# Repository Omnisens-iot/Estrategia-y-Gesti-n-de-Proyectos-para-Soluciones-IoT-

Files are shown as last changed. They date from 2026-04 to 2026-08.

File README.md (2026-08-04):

(https://postimg.cc/2VrdBDD4)

## Omnisens-Industrial Suite ##

OmniSens es un sistema orientado al monitoreo y control ambiental en entornos industriales. Utiliza sensores para medir variables críticas como temperatura, humedad, presión y luminosidad, y transmite estos datos mediante tecnología LoRa hacia un servidor en la nube, permitiendo monitoreo y gestión en tiempo real.

corte_modelo

🧑‍💻 Integrantes

| Nombre | GitHub |
|---|---|
| Fernando Gimenez Coria | [@FerCbr](https://github.com/FerCbr) |
| Paola Pantoja | [@PaolaaPantoja](https://github.com/PaolaaPantoja) |
| Diego Ares | [@diegote7](https://github.com/diegote7) |
| Macarena Aylèn Carballo | [@MacarenaAC](https://github.com/MacarenaAC) |
| Raul Jara | [@r-j28](https://github.com/r-j28) |
---
## Descripción General

El objetivo principal de OmniSens es implementar un sistema integral capaz de mantener condiciones óptimas de ambiente, garantizando la seguridad y calidad del aire. Para ello, el sistema incluye una serie de **controladores edge** que reciben los datos de los sensores y accionan dispositivos como extractores de aire, luces, alarmas sonoras y balizas luminosas.  
Las acciones de los controladores edge buscan regular parámetros ambientales: por ejemplo, ajustar la velocidad de extractores/ventiladores, la intensidad de luces, o activar alarmas cuando los valores de gases o variables ambientales sobrepasen los límites establecidos.

Los controladores edge se comunican mediante un enlace LoRa hacia otro controlador encargado de funcionar como **nodo concentrador**, formando una red de tipo estrella.  
Este **nodo concentrador** envia a su vez todos datos recolectados a un **broker MQTT** remoto para su posterior analisis y almacenamiento. Esta arquitectura otorga la posibilidad de implementar analisis de datos a nivel de edge, permitiendo reaccionar a variables criticas con baja latencia, sin dejar de lado el procesamiento en la nube, que se encarga de almacenar todos los sucesos y tambien enviar ordenes a los controladores Edge.   

Toda la información recolectada se analiza en un servidor remoto y es almacenada en una base de datos configurada para este fin, luego se procede a mostrar la informacion en un dashboard. Este diseño permite visualizar la informacion procesada a vez que puese enviar ordenes automaticas o comandos indicados por el usuario.

## Objetivo del Proyecto

Desarrollar un sistema capaz de:
- Monitorear variables ambientales (temperatura, humedad, presión, luminosidad, gases) en tiempo real.
- Controlar dispositivos para mantener condiciones ambientales dentro de los parámetros de seguridad y calidad.
- Automatizar acciones correctivas (ventilación, iluminación, alarmas) ante condiciones anómalas.
- Registrar, almacenar y visualizar los datos históricos y en tiempo real para facilitar la toma de decisiones.

---

## Arquitectura del Sistema  

(https://postimg.cc/HVhyV9CV)

El sistema está compuesto por:
- **Sensores ambientales**: Medición de variables críticas.  
- **Actuadores**: Dispositivos tales como Extractores/ventiladores, relay o contactores para comando on/off, balizas y alarmas sonoras
- **Microcontroladores Edge con LoRa**: Son los encargados de tomar la informacion de los sensores y procesar variables criticas que requieran baja latencia, ademas envian la informacion adquirida por enlace LoRa hacia el concentrador.
- **Concentrador Lora**: Controlador encargado de recibir los datos provenientes de los controladores Edge. Recibe la información y la envia por MQTT al **broker remoto**, ademas se encarga de ditribuir los comandos provenientes del servidor remoto hacia los **Controladores Edge** para accionar los actuadores.  
- **Servidor remoto**: Este servidor cumple las funciones de plataforma en la nube, cuenta con varios contenedores docker conectados en una red virtual. La lista de contenedores es la siguiente:  
    - **Broker MQTT**: recepcion de los datos provenientes del Edge y envio de comandos hacia los controladores edge  
    - **API**: Recibe los datos del broker MQTT y los procesa para autenticar y autorizar a los dispositivos y usuarios.  
    - **Node-red**: recibe los datos de la API y los procesa para analizar y tomar decisiones. Ademas, envía las reacciones a los actuadores a través de MQTT y almacena los datos y resultados de analisis en una base de datos.  
    - **Base de datos**: Aqui se almacena la informacion de los sensores, asi como los analisis realizados por Node-RED para su posterior visualizacion.  
    - **Grafana**: Grafana se utiliza para crear el dashboard encargado de mostrar los datos historicos y en tiempo real del sistema.
- **Interfaz web o dashboard**: Monitoreo y control centralizado.  

### Flujo de Datos

1. Los sensores captan variables ambientales.
2. Los datos viajan por LoRa a un microcontrolador concentrador, que se encarga a la vez de enviarlos por MQTT a un servidor remoto
3. El servidor analiza y devuelve ordenes para que los **Controladores Edge** accionen los actuadores.
4. El servidor almacena y muestra los datos en tiempo real, permitiendo monitoreo remoto y acciones automáticas.

---

(https://postimg.cc/BXPMk51p)

## Omnisens ##

## 🧭 1. Introducción y Problemática
**OmniSens** es un sistema de monitoreo y control ambiental industrial desarrollado por estudiantes del módulo **Estrategia y Gestión de Proyectos para Soluciones IoT**  del ISPC. Este proyecto integra tecnologías de hardware, software y comunicaciones para adquirir, almacenar, visualizar y actuar sobre datos ambientales críticos en tiempo real.

En entornos industriales, controlar variables como la **temperatura**, **humedad**, **presión atmosférica** y **luminosidad** es fundamental para garantizar la seguridad operativa, la eficiencia energética y el cumplimiento de normativas. Sin embargo, muchas industrias carecen de sistemas inteligentes que permitan:

- 📉 Monitoreo en tiempo real de las condiciones ambientales.
- ⚠️ Detección temprana de riesgos operativos.
- 📄 Registro y trazabilidad de datos históricos.
- 📊 Análisis automatizado y toma de decisiones basada en datos.
- 🚫 Evitar decisiones basadas en intuición o registros incompletos.

Ante este contexto, OmniSens surge como una solución tecnológica que permite:

Capturar datos desde sensores distribuidos mediante nodos IoT (ESP32).
Transmitir los datos a través de redes como LoRa y WiFi usando protocolos como MQTT.
Almacenarlos de forma estructurada en una base de datos relacional.
Visualizarlos y analizarlos en dashboards en tiempo real mediante herramientas como Grafana y NodeRed
Generar alertas automáticas y activar actuadores ante condiciones críticas.
El proyecto busca resolver necesidades concretas del sector industrial, promoviendo el desarrollo de competencias profesionales como la integración de sistemas embebidos, la conectividad IoT, la gestión de datos y la visualización inteligente.

Ante este contexto, **OmniSens** surge como una solución tecnológica que permite:

- Capturar datos desde sensores distribuidos mediante nodos IoT (ESP32).
- Transmitir los datos a través de redes como **LoRa** y **WiFi** usando protocolos como **MQTT**.
- Almacenarlos de forma estructurada en una base de datos relacional.
- Visualizarlos y analizarlos en dashboards en tiempo real mediante herramientas como **Grafana** y **NodeRed**
- Generar alertas automáticas y activar actuadores ante condiciones críticas.

El proyecto busca resolver necesidades concretas del sector industrial, promoviendo el desarrollo de competencias profesionales como la integración de sistemas embebidos, la conectividad IoT, la gestión de datos y la visualización inteligente.

> "OmniSens nace para transformar datos ambientales en decisiones inteligentes, aportando valor real a la industria a través de la tecnología."

## 🧱 2. Diseño de Arquitectura IoT
El sistema OmniSens está basado en una arquitectura IoT distribuida y escalable, compuesta por sensores físicos, nodos de adquisición (ESP32), un gateway central, servicios backend y plataformas de visualización. Su diseño busca asegurar confiabilidad, modularidad y bajo consumo energético.

### 🔧 Componentes principales de la arquitectura:

- **Sensores ambientales**: capturan variables como temperatura, humedad, presión y luminosidad.
- **Microcontroladores ESP32**: actúan como nodos sensores, adquiriendo y transmitiendo los datos.
- **Red de comunicación**: se utilizan tecnologías inalámbricas como **LoRa** (para distancias largas y bajo consumo) y **WiFi** (para conectividad local con el servidor).
- **Broker MQTT**: intermedia la comunicación entre nodos y backend.
- **Servidor Backend**: recibe, valida y almacena los datos en una base relacional (MySQL/MariaDB).
- **Base de datos**: registra las mediciones por timestamp, dispositivo y variable.
- **Dashboard de visualización**: mediante **Grafana** o/y **Node-Red**, permite observar en tiempo real el estado ambiental.

---
(https://postimg.cc/4HcrV1St)

### 🧩 Diagrama lógico de la arquitectura:

plaintext
[Sensores] 
    -> 
[ESP32 (Nodo Sensor)] 
    -> LoRa / WiFi 
[Gateway MQTT / Servidor] 
    -> 
[Base de Datos MySQL] 
    -> 
[Dashboard (Grafana / Power BI)]

---
## 🔧 3. Adquisición de Datos (ESP32 + Sensores)

La etapa de adquisición de datos en el sistema OmniSens se basa en la utilización de microcontroladores **ESP32**, que permiten la conexión directa con sensores ambientales y la recolección de datos físicos en tiempo real.

### 🔍 Variables monitoreadas:
- 🌡️ **Temperatura**
- 💧 **Humedad relativa**
- 🌀 **Presión atmosférica**
- 💡 **Luminosidad**
- 🕯️ **Concentracion de gases/ calidad de aire**

### 🛠️ Componentes utilizados:
- **Sensores digitales y analógicos**:
  - AHT25 → temperatura y humedad
  - BMP280 → presión y temperatura
  - LDR → luminosidad
  - MQ135 → Calidad de aire
    
- **Microcontrolador**:
  - ESP32 (con conectividad WiFi y/o LoRa)

### ⚙️ Flujo de funcionamiento:
1. Los sensores capturan datos del entorno físico.
2. El ESP32 lee las señales de los sensores a través de sus entradas GPIO.
3. El firmware del ESP32 convierte los datos a formato digital y los estructura en mensajes JSON.
4. Los datos se transmiten vía WiFi o LoRa hacia el backend o gateway.

### 🧪 Validación y pruebas realizadas:
- Lectura y calibración de cada sensor.
- Verificación del formato y frecuencia de los datos.
- Simulación de condiciones ambientales para validar variabilidad.
- Comprobación del consumo energético por nodo.

### 📌 Ventajas de usar ESP32:
- Bajo consumo energético.
- Capacidad de procesamiento local.
- Conectividad múltiple: WiFi, Bluetooth, LoRa (mediante módulos).
- Compatibilidad con entornos industriales y educativos.

> Esta etapa permite digitalizar el entorno físico y convertir condiciones ambientales en datos útiles, siendo el punto de partida del sistema de monitoreo y control de OmniSens.

---

## 📡 4. Comunicación Inalámbrica
La transmisión de datos en OmniSens se realiza mediante redes inalámbricas optimizadas para entornos industriales. Se utilizan dos tecnologías principales: **LoRa** y **WiFi**, complementadas por el protocolo **MQTT** para la mensajería entre dispositivos y el servidor.

### 🛰️ Tecnologías de comunicación utilizadas:

- **LoRa (Long Range)**:
  - Permite comunicación de largo alcance con bajo consumo energético.
  - Ideal para entornos con múltiples nodos distribuidos o con baja infraestructura de red.
  - Se utiliza principalmente entre nodos sensores y el nodo receptor (gateway).

- **WiFi**:
  - Usado en el nodo central para conectarse a internet y enviar los datos al backend.
  - Permite alta velocidad de transmisión y bajo retardo.

- **MQTT (Message Queuing Telemetry Transport)**:
  - Protocolo ligero ideal para IoT.
  - Permite que los dispositivos **publiquen** datos en un “topic” y que el servidor **se suscriba** para recibirlos.
  - Asegura eficiencia en redes de bajo ancho de banda y con múltiples dispositivos.

### 🔄 Flujo de comunicación:

[ESP32 Nodo Sensor]
  -> LoRa
[ESP32 Nodo Receptor / Gateway]
  -> MQTT sobre WiFi
[Broker MQTT]
  ->
[Servidor Backend]

---

## 🖥️ 5. Backend y Base de Datos
El backend del sistema OmniSens cumple un rol central en la recepción, validación, almacenamiento y organización de los datos ambientales enviados por los nodos sensores.

🔙 Funciones principales del backend:
Recibir datos desde los nodos mediante MQTT.
Validar formato, integridad y valores de los datos.
Registrar eventos o comandos generados por el sistema.
Almacenar toda la información en una base de datos relacional.
Exponer APIs para futuras integraciones con dashboards u otros servicios.
🗄️ Modelo de Base de Datos Relacional
Se diseñó una base de datos optimizada para registrar información ambiental por dispositivo y variable. Las tablas principales son:

| Tabla | Propósito |
|---|---|
| `devices` | Registra cada ESP32 con su ID, tipo y ubicación. |
| `sensor_data` | Almacena las mediciones de variables con timestamp. |
| `commands_log` | Guarda las acciones o respuestas generadas por el sistema (automatizaciones). |
| `alerts` *(opcional)* | Registra alertas generadas por condiciones críticas. |

#### 🔗 Relaciones entre tablas:
- `devices.device_id` → se relaciona con `sensor_data.device_id` y `commands_log.device_id`
- `sensor_data.id` → puede relacionarse con `alerts.sensor_data_id`

📈 Ventajas del diseño:
Escalable a nuevos sensores y tipos de variables.
Compatible con visualizadores como Grafana y Node-Red.
Preparado para trazabilidad, alertas y análisis histórico.
Este backend permite que los datos ambientales capturados por los sensores se conviertan en información estructurada, confiable y accesible para su posterior visualización y análisis.

📊 6. Visualización Web / Dashboard
La visualización de datos es el paso final del sistema OmniSens, donde la información almacenada en la base de datos es transformada en gráficos, paneles e indicadores comprensibles para facilitar la toma de decisiones.

📊 Integración con Node-RED y Grafana
Node-RED
Permite crear flujos lógicos para procesar, transformar y reenviar datos provenientes de sensores conectados vía MQTT.

🔧 Funcionalidades implementadas

* Recepción de datos desde ESP32 por MQTT.
* Filtrado y reenvío de datos a MariaDB.
* Reglas de control automático
* Flujo: MQTT → procesamiento → UI → actuador.
* Ruta: `/nodered_plata/ui/`: [Dashboard UI](http://telecomunicaciones.ddns.net:8080/nodered_plata/ui/#!/0)
* Incluye botones para control manual, recepción de datos, lógica de automatización.

### Grafana
* Plataforma de visualización en tiempo real, conectada directamente a la base de datos MariaDB.
* Dashboards visuales conectados a base de datos.
* Panel con temperatura, gas, humedad y estado de actuadores.
* Ruta directa:
  [Dashboard público](http://telecomunicaciones.ddns.net:8080/grafana/public-dashboards/edbcf99f6c3e44a68703f5246ecef087)

---

### 🧭 Objetivos de la visualización:
Representar variables ambientales críticas de forma clara y dinámica.
Permitir monitoreo en tiempo real de sensores distribuidos.
Detectar tendencias, anomalías o condiciones fuera de rango.
Mejorar el mantenimiento, la eficiencia energética y la seguridad operativa.
Facilitar el análisis por parte de diferentes perfiles de usuarios (técnicos, operativos, directivos).

### 🧱 Estructura del panel:
El dashboard se organiza en múltiples secciones:

1. **Vista general de variables**:
   - Temperatura, humedad, presión y luminosidad por dispositivo.
   - Estado actual, valores máximos y mínimos recientes.
2. **Medicion por eventos de valores en crudo**:
3. **Conteo de cantidad de dispositivos**:
4. **Históricos y tendencias**:
5. **Estado de sensores y actuadores**:
6. **Promedios** 
7. **Actividad de los reles**
8. **Identificador de dispositivos**

> La visualización convierte datos técnicos en información útil y clara, permitiendo interpretar el comportamiento ambiental y tomar decisiones informadas en entornos industriales.

---

## 🤖 7. Automatización y Control (Actuadores)
Además de monitorear el ambiente, el sistema OmniSens es capaz de actuar automáticamente ante condiciones críticas, gracias a la integración de actuadores controlados desde el backend o en forma autónoma por los nodos.

### ⚙️ Objetivos del control automatizado:
- Generar respuestas inmediatas ante variables fuera de rango.
- Activar dispositivos que mejoren las condiciones ambientales.
- Reducir la necesidad de intervención humana.
- Aumentar la seguridad y eficiencia operativa.

### 🔌 Tipos de actuadores posibles:

- 🌀 Ventiladores / extractores de aire.
- 💡 Luces de advertencia o balizas.
- 🔔 Alarmas sonoras.
- 💧 Válvulas o bombas de agua.
- 🌡️ Aire acondicionado o calefactores.

### 🔁 Lógica de automatización:

El sistema puede actuar de dos formas:

#### 1. **Automatización local en ESP32** (Opcional. no se implemento): 
- El ESP32 analiza el dato leído y, si supera un umbral, activa directamente el actuador conectado.
- Ejemplo: si `temperatura > 30°C`, activar ventilador.

#### 2. **Automatización centralizada desde el backend**:
- El servidor recibe los datos y decide activar o no un actuador según reglas definidas.
- Se envía un comando vía MQTT al nodo actuador correspondiente.

### 🗂️ Registro de acciones:

- Cada acción ejecutada se guarda en la tabla `commands_log`, con información como:
  - `device_id`
  - `command` (ej. "ON", "OFF")
  - `timestamp`
  - `status`

### 🧪 Validación y pruebas:

- Ensayos de latencia entre detección y acción.
- Pruebas con sensores simulados y actuadores reales.
- Comprobación de fallos: qué ocurre si el actuador no responde.

> La automatización convierte al sistema en una herramienta activa, no solo de monitoreo, sino también de respuesta inteligente ante condiciones que afectan el ambiente de trabajo.

---
## 📅 8. Cronograma y Proceso de Desarrollo

El desarrollo del proyecto OmniSens se organizó en etapas, siguiendo una planificación basada en objetivos específicos y acciones técnicas. Esto permitió avanzar de forma progresiva, validando cada componente del sistema antes de integrarlo.

### 📌 Organización por semanas

| Etapa | Objetivo principal | Acciones realizadas |
|---|---|---|
| **Etapa 1** | Diseñar la arquitectura | - Análisis de necesidades del sistema<br>- Selección de topología IoT<br>- Definición de roles: sensores, nodos, gateway, servidor<br>- Primeros diagramas de arquitectura |
| **Etapa  2** | Adquisición de datos | - Conexión de sensores al ESP32<br>- Programación de firmware básico<br>- Pruebas de lectura y calibración<br>- Validación de datos físicos |
| **Etapa  3** | Comunicación inalámbrica | - Configuración de red LoRa y WiFi<br>- Implementación de MQTT/<br>- Pruebas de transmisión nodo → servidor<br>- Ajustes de cobertura y latencia |
| **Etapa  4** | Backend y base de datos | - Diseño de la base de datos relacional<br>- Creación de APIs de recepción<br>- Almacenamiento de datos desde nodos<br>- Gestión de errores y alertas |
| **Etapa  5** | Visualización y pruebas finales | - Diseño del dashboard (Grafana / Node-Red)<br>- Conexión al backend y base de datos<br>- Visualización de datos en tiempo real<br>- Revisión, ajustes y documentación final |

### 🛠️ Metodología aplicada:

- Trabajo colaborativo entre 9 integrantes, con roles distribuidos.
- Validación continua en cada etapa (sensado, transmisión, backend, visualización).
- Uso de control de versiones (GitHub) para gestionar avances y código.
- Documentación técnica elaborada de forma simultánea al desarrollo.

### 📈 Resultados destacados:

- Se logró un sistema funcional y escalable.
- Todas las etapas del ciclo de vida de los datos fueron cubiertas: captura, transmisión, almacenamiento, análisis y visualización.
- Se presentaron avances periódicos en cada instancia del módulo FullStack IoT.

> El trabajo organizado y en equipo fue clave para alcanzar un producto sólido, demostrando competencias técnicas y metodológicas aplicadas al desarrollo de sistemas IoT reales.

---
## 💰 9. Modelo de Negocio

OmniSens adopta un modelo híbrido:

- Suscripción mensual (SaaS)
- Servicios de análisis para empresas
- Plataforma para integración con terceros

Segmentos:
- Residencial
- Corporativo (B2B)
- Gobierno / Smart Cities

---

## 🔐 Seguridad

Se implementan medidas de seguridad en múltiples niveles:

- Protección de credenciales
- Cifrado en comunicaciones (TLS/SSL)
- Autenticación en API
- Validación de datos
- Análisis de vulnerabilidades

---

## ⚠️ Gestión de Riesgos

Se identifican riesgos técnicos, operativos y de seguridad con estrategias de mitigación.

---

## 🚀 Estado del Proyecto

Actualmente en desarrollo bajo metodología ágil con backlog estructurado y tareas en ejecución.

---
## ✅ 10. Conclusión, Aplicaciones y Cierre

OmniSens es el resultado de un trabajo colaborativo y multidisciplinario que integra tecnologías de IoT, comunicaciones, desarrollo de software y análisis de datos para resolver una problemática concreta del ámbito industrial: la necesidad de monitorear y controlar variables ambientales de forma precisa y en tiempo real, optimizando el sistema, brindando soluciones reales ejecutando acciones o actividades   lo mas desatendidas y seguras posibles. 

### 🎯 Logros alcanzados:

- Desarrollo de un sistema completo y funcional.
- Integración de sensores físicos y nodos ESP32 con conectividad LoRa/WiFi.
- Implementación de un backend capaz de recibir, validar y almacenar datos.
- Construcción de dashboards interactivos para visualización en tiempo real.
- Automatización de respuestas ante condiciones críticas.
- Trabajo en equipo con documentación técnica, planificación y uso de herramientas profesionales.

### 🏭 Posibles aplicaciones reales:

- **Industria manufacturera**: monitoreo ambiental en líneas de producción.
- **Centros educativos o de investigación**: como plataforma de aprendizaje IoT.
- **Agricultura inteligente**: control ambiental en invernaderos o hidroponía.
- **Municipios**: estaciones ambientales urbanas para políticas públicas.
- **Cooperativas o pymes**: bajo costo, alta utilidad para la toma de decisiones.

### 🌱 Impacto del proyecto:

- Promueve la **conciencia ambiental industrial**.
- Desarrolla habilidades reales del perfil técnico FullStack IoT.
- Facilita la **transferencia tecnológica** a contextos locales.
- Aporta una solución escalable, replicable y con impacto social.

### 🧠 Reflexión final:

> “OmniSens no solo mide condiciones ambientales. Permite que la industria tome decisiones más inteligentes, eficientes y sostenibles. Nos permitió aplicar conocimientos concretos de arquitectura IoT, plataformas web, sistemas de control y gestión de datos, demostrando cómo la tecnología puede mejorar entornos reales.”

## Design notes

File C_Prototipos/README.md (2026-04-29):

(https://postimg.cc/BXPMk51p)

## OmniSens IoT – Sistema Orientado al Monitoreo y Control Ambiental en Entornos Industriales ##

**OmniSens** es un sistema orientado al monitoreo y control ambiental en entornos industriales. Utiliza sensores para medir variables críticas como temperatura, humedad, presión y luminosidad, y transmite estos datos mediante tecnología **LoRa** hacia un servidor en la nube, permitiendo monitoreo y gestión en tiempo real.

---

## 🧑‍💻 Integrantes

| Nombre | GitHub |
|---|---|
| Fernando Gimenez Coria | [@FerCbr](https://github.com/FerCbr) |
| Paola Pantoja | [@PaolaaPantoja](https://github.com/PaolaaPantoja) |
| Diego Ares | [@diegote7](https://github.com/diegote7) |
| Macarena Aylèn Carballo | [@MacarenaAC](https://github.com/MacarenaAC) |
| Raul Jara | [@r-j28](https://github.com/r-j28) |
---

## 👨‍🏫 Profesores

| Nombre | GitHub |
|---|---|
| Mario Gonzalez | [@mariogonzalezispc](https://github.com/mariogonzalezispc) |
| Ana Farias | |
| Dante Violi | |
| Alejandro DI Marco | |

## Descripción General

El objetivo principal de OmniSens es implementar un sistema integral capaz de mantener condiciones óptimas de ambiente, garantizando la seguridad y calidad del aire. Para ello, el sistema incluye una serie de **controladores edge** que reciben los datos de los sensores y accionan dispositivos como extractores de aire, luces, alarmas sonoras y balizas luminosas.  
Las acciones de los controladores edge buscan regular parámetros ambientales: por ejemplo, ajustar la velocidad de extractores/ventiladores, la intensidad de luces, o activar alarmas cuando los valores de gases o variables ambientales sobrepasen los límites establecidos.

Los controladores edge se comunican mediante un enlace LoRa hacia otro controlador encargado de funcionar como **nodo concentrador**, formando una red de tipo estrella.  
Este **nodo concentrador** envia a su vez todos datos recolectados a un **broker MQTT** remoto para su posterior analisis y almacenamiento. Esta arquitectura otorga la posibilidad de implementar analisis de datos a nivel de edge, permitiendo reaccionar a variables criticas con baja latencia, sin dejar de lado el procesamiento en la nube, que se encarga de almacenar todos los sucesos y tambien enviar ordenes a los controladores Edge.   

Toda la información recolectada se analiza en un servidor remoto y es almacenada en una base de datos configurada para este fin, luego se procede a mostrar la informacion en un dashboard. Este diseño permite visualizar la informacion procesada a su vez que puede enviar ordenes automaticas o comandos indicados por el usuario.

El proyecto busca aprovechar prototipos y desarrollos previos, adaptando y escalando el enfoque hacia la gestión ambiental industrial. Además, se promueve el trabajo colaborativo y la comunicación de avances con los profesores para su evaluación.

---
## 🧭 1. Introducción y Problemática

**OmniSens** es un sistema de monitoreo y control ambiental industrial desarrollado por estudiantes del módulo **Programador FullStack IoT** del ISPC. Este proyecto integra tecnologías de hardware, software y comunicaciones para adquirir, almacenar, visualizar y actuar sobre datos ambientales críticos en tiempo real.

En entornos industriales, controlar variables como la **temperatura**, **humedad**, **presión atmosférica** y **luminosidad** es fundamental para garantizar la seguridad operativa, la eficiencia energética y el cumplimiento de normativas. Sin embargo, muchas industrias carecen de sistemas inteligentes que permitan:

- 📉 Monitoreo en tiempo real de las condiciones ambientales.
- ⚠️ Detección temprana de riesgos operativos.
- 📄 Registro y trazabilidad de datos históricos.
- 📊 Análisis automatizado y toma de decisiones basada en datos.
- 🚫 Evitar decisiones basadas en intuición o registros incompletos.

Ante este contexto, **OmniSens** surge como una solución tecnológica que permite:

- Capturar datos desde sensores distribuidos mediante nodos IoT (ESP32).
- Transmitir los datos a través de redes como **LoRa** y **WiFi** usando protocolos como **MQTT**.
- Almacenarlos de forma estructurada en una base de datos relacional.
- Visualizarlos y analizarlos en dashboards en tiempo real mediante herramientas como **Grafana** y **NodeRed**
- Generar alertas automáticas y activar actuadores ante condiciones críticas.

El proyecto busca resolver necesidades concretas del sector industrial, promoviendo el desarrollo de competencias profesionales como la integración de sistemas embebidos, la conectividad IoT, la gestión de datos y la visualización inteligente.

> "OmniSens nace para transformar datos ambientales en decisiones inteligentes, aportando valor real a la industria a través de la tecnología."

---
## 🧱 2. Diseño de Arquitectura IoT

El sistema OmniSens está basado en una arquitectura IoT distribuida y escalable, compuesta por sensores físicos, nodos de adquisición (ESP32), un gateway central, servicios backend y plataformas de visualización. Su diseño busca asegurar confiabilidad, modularidad y bajo consumo energético.

### 🔧 Componentes principales de la arquitectura:

- **Sensores ambientales**: capturan variables como temperatura, humedad, presión y luminosidad.
- **Microcontroladores ESP32**: actúan como nodos sensores, adquiriendo y transmitiendo los datos.
- **Red de comunicación**: se utilizan tecnologías inalámbricas como **LoRa** (para distancias largas y bajo consumo) y **WiFi** (para conectividad local con el servidor).
- **Broker MQTT**: intermedia la comunicación entre nodos y backend.
- **Servidor Backend**: recibe, valida y almacena los datos en una base relacional (MySQL/MariaDB).
- **Base de datos**: registra las mediciones por timestamp, dispositivo y variable.
- **Dashboard de visualización**: mediante **Grafana** o/y **Node-Red**, permite observar en tiempo real el estado ambiental.

---
### 🧩 Diagrama lógico de la arquitectura:

plaintext
[Sensores] 
    ↓ 
[ESP32 (Nodo Sensor)] 
    ↓ LoRa / WiFi 
[Gateway MQTT / Servidor] 
    ↓ 
[Base de Datos MySQL] 
    ↓ 
[Dashboard (Grafana / Power BI)]

---
## 🔧 3. Adquisición de Datos (ESP32 + Sensores)

La etapa de adquisición de datos en el sistema OmniSens se basa en la utilización de microcontroladores **ESP32**, que permiten la conexión directa con sensores ambientales y la recolección de datos físicos en tiempo real.

### 🔍 Variables monitoreadas:
- 🌡️ **Temperatura**
- 💧 **Humedad relativa**
- 🌀 **Presión atmosférica**
- 💡 **Luminosidad**

### 🛠️ Componentes utilizados:
- **Sensores digitales y analógicos**:
  - DHT11 → temperatura y humedad
  - BMP280 → presión
  - BH1750 → luminosidad
- **Microcontrolador**:
  - ESP32 (con conectividad WiFi y/o LoRa)

### ⚙️ Flujo de funcionamiento:
1. Los sensores capturan datos del entorno físico.
2. El ESP32 lee las señales de los sensores a través de sus entradas GPIO.
3. El firmware del ESP32 convierte los datos a formato digital y los estructura en mensajes JSON.
4. Los datos se transmiten vía WiFi o LoRa hacia el backend o gateway.

### 🧪 Validación y pruebas realizadas:
- Lectura y calibración de cada sensor.
- Verificación del formato y frecuencia de los datos.
- Simulación de condiciones ambientales para validar variabilidad.
- Comprobación del consumo energético por nodo.

### 📌 Ventajas de usar ESP32:
- Bajo consumo energético.
- Capacidad de procesamiento local.
- Conectividad múltiple: WiFi, Bluetooth, LoRa (mediante módulos).
- Compatibilidad con entornos industriales y educativos.

> Esta etapa permite digitalizar el entorno físico y convertir condiciones ambientales en datos útiles, siendo el punto de partida del sistema de monitoreo y control de OmniSens.

---
## 📡 4. Comunicación Inalámbrica

La transmisión de datos en OmniSens se realiza mediante redes inalámbricas optimizadas para entornos industriales. Se utilizan dos tecnologías principales: **LoRa** y **WiFi**, complementadas por el protocolo **MQTT** para la mensajería entre dispositivos y el servidor.

### 🛰️ Tecnologías de comunicación utilizadas:

- **LoRa (Long Range)**:
  - Permite comunicación de largo alcance con bajo consumo energético.
  - Ideal para entornos con múltiples nodos distribuidos o con baja infraestructura de red.
  - Se utiliza principalmente entre nodos sensores y el nodo receptor (gateway).

- **WiFi**:
  - Usado en el nodo central para conectarse a internet y enviar los datos al backend.
  - Permite alta velocidad de transmisión y bajo retardo.

- **MQTT (Message Queuing Telemetry Transport)**:
  - Protocolo ligero ideal para IoT.
  - Permite que los dispositivos **publiquen** datos en un “topic” y que el servidor **se suscriba** para recibirlos.
  - Asegura eficiencia en redes de bajo ancho de banda y con múltiples dispositivos.

### 🔄 Flujo de comunicación:

plaintext
[ESP32 Nodo Sensor]
  ↓ LoRa
[ESP32 Nodo Receptor / Gateway]
  ↓ MQTT sobre WiFi
[Broker MQTT]
  ↓
[Servidor Backend]

---
## 🖥️ 5. Backend y Base de Datos

El backend del sistema OmniSens cumple un rol central en la recepción, validación, almacenamiento y organización de los datos ambientales enviados por los nodos sensores.

### 🔙 Funciones principales del backend:

- Recibir datos desde los nodos mediante HTTP o MQTT.
- Validar formato, integridad y valores de los datos.
- Registrar eventos o comandos generados por el sistema.
- Almacenar toda la información en una base de datos relacional.
- Exponer APIs para futuras integraciones con dashboards u otros servicios.

### 🧩 Arquitectura del backend:

- **Lenguaje/entorno**: Node.js
- **Servidor web/API**: Express
- **Base de datos**: MariaDB / MySQL
- **Gestión de datos**: Sequelize u ORM nativo
- **Contenedores**: Docker (opcional, según implementación)

### 🗄️ Modelo de Base de Datos Relacional

Se diseñó una base de datos optimizada para registrar información ambiental por dispositivo y variable. Las tablas principales son:

| Tabla | Propósito |
|---|---|
| `devices` | Registra cada ESP32 con su ID, tipo y ubicación. |
| `sensor_data` | Almacena las mediciones de variables con timestamp. |
| `commands_log` | Guarda las acciones o respuestas generadas por el sistema (automatizaciones). |
| `alerts` *(opcional)* | Registra alertas generadas por condiciones críticas. |

#### 🔗 Relaciones entre tablas:
- `devices.device_id` → se relaciona con `sensor_data.device_id` y `commands_log.device_id`
- `sensor_data.id` → puede relacionarse con `alerts.sensor_data_id`

### 🧪 Validaciones implementadas:

- Comprobación de rangos válidos (ej.: temperatura entre -40 °C y 85 °C).
- Eliminación de registros duplicados.
- Control de campos nulos o mal formateados.
- Registro de errores y eventos especiales.

### 📈 Ventajas del diseño:

- Escalable a nuevos sensores y tipos de variables.
- Compatible con visualizadores como Grafana y Power BI.
- Preparado para trazabilidad, alertas y análisis histórico.

> Este backend permite que los datos ambientales capturados por los sensores se conviertan en información estructurada, confiable y accesible para su posterior visualización y análisis.

---
## 📊 6. Visualización Web / Dashboard

La visualización de datos es el paso final del sistema OmniSens, donde la información almacenada en la base de datos es transformada en gráficos, paneles e indicadores comprensibles para facilitar la toma de decisiones.

## 📊 Integración con Node-RED y Grafana

### Node-RED

* Flujo: MQTT → procesamiento → UI → actuador.
* Ruta: `/nodered_plata/ui/`: [Dashboard UI](http://telecomunicaciones.ddns.net:8080/nodered_plata/ui/#!/0)
* Incluye botones para control manual, recepción de datos, lógica de automatización.

### Grafana

* Plataforma de visualización en tiempo real, conectada directamente a la base de datos MySQL.
* Dashboards visuales conectados a base de datos.
* Panel con temperatura, gas, humedad y estado de actuadores.
* Ruta directa:
  [Dashboard público](http://telecomunicaciones.ddns.net:8080/grafana/public-dashboards/edbcf99f6c3e44a68703f5246ecef087)

---

### 🧭 Objetivos de la visualización:

- Representar variables ambientales críticas de forma clara y dinámica.
- Permitir monitoreo en tiempo real de sensores distribuidos.
- Detectar tendencias, anomalías o condiciones fuera de rango.
- Mejorar el mantenimiento, la eficiencia energética y la seguridad operativa.
- Facilitar el análisis por parte de diferentes perfiles de usuarios (técnicos, operativos, directivos).

### 🧱 Estructura del panel:

El dashboard se organiza en múltiples secciones:

1. **Vista general de variables**:
   - Temperatura, humedad, presión y luminosidad por dispositivo.
   - Estado actual, valores máximos y mínimos recientes.

2. **Panel comparativo por sectores o nodos**:
   - Comparación de valores entre ubicaciones o dispositivos.

3. **Alertas y condiciones críticas**:
   - Visualización de alertas activas por umbrales excedidos.

4. **Históricos y tendencias**:
   - Gráficos de evolución temporal de cada variable.
   - Filtros por fecha, nodo o variable.

5. **Indicadores clave (KPIs)**:
   - Promedios, máximos/mínimos diarios.
   - Cantidad de alertas, condiciones óptimas mantenidas, etc.

### 🔗 Conexión de datos:

- **Grafana**: se conecta directamente a la base MySQL mediante consultas SQL configuradas por variable y tabla.
- **Power BI**: importa los datos desde MySQL o desde archivos exportados, permitiendo modelado, limpieza y relaciones personalizadas.

> La visualización convierte datos técnicos en información útil y clara, permitiendo interpretar el comportamiento ambiental y tomar decisiones informadas en entornos industriales.

---
## 🤖 7. Automatización y Control (Actuadores)

Además de monitorear el ambiente, el sistema OmniSens es capaz de **actuar automáticamente** ante condiciones críticas, gracias a la integración de actuadores controlados desde el backend o en forma autónoma por los nodos.

### ⚙️ Objetivos del control automatizado:

- Generar respuestas inmediatas ante variables fuera de rango.
- Activar dispositivos que mejoren las condiciones ambientales.
- Reducir la necesidad de intervención humana.
- Aumentar la seguridad y eficiencia operativa.

### 🔌 Tipos de actuadores posibles:

- 🌀 Ventiladores / extractores de aire.
- 💡 Luces de advertencia o balizas.
- 🔔 Alarmas sonoras.
- 💧 Válvulas o bombas de agua.
- 🌡️ Aire acondicionado o calefactores.

### 🔁 Lógica de automatización:

El sistema puede actuar de dos formas:

#### 1. **Automatización local en ESP32**:
- El ESP32 analiza el dato leído y, si supera un umbral, activa directamente el actuador conectado.
- Ejemplo: si `temperatura > 30°C`, activar ventilador.

#### 2. **Automatización centralizada desde el backend**:
- El servidor recibe los datos y decide activar o no un actuador según reglas definidas.
- Se envía un comando vía MQTT/HTTP al nodo actuador correspondiente.

### 🗂️ Registro de acciones:

- Cada acción ejecutada se guarda en la tabla `commands_log`, con información como:
  - `device_id`
  - `command` (ej. "ON", "OFF")
  - `timestamp`
  - `status`

### 🧪 Validación y pruebas:

- Ensayos de latencia entre detección y acción.
- Pruebas con sensores simulados y actuadores reales.
- Comprobación de fallos: qué ocurre si el actuador no responde.

### 🔒 Seguridad:

- Se pueden establecer reglas para evitar activaciones innecesarias.
- Control de prioridad y bloqueo si hay condiciones simultáneas.

> La automatización convierte al sistema en una herramienta activa, no solo de monitoreo, sino también de respuesta inteligente ante condiciones que afectan el ambiente de trabajo.

---
## 📅 8. Cronograma y Proceso de Desarrollo

El desarrollo del proyecto OmniSens se organizó en etapas semanales, siguiendo una planificación basada en objetivos específicos y acciones técnicas. Esto permitió avanzar de forma progresiva, validando cada componente del sistema antes de integrarlo.

### 📌 Organización por semanas

| Semana | Objetivo principal | Acciones realizadas |
|---|---|---|
| **Semana 1** | Diseñar la arquitectura | - Análisis de necesidades del sistema<br>- Selección de topología IoT<br>- Definición de roles: sensores, nodos, gateway, servidor<br>- Primeros diagramas de arquitectura |
| **Semana 2** | Adquisición de datos | - Conexión de sensores al ESP32<br>- Programación de firmware básico<br>- Pruebas de lectura y calibración<br>- Validación de datos físicos |
| **Semana 3** | Comunicación inalámbrica | - Configuración de red LoRa y WiFi<br>- Implementación de MQTT/HTTP<br>- Pruebas de transmisión nodo → servidor<br>- Ajustes de cobertura y latencia |
| **Semana 4** | Backend y base de datos | - Diseño de la base de datos relacional<br>- Creación de APIs de recepción<br>- Almacenamiento de datos desde nodos<br>- Gestión de errores y alertas |
| **Semana 5** | Visualización y pruebas finales | - Diseño del dashboard (Grafana / Power BI)<br>- Conexión al backend y base de datos<br>- Visualización de datos en tiempo real<br>- Revisión, ajustes y documentación final |

### 🛠️ Metodología aplicada:

- Trabajo colaborativo entre 9 integrantes, con roles distribuidos.
- Validación continua en cada etapa (sensado, transmisión, backend, visualización).
- Uso de control de versiones (GitHub) para gestionar avances y código.
- Documentación técnica elaborada de forma simultánea al desarrollo.

### 📈 Resultados destacados:

- Se logró un sistema funcional y escalable.
- Todas las etapas del ciclo de vida de los datos fueron cubiertas: captura, transmisión, almacenamiento, análisis y visualización.
- Se presentaron avances periódicos en cada instancia del módulo FullStack IoT.

> El trabajo organizado y en equipo fue clave para alcanzar un producto sólido, demostrando competencias técnicas y metodológicas aplicadas al desarrollo de sistemas IoT reales.

---
## ✅ 9. Conclusión, Aplicaciones y Cierre

OmniSens es el resultado de un trabajo colaborativo y multidisciplinario que integra tecnologías de IoT, comunicaciones, desarrollo de software y análisis de datos para resolver una problemática concreta del ámbito industrial: la necesidad de monitorear y controlar variables ambientales de forma precisa y en tiempo real.

### 🎯 Logros alcanzados:

- Desarrollo de un sistema completo y funcional.
- Integración de sensores físicos y nodos ESP32 con conectividad LoRa/WiFi.
- Implementación de un backend capaz de recibir, validar y almacenar datos.
- Construcción de dashboards interactivos para visualización en tiempo real.
- Automatización de respuestas ante condiciones críticas.
- Trabajo en equipo con documentación técnica, planificación y uso de herramientas profesionales.

### 🏭 Posibles aplicaciones reales:

- **Industria manufacturera**: monitoreo ambiental en líneas de producción.
- **Centros educativos o de investigación**: como plataforma de aprendizaje IoT.
- **Agricultura inteligente**: control ambiental en invernaderos o hidroponía.
- **Municipios**: estaciones ambientales urbanas para políticas públicas.
- **Cooperativas o pymes**: bajo costo, alta utilidad para la toma de decisiones.

### 🌱 Impacto del proyecto:

- Promueve la **conciencia ambiental industrial**.
- Desarrolla habilidades reales del perfil técnico FullStack IoT.
- Facilita la **transferencia tecnológica** a contextos locales.
- Aporta una solución escalable, replicable y con impacto social.

### 🧠 Reflexión final:

> “OmniSens no solo mide condiciones ambientales. Permite que la industria tome decisiones más inteligentes, eficientes y sostenibles. Nos permitió aplicar conocimientos concretos de arquitectura IoT, plataformas web, sistemas de control y gestión de datos, demostrando cómo la tecnología puede mejorar entornos reales.”

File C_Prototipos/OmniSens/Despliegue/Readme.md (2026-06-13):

# 🚀 Guía de Despliegue Paso a Paso (Nube Híbrida) - OmniSens

Esta guía describe el procedimiento detallado para transferir los archivos de orquestación desde tu computadora local hacia la **Raspberry Pi (Nodo de Control)** y posteriormente ejecutar el despliegue automatizado en la **Netbook Atom (Servidor Local)** y en la **instancia EC2 de AWS (Servidor en la Nube)**.

---

## 🗺️ Arquitectura de Despliegue Híbrido

```mermaid
graph TD
    PC[PC de Desarrollo (Local)] -->|1. Transferir Archivos (SCP)| RPi[Raspberry Pi (Nodo de Control con Ansible)]
    RPi -->|2. Despliegue local (SSH)| Netbook[Netbook Atom (Servidor Local - Red Interna)]
    RPi -->|3. Despliegue nube (SSH + PEM)| AWS[AWS EC2 (Servidor de Producción en Nube)]
```

---

## 📋 Requisitos Previos

Antes de comenzar, asegúrate de contar con:
1. La clave privada `.pem` de AWS en tu Raspberry Pi (o lista en tu PC para transferirla).
2. Los accesos SSH habilitados tanto en la Netbook Atom como en la instancia EC2.
3. Ansible instalado en la Raspberry Pi.

---

## 🛠️ Paso a Paso del Despliegue

### Paso 1: Copiar los Archivos de Despliegue a la Raspberry Pi
Debido a que estás trabajando en tu PC local, debes transferir la carpeta de despliegue (`Despliegue/`) y la carpeta de configuraciones de Nginx (`configuraciones/`) a la Raspberry Pi.

Abre una terminal (PowerShell o Git Bash) en tu PC local en la raíz del proyecto `OmniSens/` y ejecuta el comando `scp`:

```bash
# Copia ambas carpetas al home del usuario 'pi' en la Raspberry Pi
# (Reemplaza <IP_RASPBERRY> con la dirección IP real de tu Raspberry Pi)
scp -r Despliegue/ configuraciones/ pi@<IP_RASPBERRY>:/home/pi/omnisens_deploy/
```

> [!TIP]
> Si tu clave `.pem` de AWS está en la PC local, aprovecha para enviarla también a la Raspberry Pi:
> `scp ruta/de/tu/clave.pem pi@<IP_RASPBERRY>:/home/pi/.ssh/omnisens-aws.pem`

---

### Paso 2: Conectarse y Configurar la Raspberry Pi
Conéctate por SSH a la Raspberry Pi:
```bash
ssh pi@<IP_RASPBERRY>
cd /home/pi/omnisens_deploy/Despliegue/
```

Si aún no tienes la clave `.pem` en la ubicación correcta o con los permisos adecuados en la Pi, ejecuta:
```bash
# Mover la llave y ajustar permisos para que SSH la acepte
chmod 400 /home/pi/.ssh/omnisens-aws.pem
```

---

### Paso 3: Configurar el Inventario (`inventory.ini`)
Abre el archivo de inventario en la Raspberry Pi para editarlo (por ejemplo, con `nano inventory.ini`) y completa las direcciones IP reales:

```ini
[nodos_atom]
# Servidor local
netbook_local ansible_host=<IP_NETBOOK_LOCAL> ansible_user=fernandogc

[nodos_aws]
# Servidor en la nube
aws_ec2 ansible_host=<IP_PUBLICA_AWS> ansible_user=ubuntu ansible_ssh_private_key_file=/home/pi/.ssh/omnisens-aws.pem
```

> [!NOTE]
> Si la instancia de AWS corre **Amazon Linux 2 / RHEL** en lugar de **Ubuntu**, debes cambiar `ansible_user=ubuntu` por `ansible_user=ec2-user`.

---

### Paso 4: Validar Conectividad desde Ansible
Antes de desplegar, verifica que la Raspberry Pi pueda comunicarse mediante Ansible con ambos servidores:

```bash
# Realiza un ping de Ansible a todos los nodos del inventario
ansible -i inventory.ini all -m ping
```
*Si todo está bien, deberías ver una respuesta en color verde (`SUCCESS`) para ambos nodos.*

---

### Paso 5: Ejecutar el Playbook de Despliegue
Ejecuta el despliegue automático. Este comando aprovisionará la instancia de AWS (instalando Docker, Compose y Git) y luego compilará/levantará el stack en ambos entornos:

```bash
ansible-playbook -i inventory.ini deploy_aqi.yml
```

---

## 🔍 Paso 6: Verificación de los Microservicios

### En el Entorno Local (Netbook Atom)
1. Conéctate a la netbook y verifica que los contenedores estén corriendo:
   ```bash
   docker ps
   ```
2. Asegúrate de que la red externa `omni_agro_omnisens_net` esté activa y contenga los contenedores:
   ```bash
   docker network inspect omni_agro_omnisens_net
   ```
3. El frontend de la netbook no expone puertos externos al host, por lo que el tráfico web debe ingresar a través de tu Nginx Maestro en el puerto `80/443` utilizando la plantilla `configuraciones/aqi.conf.j2`.

### En el Entorno de AWS
1. Conéctate a la instancia de AWS y confirma los contenedores:
   ```bash
   docker ps
   ```
   *Deberías ver los puertos expuestos (ej. `0.0.0.0:80->80/tcp` para el frontend y los puertos de EMQX).*
2. Abre tu navegador y accede al Dashboard ingresando la IP pública de AWS:
   `http://<IP_PUBLICA_AWS>`
3. Verifica el acceso al panel de administración de EMQX:
   `http://<IP_PUBLICA_AWS>:18083` (Usuario por defecto: `admin` / Clave: `public`).

---
> [!IMPORTANT]
> **Seguridad en AWS:** Asegúrate de abrir los puertos de entrada (`80`, `1883`, `8883` y `18083` para administración) en el **Security Group (Grupo de Seguridad)** asociado a tu instancia EC2 en la consola de AWS para permitir las conexiones externas.

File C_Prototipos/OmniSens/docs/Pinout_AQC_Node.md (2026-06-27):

# Documentación de Hardware: Asignación de Pines (Pinout)
**Dispositivo:** Nodo OmniSens AQC (Air Quality & Control)
**Microcontrolador:** ESP32 (WROOM-32)

Este documento detalla la asignación de puertos GPIO (General Purpose Input/Output) configurada en el firmware base (`main.cpp`) para conectar todos los sensores y actuadores físicos del Nodo AQC.

---

## 1. Bus I2C (Sensores Digitales)
El bus I2C está configurado en los pines estándar del ESP32. Todos los siguientes sensores deben conectarse en paralelo a estos dos pines, utilizando la alimentación correspondiente (generalmente 3.3V).

| Función | ESP32 GPIO | Sensores Conectados en el Bus |
| :--- | :---: | :--- |
| **SDA (Data)** | **GPIO 21** | AHT25, BMP280, BH1750 |
| **SCL (Clock)**| **GPIO 22** | AHT25, BMP280, BH1750 |

---

## 2. Entradas Analógicas (Sensores ADC)
Los siguientes sensores analógicos deben conectarse a los pines ADC (Conversor Analógico a Digital) del ESP32. Todos los pines seleccionados (`34`, `35`, `36`, `39`) son seguros para lectura analógica y no interfieren con el arranque del módulo (WiFi/Boot).

| Sensor / Función | ESP32 GPIO | Etiqueta en Placa | Notas |
| :--- | :---: | :---: | :--- |
| **LDR** (Fotorresistencia) | **GPIO 36** | `VP` / `SENSOR_VP` | **Topología recomendada para 0dB (0 a 1V):** `3.3V` -> **Resistencia 22kΩ** -> `[Nodo GPIO 36]` -> **LDR en paralelo con Resistencia 10kΩ** -> `GND`. Esto asegura que el pin jamás supere 1.03V en oscuridad total y baje a ~0V en luz plena. |
| **MQ-135** (Calidad de Aire) | **GPIO 39** | `VN` / `SENSOR_VN` | **Conexión Directa con Protección:** Dado que el módulo tiene un RL de 1kΩ, su salida (AOUT) será de milivoltios. **NO usar divisor resistivo**. Conectar `AOUT` -> **Resistencia 10kΩ en serie** -> `GPIO 39`. (La resistencia de 10kΩ protege al ESP32 por si el sensor falla y saca 5V). |
| **Sharp PM10** (AOUT) | **GPIO 34** | `34` | Salida del sensor óptico. Divisor resistivo recomendado: **33kΩ + 5.6kΩ** (aprox. 39kΩ) y 10kΩ GND. |
| **Monitor de Batería** | **GPIO 35** | `35` | Divisor para 4.2V a <1V (0dB). Resistencias usadas: **22kΩ + 5.6kΩ** (aprox. 27kΩ) hacia BAT, 10kΩ GND. |

---

## 3. Salidas Digitales / Actuadores
Estos pines están configurados como salidas para controlar hardware de potencia (mediante relés o transistores).

| Componente | ESP32 GPIO | Etiqueta | Función |
| :--- | :---: | :---: | :--- |
| **Relé 1** | **GPIO 33** | `33` | Control digital (ON/OFF) de potencia. |
| **Relé 2** | **GPIO 25** | `25` | Control digital (ON/OFF) de potencia. |
| **Salida PWM** | **GPIO 32** | `32` | Control de velocidad variable (ej. Actuador externo, dimer). Controlable desde la plataforma. |
| **Sharp PM10** (ILED) | **GPIO 4** | `4` | Salida digital para pulsar el LED infrarrojo del sensor de polvo. |
| **Sharp PM10** (Ventilador) | **GPIO 27** | `27` | Salida PWM dedicada para el forzador de aire del tubo del sensor. Se activa automáticamente antes de cada lectura. |

---

## 4. Pines de Sistema (Integrados)
Pines reservados para la interacción básica con la placa física y la red.

| Función | ESP32 GPIO | Notas |
| :--- | :---: | :--- |
| **Botón BOOT** | **GPIO 0** | Integrado en la placa. Mantener presionado por >3 seg. para lanzar el Portal Cautivo WiFi. |
| **LED de Estado** | **GPIO 2** | Integrado en la placa. Usado para indicar conexión (Parpadeo) y modo de red. |

---

## 5. Expansión Futura (Comunicaciones LoRa)
De cara a futuras ampliaciones del hardware para implementar conectividad **LoRa/LoRaWAN**, la asignación de pines actual deja libres los puertos estándar necesarios. Se recomienda dejar previstos ambos puertos (SPI y UART) en el diseño final del PCB para permitir flexibilidad en la elección del módulo:

### Opción A: Módulo Transceptor Directo (SPI)
Módulos tipo **SX1276 / SX1278 / RFM95**. Requieren que el ESP32 controle directamente el radiofrecuencia y la modulación. Son más económicos pero requieren mayor procesamiento de firmware (librerías LoRa).
* **Pines Reservados (VSPI estándar):**
  * `GPIO 5` -> CS (Chip Select)
  * `GPIO 18` -> SCK (Clock)
  * `GPIO 19` -> MISO
  * `GPIO 23` -> MOSI
  * `GPIO 15` u otro libre -> DIO0 (Interrupción) / RST

### Opción B: Módulo Inteligente (Serial UART)
Módulos tipo **Ebyte E32 / Reyax RYLR998**. Poseen su propio microcontrolador interno que maneja la radiofrecuencia. Se comunican enviando y recibiendo comandos o datos por puerto serial. Es la **opción recomendada** para una integración más rápida y estable, ya que quita carga de procesamiento al ESP32.
* **Pines Reservados (UART2):**
  * `GPIO 16` -> RX2 (Recibe del TX del LoRa)
  * `GPIO 17` -> TX2 (Transmite al RX del LoRa)
  * Opcionalmente `GPIO 13` y `GPIO 14` para control de modos (M0/M1 o AUX en módulos Ebyte).

---

### Notas de Ensamblaje Industrial:
1. **Niveles Lógicos:** Los pines GPIO del ESP32 operan estrictamente a **3.3V**. Cualquier señal superior (como los 5V de la alimentación lógica del MQ135 o del sensor Sharp PM10) dañará el pin. Si un sensor opera en 5V y devuelve 5V en su salida de datos, debes colocar un conversor de nivel lógico o un divisor resistivo.
2. **Corriente:** Un pin GPIO del ESP32 puede entregar un máximo de 40mA (aunque se recomiendan 20mA). Nunca conectes los relés o motores directamente a los pines. Usa módulos de relés optoacoplados o transistores (MOSFET/BJT).
3. **Pines Analógicos:** Los pines 34, 35, 36 y 39 son *solo de entrada* y carecen de resistencias pull-up/pull-down internas. Asegúrate de diseñar el circuito externo (PCB) adecuadamente.

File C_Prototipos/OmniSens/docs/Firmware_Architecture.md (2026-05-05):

# Arquitectura del Firmware OmniSens (Hito 3)

Este documento detalla la estructura, flujo y componentes principales del firmware C++ (PlatformIO) ejecutado en los dispositivos Edge (ESP32) de la plataforma OmniSens.

## 1. Topología del Proyecto y Modularidad

El firmware ha sido diseñado bajo los principios de *Separation of Concerns* (Separación de Responsabilidades) y encapsulamiento OOP. En lugar de tener un archivo `main.cpp` monolítico e ilegible, la lógica está granularizada en la carpeta `lib/`:

*   **`SensorData`**: Gestiona la ingesta de los sensores físicos (MQ135, BMP280, AHT25, LDR). Su principal responsabilidad es construir el payload JSON (`populateJson`) utilizando un bloque de memoria estática (`StaticJsonDocument`) para evitar la fragmentación del Heap.
*   **`NetworkManager`**: Capsula de comunicación aislada. Resuelve el *Zero-Touch Provisioning* MQTT, escaneo WiFi asíncrono, actualizaciones remotas OTA y el procesamiento de comandos Cloud-to-Edge mediante *Callbacks*.
*   **`LedIndicator`**: Interfaz visual de usuario (Hardware UI). Administra el estado visual de la placa sin usar un solo bloqueo (`delay()`). Todo es operado con `millis()`.
*   **`SystemLogger`**: Sistema de bitácora dinámico. Permite suprimir la salida serial a demanda (vía MQTT) para ahorrar ciclos de CPU y limpiar el monitor serial en unidades de producción.

## 2. Flujo Multihilo (FreeRTOS)

El hardware ESP32 posee dos núcleos físicos. En lugar de usar `Ticker` (que ejecuta código en ISR de alta prioridad, arriesgando pánicos del kernel si se invocan métodos de red), aprovechamos la RTOS nativa:

### `TaskSensors` (Fijada al Core 1)
1.  Es la tarea pasiva del sistema. Despierta cada 5 segundos.
2.  Alimenta al Task Watchdog Timer (`esp_task_wdt_reset()`).
3.  Solicita un semáforo (`xSemaphoreTake(sensorMutex)`).
4.  Realiza la lectura I2C/Analógica de los sensores y sobrescribe el búfer JSON.
5.  Libera el semáforo y vuelve a dormir.

### `TaskNetwork` (Fijada al Core 0)
1.  Es la tarea activa y de red. Se ejecuta continuamente con micropausas (`vTaskDelay(50)`).
2.  Alimenta al Watchdog.
3.  Verifica el pin GPIO 0 para gatillar el **Portal Cautivo** a demanda.
4.  Mantiene vivo el cliente WiFi y MQTT.
5.  Si detecta información nueva generada por `TaskSensors` (y la red está conectada), pide el semáforo, publica el JSON al broker y libera el semáforo.

## 3. Seguridad y Aprovisionamiento (Zero-Touch)

Para mitigar riesgos de robo de código o extracción de binarios, **las contraseñas MQTT no se compilan en el firmware**.
El flujo inicial es el siguiente:
1.  El ESP32 arranca. El `NetworkManager` no encuentra un token criptográfico (`hmac_token`) en su partición NVS.
2.  Se conecta al broker utilizando **su propia dirección MAC** como credencial de usuario.
3.  El servidor (EMQX ACL) lo encierra en un *Sandbox*, donde lo único que tiene permitido es publicar en `aqi/provisioning/request`.
4.  El backend procesa la solicitud, calcula un hash **HMAC-SHA256** único para esa placa basándose en una llave simétrica secreta, y se lo responde en `aqi/provisioning/response/<MAC>`.
5.  El ESP32 lo recibe, lo guarda de forma persistente en NVS y se reinicia.
6.  En su próximo inicio, utiliza su MAC y el hash recibido, lo que le abre la puerta al tópico de telemetría final (`aqi/telemetry/<MAC>/data`).

## 4. Control Cloud-to-Edge (Actuadores y Config)

La placa es bi-direccional. Soporta la recepción de comandos remotos a través del broker:
*   **`aqi/commands/<MAC>/actuators`**: Al recibir un JSON (ej. `{"r1": 1, "r2": 0, "pwm": 128}`), `NetworkManager` dispara un puntero a función (*Callback*) en `main.cpp` para conmutar los relés o la salida PWM, aislando completamente a la red del hardware subyacente.
*   **`aqi/commands/<MAC>/config`**: Recibe comandos administrativos (ej. `{"debug": false}` para silenciar el `SystemLogger`).
*   **`aqi/commands/<MAC>/ota`**: Al recibir una URL, invoca nativamente al cliente HTTP para descargar y grabar la nueva versión de firmware en la partición OTA.

## 5. Resiliencia (Task Watchdog Timer)
Ambas tareas FreeRTOS deben reportarse periódicamente (cada 15 segundos) al TWDT. Si un sensor bloquea el bus I2C o la red se congela impidiendo que la tarea complete su ciclo, el perro guardián resetea el microcontrolador de forma dura.

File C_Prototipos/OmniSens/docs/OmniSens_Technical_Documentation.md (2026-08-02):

# 📑 Compendio de Documentación Técnica: Plataforma OmniSens & Edge Nodes

## 1. 🌟 Introducción y Arquitectura General del Sistema

**OmniSens** es una plataforma de Monitoreo de Calidad del Aire y Eficiencia Ambiental IoT (Internet of Things) de grado industrial/comercial. El sistema integra captura de datos de alta frecuencia en el borde (*Edge Computing*), transporte seguro de telemetría a través de protocolos optimizados (*MQTTS/WSS*), almacenamiento temporal e hidrométrico hiper-escalable (*TimescaleDB/PostgreSQL*) y una consola cliente interactiva y progresiva (*Vue 3 PWA*).

```mermaid
flowchart TD
    subgraph EDGE["Nodos de Borde (ESP32)"]
        ESP32["ESP32 Edge Node"]
        SENS["Sensores: MQ135, DHT/BME, BH1750, LDR"]
        ACT["Actuadores: Relés, PWM"]
        ESP32 --> SENS
        ESP32 --> ACT
    end

    subgraph BROKER["Broker Mensajería (EMQX)"]
        EMQX["EMQX Broker"]
        TLS["Port 8883 (MQTTS - secp256r1)"]
        WSS["Port 8084 (WSS - Let's Encrypt)"]
        EMQX --- TLS
        EMQX --- WSS
    end

    subgraph BACKEND["Servidor Aplicación (Fastify Node.js)"]
        FAST["API Fastify"]
        MQTT_ENG["Motor MQTT Ingesta"]
        RULES_ENG["Engine Anti-Spam & Reglas"]
        CRON["Planificador Reportes Telegram (JSON)"]
        FAST --- MQTT_ENG
        FAST --- RULES_ENG
        FAST --- CRON
    end

    subgraph STORAGE["Base de Datos"]
        DB[(TimescaleDB / PostgreSQL)]
    end

    subgraph CLIENTS["Canales de Salida & Clientes"]
        FRONT["Frontend Vue 3 PWA (Nginx)"]
        TELEGRAM["Bot de Telegram (JSON / Markdown)"]
        PUSH["Web Push Service (FCM/VAPID)"]
    end

    EDGE -- "MQTTS / Telemetría JSON" --> TLS
    TLS --> EMQX
    EMQX -- "Ingesta MQTT" --> MQTT_ENG
    MQTT_ENG --> DB
    MQTT_ENG --> RULES_ENG
    RULES_ENG --> PUSH
    RULES_ENG --> TELEGRAM
    CRON --> TELEGRAM
    FRONT -- "REST API / WSS" --> FAST
    FAST --> DB
```

---

## 2. 🎛️ Nodos de Borde (Firmware ESP32 Edge)

El firmware de los nodos reside en `Dispositivos/controlador_edge_v01mqtt/Omnisens_AQC`. Está estructurado en código modular C++ sobre **PlatformIO**.

### 2.1. Arquitectura Modular del Firmware (`lib/`)
* **`NetworkManager`**: Gestiona la conectividad de red. Si no existe conexión Wi-Fi almacenada en NVS, inicia el **Portal Cautivo (WiFiManager)** para configuración en caliente.
* **`MQ135Sensor`**: Manejo del sensor de gases de aire (CO2, NH3, benceno, alcohol). Implementa curva de calibración dinámica con resistencia de carga $R_0$ calculada en zona muerta ADC.
* **`AHT25Sensor` / `BMP280Sensor`**: Captura de temperatura (°C), humedad relativa (%) y presión atmosférica (hPa).
* **`BH1750Sensor` / `LDRSensor`**: Medición de iluminancia (Lux) y porcentaje de luz ambiental.
* **`DustSensor`**: Sensor óptico de partículas en suspensión ($PM_{2.5}$ / $PM_{10}$).
* **`SalidasRele` & `SalidaPWM`**: Control local de actuadores (extractores, persianas, ventilación por PWM).
* **`RulesEngine`**: Ejecución de reglas en el borde. Permite activar relés sin depender de la nube en caso de pérdida de enlace.
* **`StatusLED`**: Control de señales luminosas RGB (Modo configuración, buscando Wi-Fi, conectado, error de lectura).

### 2.2. Aprovisionamiento Seguro por MQTT (HMAC-SHA256)
El nodo no requiere almacenar contraseñas estáticas de base de datos ni tokens fijos:
1. El nodo se conecta a `aqi/provisioning/request` enviando su dirección MAC física y `timestamp`.
2. El Backend calcula una clave HMAC-SHA256 combinando el `timestamp` con la clave secreta única (`hmac_secret`) guardada en base de datos.
3. El Backend responde en `aqi/provisioning/response/{MAC}` enviando credenciales temporales MQTT para autorizar la publicación en `aqi/telemetry/{device_id}/data`.

---

## 3. 🖥️ Backend de la Nube (Fastify & Node.js)

Ubicado en la carpeta `backend/`, el backend es una API REST y un servicio de ingesta distribuido escrito en **TypeScript**.

### 3.1. Componentes Clave del Backend
* **Fastify Web Framework**: API ultrarrápida con validaciones y middleware de autenticación **JWT** (`plugins/jwt.ts`).
* **Kysely Query Builder**: Acceso a base de datos de tipo seguro (`src/config/db.ts`) conectado a PostgreSQL/TimescaleDB.
* **Motor MQTT (`src/services/mqtt.ts`)**:
  * Escucha `aqi/telemetry/+/data` para guardar lecturas en la tabla hipertabla `air_quality_data`.
  * Escucha eventos `$SYS/brokers/+/clients/+/disconnected` para detectar desconexión de hardware e informar cambio a `offline`.
  * **Sistema Anti-Spam de Reglas (Delta & State Machine)**: Mantiene un mapa en memoria (`ruleStates`). Evita el envío repetitivo de alertas notificando **únicamente en cambios de estado** (Normal $\rightarrow$ Alarma $\rightarrow$ Normal) o si ocurre una variación $\ge 10\%$ respecto a la última alerta.
* **Servicio de Notificaciones Push (`src/services/webpush.ts`)**: Emisión de alertas en tiempo real a navegadores clientes compatibles utilizando llaves VAPID.
* **Servicio de Reportes de Salud por Telegram (`src/services/healthReport.ts`)**:
  * Ejecuta una tarea programada cada 1 hora.
  * Recopila el estado de batería, intensidad de señal Wi-Fi, valores de sensores y actuadores de todos los nodos activos.
  * Formatea la información en un objeto JSON limpio y la envía como bloque de código Markdown a Telegram.

---

## 4. 🗄️ Modelo de Datos (TimescaleDB / PostgreSQL)

Las tablas principales en `aqi_db` son:

1. **`devices`**:
   * `device_id` (PK), `mac_address`, `device_name`, `client_id`, `hmac_secret`, `status`, `last_connection`, `deleted_at`.
2. **`air_quality_data` (Hipertabla TimescaleDB por `time`)**:
   * `time` (TIMESTAMPTZ), `device_id`, `pm25`, `pm10`, `co2`, `temp`, `hum`, `pres`, `l`, `lux`, `battery`, `r1`, `r2`, `pwm`.
3. **`device_rules`**:
   * `rule_id`, `device_id`, `metric`, `condition` (`>`, `<`, `==`), `threshold`, `hysteresis`, `action`, `priority`.
4. **`push_subscriptions`**:
   * `id`, `client_id`, `endpoint`, `auth`, `p256dh`, `created_at`.
5. **`system_alerts_log`**:
   * `device_id`, `alert_type`, `last_sent_at`.

---

## 5. 🌐 Consola Web (Frontend Vue 3 PWA)

Ubicada en la carpeta `frontend/`, la consola web está construida con **Vue 3, TypeScript, Chart.js / Vue-ChartJS y TailwindCSS**.

### 5.1. Vistas Principales
* **`DashboardView.vue`**: Panel principal interactivo con métricas en tiempo real, widgets visuales de calidad de aire, temperatura, humedad y control directo de relés/actuadores.
* **`AnalyticsView.vue`**: Análisis histórico de tendencias con gráficos interactivos, filtrado por rangos de fechas y exportación a CSV/PDF.
* **`DeviceManagerView.vue`**: Alta, baja, edición de parámetros y monitoreo del estado en línea de los nodos de sensores.
* **`RulesEngineView.vue`**: Interfaz de configuración de reglas y alertas personalizadas para cada métrica ambiental.
* **`LoginView.vue` / `RegisterView.vue`**: Autenticación segura y gestión de sesiones mediante tokens JWT.

---

## 6. 🚀 Infraestructura & Despliegue en Producción (AWS EC2)

El despliegue está orquestado mediante **Docker Compose** en una instancia AWS EC2.

### 6.1. Optimización para Instancias Pequeñas (t2.micro)
Debido a las limitaciones de memoria RAM de `t2.micro` (1 GB RAM), el proceso de compilación de código TypeScript (`tsc` y `vite build`) se realiza **localmente en el entorno de desarrollo**, generando:
* `frontend/dist`: Sirviendo directamente mediante Nginx.
* `backend/dist.zip`: Empaquetado y transferido por SFTP al servidor, omitiendo el consumo de compilación en la nube.

### 6.2. Arquitectura Docker Compose
* **`aqi_postgres`**: Contenedor TimescaleDB PG15.
* **`aqi_emqx`**: Broker de mensajería MQTT con puertos seguros MQTTS (8883) y WSS (8084).
* **`aqi_backend`**: Servicio Node.js corriendo la versión pre-compilada del backend (`Dockerfile.prod`).
* **`aqi_frontend`**: Servidor Nginx que maneja certificados SSL (Let's Encrypt / HTTPS), sirve los archivos estáticos de la PWA y hace Proxy Reverso hacia la APIREST del backend.

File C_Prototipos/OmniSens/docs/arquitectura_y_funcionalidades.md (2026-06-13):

# 🏗️ Arquitectura y Funcionalidades de la Plataforma OmniSens

Este documento presenta una descripción detallada de la arquitectura de sistema, flujo de datos, modelo de persistencia y estructura funcional de **OmniSens**, una plataforma de Internet de las Cosas (IoT) de grado industrial diseñada para la monitorización ambiental, automatización inteligente y gestión remota de dispositivos en tiempo real.

---

## 1. Vista General del Sistema

OmniSens emplea una topología **Edge-to-Cloud** distribuida y contenedorizada. Los datos de telemetría fluyen desde los sensores físicos en campo hasta el panel de usuario mediante una red de comunicación asíncrona segura.

```mermaid
flowchart TD
    %% Definición de estilos para mejor visualización
    classDef edge fill:#e1f5fe,stroke:#01579b,stroke-width:2px;
    classDef comm fill:#fff3e0,stroke:#e65100,stroke-width:2px;
    classDef cloud fill:#e8f5e9,stroke:#1b5e20,stroke-width:2px;
    classDef user fill:#f3e5f5,stroke:#4a148c,stroke-width:2px;

    %% Nodos de Hardware (Edge)
    subgraph e44["Capa Edge"]
        ESP32["Node ESP32 / FreeRTOS"]
        Sensors["Sensores: AHT25, BMP280, MQ135, LDR, BH1750, Sharp Dust"]
        Actuators["Actuadores: Relés, Salida PWM"]
        
        Sensors -->|"I2C / Analógico"| ESP32
        Actuators <-->|"GPIO / PWM"| ESP32
    end

    %% Capa de Transporte (MQTT Broker)
    subgraph e45["Capa de Comunicaciones"]
        EMQX["Broker EMQX / MQTTS"]
    end

    %% Capa de Backend (Persistencia y Lógica)
    subgraph e46["Capa Core Cloud"]
        Fastify["Fastify API / Node.js & TypeScript"]
        Timescale[("TimescaleDB / PostgreSQL")]
    end

    %% Capa de Frontend (Interfaz de Usuario)
    subgraph e47["Capa de Usuario"]
        VueApp["Dashboard Vue 3 / Vite & Tailwind"]
    end

    %% Relaciones y flujo de datos
    ESP32 -->|"1. Publica Telemetría MQTTS"| EMQX
    EMQX -->|"2. Suscripción y Escucha"| Fastify
    Fastify -->|"3. Almacenamiento Hipertabla"| Timescale
    VueApp -->|"4. Consulta REST / JWT"| Fastify
    VueApp -->|"5. Comandos Actuadores REST"| Fastify
    Fastify -->|"6. Publica Comandos MQTT"| EMQX
    EMQX -->|"7. Suscripción Comandos MQTTS"| ESP32

    %% Aplicación de clases
    class ESP32,Sensors,Actuators edge;
    class EMQX comm;
    class Fastify,Timescale cloud;
    class VueApp user;
```

---

## 2. Capa Física y Firmware (Edge)

Los nodos de hardware están controlados por un microcontrolador **ESP32** ejecutando firmware desarrollado en **C++** sobre el framework **PlatformIO**.

### 2.1 Multitarea Resiliente (FreeRTOS)
El firmware distribuye las tareas críticas en los dos núcleos físicos del ESP32 para garantizar un funcionamiento libre de bloqueos (*zero-blocking*):
*   **Core 1 - `TaskSensors` (Lectura pasiva)**:
    *   Frecuencia de muestreo: Cada 5 segundos.
    *   Lee datos físicos a través del bus I2C (temperatura/humedad del AHT25, presión/temperatura del BMP280) y canales analógicos (calidad de aire del MQ135, luminosidad del LDR).
    *   Utiliza un semáforo (`sensorMutex`) y memoria estática (`StaticJsonDocument`) para actualizar de forma segura el búfer JSON de telemetría, evitando pánicos de fragmentación de memoria en el Heap.
    *   Reinicia el Watchdog de Tarea (`esp_task_wdt_reset()`).
*   **Core 0 - `TaskNetwork` (Comunicación activa)**:
    *   Mantiene la conexión WiFi y el cliente MQTT.
    *   Monitorea el pin GPIO 0 para arrancar el **Portal Cautivo de Aprovisionamiento** (`WiFiManager` asíncrono) si el usuario presiona el botón físico.
    *   Toma el semáforo `sensorMutex` para leer el búfer de datos e inserta la telemetría en el canal de red mediante publicaciones hacia el broker MQTT.
    *   Maneja de forma asíncrona la descarga de firmware para actualizaciones **OTA (Over-The-Air)**.

### 2.2 Aprovisionamiento Dinámico (Zero-Touch)
1.  **Arranque Inicial**: El dispositivo inicia; si no detecta una clave criptográfica almacenada en su memoria no volátil (NVS), se conecta al Broker EMQX utilizando su **dirección MAC** como credencial provisional.
2.  **Sandbox de Registro**: El broker limita el acceso del dispositivo sin provisionar al tópico de solicitud `aqi/provisioning/request`.
3.  **Generación de Token**: El backend recibe la petición, valida si la MAC está registrada en la base de datos de dispositivos autorizados y calcula un hash **HMAC-SHA256** único mediante una clave simétrica maestra.
4.  **Almacenamiento Persistente**: El hash se devuelve en el tópico de respuesta `aqi/provisioning/response/<MAC>`. El ESP32 lo recibe, lo graba en su partición NVS y se reinicia de manera automática.
5.  **Acceso Final**: En los arranques posteriores, el ESP32 se autentica con su dirección MAC y el token HMAC calculado, ganando acceso completo al tópico de telemetría `aqi/telemetry/<MAC>/data` y comandos `aqi/commands/<MAC>/*`.

---

## 3. Capa de Transporte (Broker MQTT)

El sistema utiliza **EMQX** como broker de mensajería de alto rendimiento. En entornos locales o de producción, corre aislado dentro de un contenedor Docker.

### Esquema de Tópicos
*   `aqi/provisioning/request`: Registro inicial de dispositivos mediante su dirección MAC.
*   `aqi/provisioning/response/<MAC>`: Retorno del token HMAC secreto al nodo específico.
*   `aqi/telemetry/<MAC>/data`: Publicación del payload JSON de mediciones en tiempo real.
*   `aqi/commands/<MAC>/actuators`: Recepción de comandos de activación física (ej. `{"r1": true, "r2": false, "pwm": 180}`).
*   `aqi/commands/<MAC>/config`: Ajustes administrativos del nodo (ej. activar/desactivar logs del puerto serie).
*   `aqi/commands/<MAC>/ota`: Envío de la URL de descarga para flasheo remoto.

---

## 4. Capa de Backend y Persistencia

El backend es una API REST construida sobre **Node.js, TypeScript y Fastify**, elegida por su bajísimo consumo de recursos y alta velocidad de procesamiento en entornos limitados (*Edge hosts*).

### 4.1 Base de Datos Multitenant y Series Temporales
La base de datos utiliza **PostgreSQL** con la extensión **TimescaleDB** para almacenar de manera eficiente las lecturas continuas.

*   **Aislamiento Multi-Tenant**: Los datos relacionales de clientes, usuarios y dispositivos están aislados por organización (`client_id`). Todas las operaciones del backend verifican esta relación basándose en el JWT.
*   **Hipertabla de Telemetría (`air_quality_data`)**: Almacena lecturas crudas. Está particionada de forma automática en trozos de 1 día para garantizar búsquedas veloces en RAM. Cuenta con una política de retención automática de **30 días** para evitar el sobrellenado de disco.
*   **Continuous Aggregates (`aqi_hourly_avg`)**: Vista materializada que calcula promedios horarios de forma síncrona en segundo plano. Sirve como fuente primaria de datos históricos a largo plazo para el frontend, reduciendo drásticamente las cargas de procesamiento sobre la base de datos y la CPU del servidor.

### 4.2 Seguridad y Control de Acceso (JWT)
El acceso a la API REST está protegido mediante JSON Web Tokens. Tras validar la autenticación de un usuario, el backend emite un token con los siguientes "claims":
*   `sub`: ID único del usuario.
*   `role`: Rol de privilegios (`admin`, `operator`, `viewer`).
*   `client_id`: Identificador de la organización arrendataria (Tenant).

El middleware de Fastify intercepta las peticiones en rutas protegidas, valida la firma criptográfica (HS256/RS256) del token y adjunta el `client_id` al contexto (`request.user.client_id`). Este identificador se inyecta obligatoriamente en todas las consultas a la base de datos relacional y las series de tiempo.

---

## 5. Capa de Frontend (Dashboard)

El Frontend está desarrollado con **Vue 3 (Composition API)**, estructurado con **TypeScript**, empaquetado con **Vite** y maquetado visualmente con **Tailwind CSS**. Adicionalmente, cuenta con el motor de gráficos de alto rendimiento **Apache ECharts** y el set de iconos interactivos **Lucide Vue Next**.

### 5.1 Estructura del Proyecto Frontend
La carpeta `/frontend` cuenta con la siguiente arquitectura modular:
*   `src/main.ts`: Punto de entrada de la aplicación Vue. Monta la aplicación e inicializa Pinia y Vue Router.
*   `src/App.vue`: Componente raíz que renderiza las vistas correspondientes dentro del layout activo.
*   `src/layouts/MainLayout.vue`: Marco de interfaz compartido que contiene el menú de navegación lateral, el estado de sesión del usuario y la cabecera principal.
*   `src/router/index.ts`: Configura las rutas protegidas (Dashboard, Analytics, Devices, Rules, Billing) y aplica un guardián de navegación (`beforeEach`) para redirigir a `/login` si no existe una sesión activa.
*   `src/stores/auth.ts`: Almacén de Pinia para gestionar el estado de sesión, almacenar el token JWT y guardarlo en el `localStorage` de manera persistente.
*   `src/services/api.ts`: Cliente HTTP centralizado con **Axios**. Configura un interceptor de petición que inyecta automáticamente el token JWT (`Authorization: Bearer <token>`) en las cabeceras HTTP, y un interceptor de respuesta que realiza la desconexión del usuario y redirección a `/login` en caso de recibir un error HTTP 401 (No autorizado).
*   `src/views/`: Contiene las vistas funcionales de la plataforma:
    *   `LoginView.vue`: Pantalla de inicio de sesión.
    *   `DashboardView.vue`: Cuadro de mando principal con widgets en tiempo real.
    *   `DeviceManagerView.vue`: Listado de dispositivos con interruptores y deslizadores manuales para actuadores.
    *   `AnalyticsView.vue`: Gráficos históricos de tendencias con filtrado por rango de tiempo.
    *   `RulesEngineView.vue`: Interfaz de programación visual para reglas de automa---

## 6. Estado de la Implementación del Frontend (Refactorización Completada)

La refactorización y conexión del frontend con la API multi-tenant y los flujos MQTT del hardware se completó satisfactoriamente. A continuación se resume la arquitectura final integrada:

```
┌────────────────────────────────────────────────────────────────────────────────────────┐
│                        ESTADO FINAL DE LAS VISTAS DEL FRONTEND                         │
├───────────────────────────────┬────────────────────────────────────────────────────────┤
│ Vista Frontend                │ Implementación y Conexión Real                         │
├───────────────────────────────┼────────────────────────────────────────────────────────┤
│ LoginView                     │ Consumo real de POST /login. Bypass opcional de des.   │
│ DashboardView                 │ Consumo de GET /telemetry/now/:id con filtrado.        │
│ DeviceManagerView             │ Listado de GET /devices y telemetría de batería (V).   │
│ AnalyticsView                 │ Integrado a ECharts con /history y aggregate por hora. │
│ RulesEngineView               │ Conexión a POST /devices/:id/config y localStorage.    │
└───────────────────────────────┴────────────────────────────────────────────────────────┘
```

### 6.1 Detalle de Implementación por Módulo

#### 1. Inicio de Sesión (`LoginView.vue`)
- **Conexión Real**: Llama al endpoint `POST /login` enviando las credenciales. Si el backend está inactivo en desarrollo local, cuenta con un bypass automático para permitir pruebas rápidas con las credenciales demo.
- **Acceso Dinámico**: Inyecta el token en el encabezado de autorización HTTP de Axios (`Authorization: Bearer <token>`).

#### 2. Tablero de Control (`DashboardView.vue`)
- **Lógica de Luz Redundante**: Detecta si están presentes uno, ambos o ningún sensor de luz. Si ambos están presentes, expone el sensor digital (BH1750) como prioritario y utiliza el analógico (LDR) de respaldo, activando una advertencia animada en pantalla en caso de desvíos graves de medición. Si un sensor está ausente (reporta `-1.0`), oculta dinámicamente sus métricas de diagnóstico.
- **Visualización Dinámica**: Oculta automáticamente los widgets de sensores ausentes (presión BMP280, polvo PM10, gases MQ135).
- **Comando de Actuadores**: Panel interactivo con selectores para Relé 1, Relé 2 y un control deslizante PWM para la velocidad del motor. Implementa un candado criptográfico-lógico de 3 segundos al enviar comandos para evitar carreras de datos con el loop de telemetría.

#### 3. Gestor de Dispositivos (`DeviceManagerView.vue`)
- **Diagnóstico de Batería**: Consulta dinámicamente la telemetría de cada nodo para mostrar el voltaje de batería medido por el divisor resistivo. Convierte la tensión a porcentaje usando el rango nominal 3.2V (0%) - 4.2V (100%) y cambia el icono de estado de la batería según la carga (verde para alto, amarillo para medio, rojo parpadeante para crítico).

#### 4. Analíticas Históricas (`AnalyticsView.vue`)
- **Graficación Real**: Mapea los promedios horarios de la agregación continua TimescaleDB (`aqi_hourly_avg`) para trazar tendencias históricas.
- **Filtrado Flexible**: El operador puede alternar entre nodos del inquilino, seleccionar la métrica específica a graficar (Temperatura, Humedad, Presión, CO2, PM10, Luz) y ajustar el marco temporal (24 horas, 7 días o 30 días).

#### 5. Reglas Edge (`RulesEngineView.vue`)
- **Control Distribuido**: Permite establecer disparadores para automatización local (ej. si CO2 > 1000 ppm, activar Relé 1; apagar cuando baje de 800 ppm).
- **Persistencia**: Guarda la configuración localmente en el `localStorage` del cliente y transmite el payload al canal de configuración de dispositivos (`POST /api/devices/:deviceId/config`) que se publica vía MQTT. El nodo Edge descarga la regla y opera de forma autónoma.

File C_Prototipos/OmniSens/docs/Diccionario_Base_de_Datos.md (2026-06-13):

# Diccionario y Arquitectura de la Base de Datos (OmniSens)

Este documento detalla la estructura y características "Enterprise" de la base de datos PostgreSQL + TimescaleDB del proyecto OmniSens, optimizada para arquitectura Multi-Tenant, alta concurrencia y bajo consumo de recursos (ideal para servidores Edge o de recursos limitados como un Intel Atom).

## 1. Características Principales

- **Motor:** PostgreSQL con extensión TimescaleDB.
- **Multi-Tenant:** Aislamiento de datos por cliente (Organización).
- **Soft Deletes:** Borrado lógico implementado en las tablas principales para mantener integridad histórica y permitir auditorías reales.
- **Series Temporales Optimizadas:** Uso de Hipertablas para la ingesta masiva rápida y particionamiento automático en RAM.
- **Data Lifecycle (Ciclo de Vida):** Políticas de retención automáticas para evitar que el almacenamiento crezca indefinidamente.
- **Continuous Aggregates:** Vistas materializadas que se actualizan solas en segundo plano para servir consultas de gráficos de manera instantánea, sin colapsar la CPU al momento de la consulta.

## 2. Esquema Relacional (Tablas)

### 2.1 Tabla: `clients`
Almacena la información de las organizaciones/clientes (los "inquilinos" de la plataforma).

| Columna | Tipo | Descripción |
| :--- | :--- | :--- |
| `client_id` | SERIAL (PK) | Identificador único del cliente. |
| `client_name` | VARCHAR(100) | Nombre comercial de la organización. |
| `business_tax_id` | VARCHAR(50) | CUIT/RUT o identificador fiscal (opcional). |
| `created_at` | TIMESTAMPTZ | Fecha de registro. |
| `updated_at` | TIMESTAMPTZ | Fecha de última modificación. |
| `deleted_at` | TIMESTAMPTZ | Fecha de borrado lógico (Soft Delete). |

### 2.2 Tabla: `users`
Almacena los usuarios que tendrán acceso al Dashboard, vinculados a un cliente.

| Columna | Tipo | Descripción |
| :--- | :--- | :--- |
| `user_id` | SERIAL (PK) | Identificador único del usuario. |
| `client_id` | INTEGER (FK) | Vinculación con la tabla `clients` (`ON DELETE CASCADE`). |
| `email` | VARCHAR(150) | Correo electrónico (único, usado para el login). |
| `password_hash` | TEXT | Contraseña encriptada (bcrypt/argon2). |
| `user_role` | VARCHAR(20) | Rol del usuario (`admin`, `operator`, `viewer`). |
| `full_name` | VARCHAR(100) | Nombre completo. |
| `created_at` | TIMESTAMPTZ | Fecha de creación del usuario. |
| `deleted_at` | TIMESTAMPTZ | Fecha de borrado lógico (Soft Delete). |

### 2.3 Tabla: `devices`
Inventario de nodos sensores Edge (ESP32), vinculados a clientes para el multi-tenancy y con soporte de autenticación dinámica.

| Columna | Tipo | Descripción |
| :--- | :--- | :--- |
| `device_id` | VARCHAR(50) (PK) | Identificador lógico/alfanumérico del dispositivo. |
| `client_id` | INTEGER (FK) | Vinculación con `clients` (`ON DELETE SET NULL`). |
| `mac_address` | MACADDR | Dirección física (única), usada para el aprovisionamiento. |
| `device_name` | VARCHAR(100) | Nombre descriptivo asignado por el usuario. |
| `hmac_secret` | VARCHAR(64) | Secreto único autogenerado para firmar conexiones MQTT. |
| `created_at` | TIMESTAMPTZ | Fecha en que se registró el dispositivo. |
| `last_connection`| TIMESTAMPTZ | Última vez que el dispositivo reportó telemetría o status. |
| `status` | VARCHAR(20) | Estado actual (`active`, `inactive`, `error`). |
| `deleted_at` | TIMESTAMPTZ | Fecha de borrado lógico (Soft Delete). |

### 2.4 Tabla: `air_quality_data` (Hipertabla TimescaleDB)
Almacena las mediciones crudas segundo a segundo (o minuto a minuto). Está convertida en Hipertabla particionada por intervalos de 1 día para optimizar la RAM en inserciones masivas.

| Columna | Tipo | Descripción |
| :--- | :--- | :--- |
| `time` | TIMESTAMPTZ | Marca de tiempo exacta de la medición. |
| `device_id` | VARCHAR(50) (FK) | ID del dispositivo que generó el dato. |
| `pm25` | FLOAT | Concentración de Material Particulado 2.5 (µg/m³). |
| `pm10` | FLOAT | Concentración de Material Particulado 10 (µg/m³). |
| `co2` | FLOAT | Concentración de Dióxido de Carbono (ppm). |
| `temp` | FLOAT | Temperatura ambiente (°C). |
| `hum` | FLOAT | Humedad relativa (%). |
| `pres` | FLOAT | Presión atmosférica (hPa). |
| `l` | INTEGER | Valor analógico del LDR (0 - 4095) como respaldo de luz. |
| `lux` | FLOAT | Intensidad lumínica en lux (BH1750) como sensor de luz primario. |
| `battery` | FLOAT | Tensión medida en la batería (V). Excluida de dashboards ambientales y mostrada en administrador. |
| `r1` | INTEGER | Estado del Relé 1 (Extractor) (0: OFF, 1: ON). |
| `r2` | INTEGER | Estado del Relé 2 (Calefactor) (0: OFF, 1: ON). |
| `pwm` | INTEGER | Velocidad controlada por PWM para el motor (0 - 255). |

> **Nota de Optimización (Data Lifecycle)**: Cuenta con una **Política de Retención** que elimina los datos de esta tabla automáticamente cuando superan los **30 días** de antigüedad, evitando que el disco se llene por el volumen masivo de datos crudos.

## 3. Vistas y Funciones Especiales

### 3.1 Vista: `vw_telemetry_by_client`
Vista convencional relacional que facilita al backend (Hito 2) consultar datos filtrando por cliente sin tener que escribir JOINs complejos en el código. Excluye automáticamente a los clientes o dispositivos que hayan sufrido un "Soft Delete" (gracias a la condición `deleted_at IS NULL`).

### 3.2 Vista Materializada: `aqi_hourly_avg` (Continuous Aggregate)
Calcula y almacena promedios horarios de la telemetría de forma silenciosa en segundo plano. Es la fuente de datos principal para las gráficas históricas del Frontend (Hito 4).
- **Intervalo de Cálculo**: Agrupa datos cada `1 hour`.
- **Actualización**: Automática a través de una política de TimescaleDB programada cada hora.
- **Ventaja de Rendimiento**: Consultar 1 año de datos a través de esta tabla devuelve un máximo de ~8,760 filas en lugar de los millones de filas crudas, resultando en respuestas de la API en pocos milisegundos.
- **Retención Histórica**: Los datos precalculados en esta vista **no se borran tras 30 días**, conformando el repositorio histórico a largo plazo del sistema.

### 3.3 Stored Procedure: `register_new_device()`
Función interna (PL/pgSQL) utilizada para el aprovisionamiento eficiente de dispositivos. Se encarga de verificar si la dirección MAC ya existe usando la cláusula `ON CONFLICT DO NOTHING`, retornando un booleano al backend para notificar el éxito o fracaso de la inserción, ahorrando consultas extra (`SELECT` antes del `INSERT`).

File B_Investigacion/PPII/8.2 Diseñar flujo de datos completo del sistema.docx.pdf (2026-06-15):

### 8.2 Diseñar flujo de datos completo del sistema

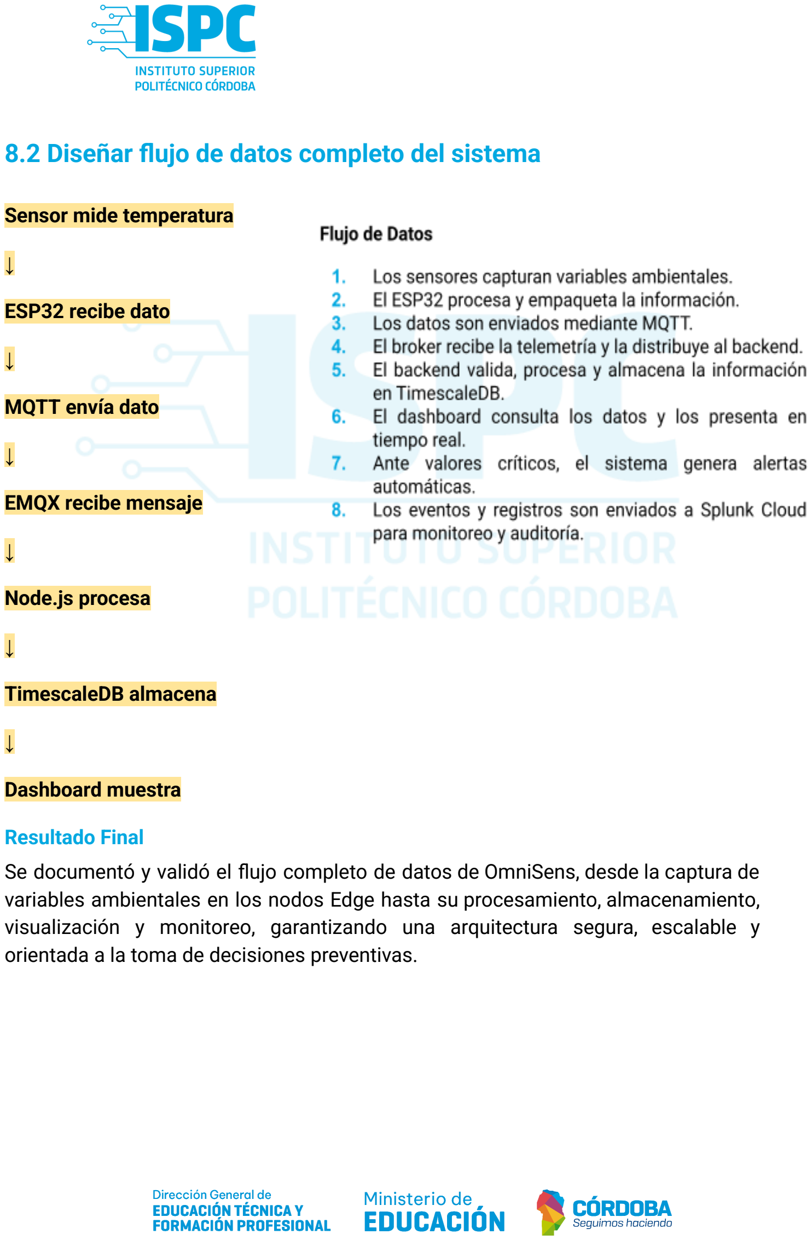
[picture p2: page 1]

Sensor mide temperatura

↓

ESP32 recibe dato

↓

MQTT envía dato

↓

EMQX recibe mensaje

↓

Node.js procesa

↓

TimescaleDB almacena

↓

Dashboard muestra

Resultado Final
Se documentó y validó el flujo completo de datos de OmniSens, desde la captura de variables ambientales en los nodos Edge hasta su procesamiento, almacenamiento, visualización y monitoreo, garantizando una arquitectura segura, escalable y orientada a la toma de decisiones preventivas.

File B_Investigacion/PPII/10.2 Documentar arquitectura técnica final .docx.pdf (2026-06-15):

### 10.2 Documentar arquitectura técnica final

## Documentación de la Arquitectura Técnica Final

Descripción General

OmniSens Industrial Suite implementa una arquitectura IoT multicapa diseñada para la adquisición, transmisión, procesamiento, almacenamiento y visualización de datos ambientales en entornos industriales. La solución integra nodos de monitoreo basados en ESP32, protocolos de comunicación seguros, infraestructura cloud y herramientas de observabilidad para garantizar escalabilidad, disponibilidad y seguridad operativa.

Arquitectura por Capas

1. Edge Layer (Capa de Adquisición).

Corresponde a los nodos IoT desplegados en campo.

Componentes:

- ESP32
- Sensor MQ135
- Sensor AHT25
- Sensor BMP280
- Sensor BH1750

Función: Capturar variables ambientales críticas como temperatura, humedad, presión atmosférica, calidad del aire y luminosidad.

2. Communication Layer (Capa de Comunicación).

Responsable de transportar la información desde los nodos hacia la infraestructura central.

Tecnologías:

- MQTT
- TLS
- HMAC-SHA256

Función: Garantizar una transmisión eficiente, segura y confiable de la telemetría generada por los dispositivos IoT.

3. Backend Layer (Capa de Procesamiento).

Gestiona el procesamiento de la información y la lógica de negocio.

Tecnologías:

- Node.js
- Fastify
- Docker
- AWS EC2

Función: Procesar datos recibidos, administrar dispositivos, gestionar alertas y exponer servicios para el dashboard.

4. Data Layer (Capa de Datos).

Responsable del almacenamiento y consulta de información histórica.

Tecnologías:

- PostgreSQL
- TimescaleDB

Función: Almacenar series temporales y permitir el análisis histórico de variables ambientales.

5. Visualization Layer (Capa de Visualización).

Proporciona acceso a la información mediante interfaces gráficas.

Tecnologías:

- Vue 3
- Apache ECharts

Función: Visualizar datos en tiempo real, tendencias históricas y estados operativos desde dispositivos móviles y de escritorio.

6. Observability Layer (Capa de Observabilidad).

Permite monitorear la salud y el comportamiento de la plataforma.

Tecnologías:

- Splunk Cloud
- Splunk Universal Forwarder

Función: Centralizar logs, monitorear eventos y detectar anomalías en la infraestructura.

Flujo de Datos

1. Los sensores capturan variables ambientales.
2. El ESP32 procesa y empaqueta la información.
3. Los datos son enviados mediante MQTT.
4. El broker recibe la telemetría y la distribuye al backend.
5. El backend valida, procesa y almacena la información en TimescaleDB.
6. El dashboard consulta los datos y los presenta en tiempo real.
7. Ante valores críticos, el sistema genera alertas automáticas.

### 8. Los eventos y registros son enviados a Splunk Cloud para monitoreo y

auditoría.

Tecnologías Utilizadas

Hardware
- ESP32
- MQ135
- AHT25
- BMP280
- BH1750

Comunicaciones
- MQTT
- TLS
- HMAC-SHA256

Backend e Infraestructura
- Node.js

- Fastify
- Docker
- AWS EC2
- Ansible

Base de Datos
- PostgreSQL
- TimescaleDB

Frontend
- Vue 3

Observabilidad
- Splunk Cloud
- Splunk Universal Forwarder

Resultado Final
La arquitectura de OmniSens permite capturar, procesar, almacenar y visualizar información ambiental en tiempo real mediante una plataforma segura, escalable y orientada a la toma de decisiones preventivas en entornos industriales.

Sensores
↓
ESP32 (Nodo Edge)
↓
MQTT + TLS/HMAC
↓
Broker EMQX
↓
Backend Node.js/Fastify
↓
TimescaleDB
↓
Dashboard Vue 3

Paralelamente: Backend → Logs → Splunk Cloud

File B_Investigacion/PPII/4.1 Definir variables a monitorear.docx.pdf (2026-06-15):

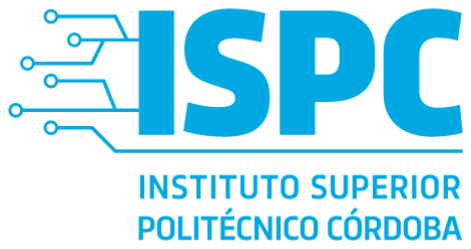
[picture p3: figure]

## 4.1 Definir variables a monitorear

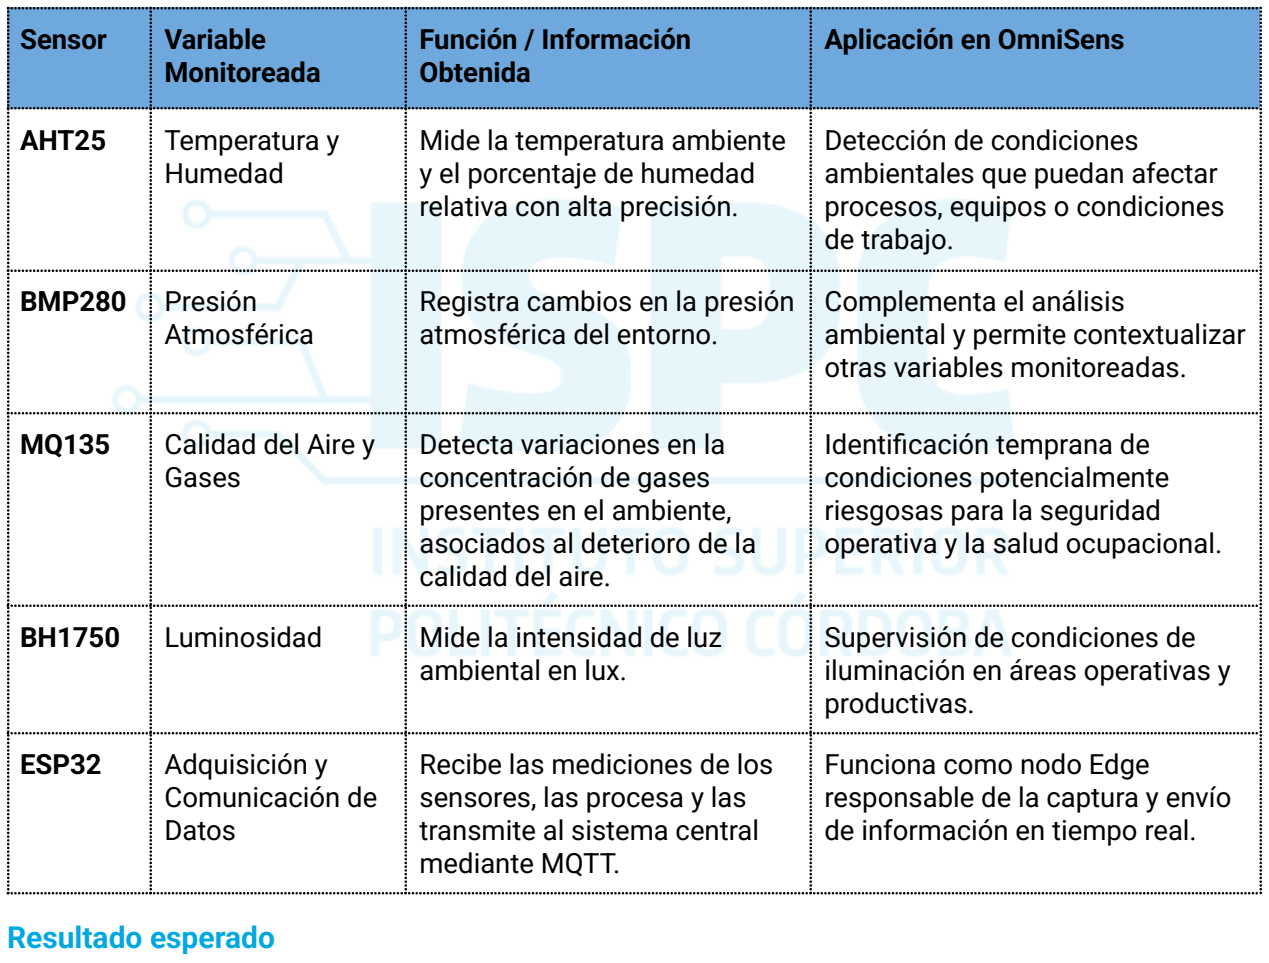
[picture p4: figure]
Sensor; Variable; Monitoreada; Función / Información Obtenida; Aplicación en OmniSens; AHT25; Temperatura y; Humedad; Mide la temperatura ambiente y el porcentaje de humedad relativa con alta precisión.; Detección de condiciones ambientales que puedan afectar procesos, equipos o condiciones de trabajo.; BMP280 Presión Atmosférica; Registra cambios en la presión atmosférica del entorno.; Complementa el análisis ambiental y permite contextualizar otras variables monitoreadas.; Calidad del Aire y; Gases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

La infraestructura de monitoreo de OmniSens permite medir variables críticas como temperatura, humedad, presión atmosférica, calidad del aire y luminosidad mediante sensores especializados integrados en nodos ESP32, proporcionando información confiable para la prevención de riesgos y la toma de decisiones en entornos industriales.

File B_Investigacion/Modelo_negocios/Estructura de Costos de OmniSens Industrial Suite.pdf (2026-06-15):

# Estructura de Costos de OmniSens Industrial Suite

# Introducción

Para garantizar la viabilidad económica de OmniSens Industrial Suite es necesario identificar y analizar los costos asociados al diseño, implementación, operación y mantenimiento de la solución.

La estructura de costos permite comprender cuánto cuesta desarrollar y operar el sistema, facilitando la toma de decisiones relacionadas con precios, rentabilidad y escalabilidad.

En el modelo de negocio de OmniSens se consideran tanto costos de inversión inicial (CAPEX) como costos operativos recurrentes (OPEX), asociados a la infraestructura tecnológica y al funcionamiento continuo del servicio.

# Objetivo

Identificar y clasificar los principales costos involucrados en la implementación y operación de OmniSens Industrial Suite para construir una estructura de costos clara y coherente con el modelo de negocio.

# Costos de Sensores y Dispositivos

Los sensores constituyen la base del sistema de monitoreo ambiental y representan una parte importante de la inversión inicial.

Componentes principales:

- Sensor de temperatura y humedad (AHT25).
- Sensor de presión atmosférica (BMP280).
- Sensor de calidad del aire y gases (MQ135).
- Sensor de luminosidad (LDR).
- Microcontroladores ESP32.
- Módulos de comunicación LoRa.

Estos elementos permiten la adquisición y procesamiento de datos ambientales en tiempo real.

Tipo de costo

CAPEX (Inversión Inicial)

# Costos de Infraestructura de Comunicaciones

Para garantizar la transmisión de datos entre los sensores, dispositivos de procesamiento y plataformas de monitoreo, OmniSens requiere una infraestructura de comunicaciones confiable.

Los costos asociados incluyen:

- Equipamiento de red local.
- Routers y puntos de acceso WiFi.
- Cableado de red cuando sea necesario.
- Configuración de conectividad.
- Servicios de acceso a Internet.
- Dispositivos de comunicación para integración de sensores y servidores.

Esta infraestructura permite asegurar la disponibilidad de la información y la comunicación entre los distintos componentes del sistema IoT.

Tipo de costo

CAPEX (Inversión Inicial) para equipamiento.

OPEX (Costo Operativo) para servicios de conectividad y acceso a Internet.

# Costos de Servidores e Infraestructura Tecnológica

OmniSens utiliza una arquitectura basada en servicios que permiten almacenar, procesar y visualizar información ambiental.

Componentes considerados:

- Servidor de aplicaciones.
- Servicios Docker.

- Base de datos
- Node-RED.
- Grafana.
- Servicios Cloud (si corresponden).

Estos recursos garantizan la disponibilidad y procesamiento de la información generada por los sensores.

Tipo de costo

OPEX (Costo Operativo)

# Costos de Mantenimiento

Toda infraestructura tecnológica requiere actividades periódicas de mantenimiento para asegurar su correcto funcionamiento.

Se consideran:

- Actualizaciones de firmware.
- Mantenimiento de sensores.
- Sustitución de componentes dañados.
- Soporte técnico.
- Monitoreo del sistema.
- Gestión de incidencias.

Estas actividades contribuyen a prolongar la vida útil de los equipos y mantener la calidad del servicio.

Tipo de costo

OPEX (Costo Operativo)

# Costos de Energía

El funcionamiento continuo de dispositivos y servidores implica un consumo energético permanente.

Los principales consumos corresponden a:

- Sensores y nodos ESP32.
- Gateways LoRa.
- Equipos de red.
- Servidores locales.
- Infraestructura de comunicaciones.

Aunque los dispositivos IoT suelen tener bajo consumo energético, este costo debe ser considerado dentro de la planificación financiera.

Tipo de costo

OPEX (Costo Operativo)

# Clasificación General de Costos

Categoría | Tipo
Sensores y ESP32 | CAPEX
Infraestructura LoRa | CAPEX
Equipamiento de red | CAPEX
Servidores | OPEX
Mantenimiento | OPEX
Energía | OPEX
Servicios Cloud | OPEX

# Relación con el Modelo de Negocio

La estructura de costos se encuentra directamente vinculada con el ARPU definido para OmniSens.

Los ingresos generados mediante suscripciones deben permitir:

- Recuperar la inversión inicial.
- Cubrir costos operativos.
- Financiar el crecimiento del sistema.

- Garantizar la sostenibilidad del servicio.

Por este motivo, el análisis de costos constituye un elemento fundamental dentro del Business Model Canvas.

# Beneficios de Definir la Estructura de Costos

La identificación de costos permite:

- Evaluar rentabilidad.
- Determinar precios adecuados.
- Planificar inversiones futuras.
- Optimizar recursos.
- Analizar escalabilidad.
- Reducir riesgos financieros.

# Resultado Esperado

Disponer de una estructura de costos clara y organizada que permita comprender los gastos asociados al desarrollo y operación de OmniSens Industrial Suite.

# Conclusión

La estructura de costos constituye uno de los componentes fundamentales del modelo de negocio de OmniSens. La identificación de costos de sensores, infraestructura LoRa, servidores, mantenimiento y energía permite evaluar la sostenibilidad económica del proyecto y establecer estrategias financieras adecuadas para su crecimiento.

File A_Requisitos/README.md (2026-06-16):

(https://postimg.cc/2VrdBDD4)
# 📋 Especificaciones y Requisitos | OmniSens Industrial Suite

## Descripción
Este directorio centraliza el marco de referencia, los objetivos estratégicos y los criterios de validación que rigen el desarrollo de **OmniSens Industrial Suite**. La información aquí documentada constituye la línea base para la investigación, el prototipado y la presentación final del proyecto.

## Áreas de Competencia Técnica
La arquitectura de **OmniSens** integra los siguientes pilares tecnológicos, cubriendo la totalidad de los ejes temáticos del ABP:

| Área de Trabajo | Foco Técnico |
| :--- | :--- |
| **Infraestructura Cloud** | Orquestación en AWS EC2, contenedores (Docker) y automatización (Ansible). |
| **Seguridad IoT** | Blindaje mediante TLS/ECC y HMAC-SHA256 bajo la tríada CIA. |
| **Inteligencia de Negocio** | Modelo SaaS B2B, validación de mercado y Dashboards estratégicos. |
| **Gestión de Proyectos** | Ciclo de vida (12 semanas), presupuesto ($15,554 USD) y gobernanza de KPIs. |

## Objetivos del Proyecto

### Objetivo General
Desarrollar y desplegar una plataforma integral de monitoreo ambiental industrial de grado corporativo, basada en arquitectura de microservicios, para eliminar la "ceguera operativa" en el sector industrial, garantizando la seguridad laboral y la eficiencia mediante la toma de decisiones basada en evidencia.

### Objetivos Específicos (Ejes del ABP)
* **Infraestructura y Telemetría:** Implementar una red robusta de nodos sensores (AQC) basados en ESP32 para la captura precisa de variables críticas en entornos hostiles.
* **Ciberseguridad Industrial:** Blindar la integridad de los datos mediante protocolos MQTT sobre TLS con certificados ECC y autenticación dinámica HMAC-SHA256.
* **Resiliencia y Observabilidad:** Orquestar el ecosistema mediante contenedores Docker, automatización con Ansible y monitoreo avanzado (SRE) mediante Splunk Cloud.
* **Inteligencia de Negocio:** Desarrollar un Dashboard centralizado que transforme datos crudos en activos estratégicos bajo un modelo SaaS B2B.

## Parámetros de Desempeño y Validación (KPIs)
Para garantizar la calidad de la solución, cada componente de la arquitectura debe satisfacer los siguientes niveles de servicio:

| Categoría | Especificación Técnica |
| :--- | :--- |
| **Latencia (TRAC)** | Tiempo de respuesta ante alertas < 500ms. |
| **Eficiencia Técnica (IET)** | Índice de cumplimiento operativo ≥ 95%. |
| **Integridad (CFD)** | Trazabilidad del flujo de telemetría ≥ 95%. |
| **Confiabilidad (HCC)** | Estado de salud y avance de hitos planificados ≥ 90%. |

## Trazabilidad
Los requisitos aquí documentados son la base para el resto de los módulos del repositorio:
1. **Investigación:** Define el marco teórico para validar los parámetros técnicos.
2. **Prototipos:** Asegura que los componentes desarrollados cumplan con las especificaciones.
3. **Presentación:** Valida los resultados finales contra los KPIs establecidos.

---
*OmniSens Industrial Suite | Especificaciones, Requisitos de Ingeniería y Documentación ABP | ISPC.*

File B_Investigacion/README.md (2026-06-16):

(https://postimg.cc/2VrdBDD4)

# 📂 Directorio de Investigación: OmniSens Industrial Suite

## Descripción
Este directorio centraliza el marco de investigación y desarrollo conceptual aplicado a **OmniSens Industrial Suite**. La estructura organizada en esta carpeta recopila los fundamentos técnicos, la gestión de proyectos, el modelo de negocio y las estrategias de seguridad que sustentan el ciclo de vida del desarrollo.

## Estructura de la Investigación

| Carpeta | Enfoque Estratégico |
| :--- | :--- |
| **Aplicacion_al_proyecto_omnisens** | Implementación práctica y adecuación técnica al caso de uso. |
| **Gestion_de_proyectos** | Metodologías, flujos de trabajo y marcos de gestión aplicados. |
| **Modelo_negocios** | Análisis de mercado, viabilidad económica y escalabilidad. |
| **PPII** | Infraestructura Cloud, orquestación y observabilidad SRE (PPII). |
| **Seguridad_IoT** | Estrategias de ciberseguridad, integridad de datos y gestión de activos. |

## Objetivos del Directorio
* **Consolidar:** Unificar los pilares de investigación del proyecto bajo una estructura lógica.
* **Validar:** Proporcionar el sustento teórico necesario para cada componente del sistema.
* **Estandarizar:** Asegurar que tanto la documentación técnica como la operativa sigan los mismos criterios de calidad.

## Tecnologías y Metodologías
* **Metodologías Ágiles:** Gestión de proyectos orientada a resultados.
* **Industria 4.0:** Integración de estándares de seguridad y conectividad IoT.
* **Infraestructura:** Despliegue cloud y orquestación de servicios (SRE).
* **Análisis de Negocio:** Modelado de costos y propuesta de valor (Business Model Canvas).

---
*OmniSens Industrial Suite | Documentación de Investigación y Desarrollo | ISPC.*

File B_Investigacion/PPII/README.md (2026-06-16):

# ☁️ Infraestructura Cloud y Observabilidad (PPII)

## Descripción

Este directorio centraliza el diseño técnico y la arquitectura de infraestructura en la nube para el proyecto **OmniSens Industrial Suite**. El contenido aquí expuesto formaliza el análisis, la orquestación de servicios y la validación de la observabilidad, en cumplimiento con los estándares técnicos y operativos requeridos por la **Práctica Profesionalizante II (PPII)**.

## Documentos incluidos

📄 **4.1 Definir variables a monitorear.docx.pdf**

Documenta la matriz de telemetría y variables críticas capturadas por los nodos perimetrales.
*   **Contenido:**
    *   Definición de matriz de telemetría.
    *   Rangos operativos y lógica de ingesta de datos.
    *   Propósitos industriales de las variables.
*   **Objetivo:**
    *   Establecer la estructura base para el análisis analítico del sistema.

📄 **8.2 Diseñar flujo de datos completo del sistema.docx.pdf**

Documenta la topología lógica y el ciclo de vida del dato desde el Edge hacia la nube.
*   **Contenido:**
    *   Mapeo de la adquisición de datos.
    *   Transporte mediante protocolos MQTT.
    *   Ingesta en la infraestructura centralizada.
*   **Objetivo:**
    *   Validar la integridad del pipeline de datos y garantizar una comunicación eficiente en entornos industriales.

📄 **10.2 Documentar arquitectura técnica final.docx.pdf**

Documenta la especificación formal de la infraestructura cloud integrada y sus procedimientos de despliegue.
*   **Contenido:**
    *   Arquitectura de servicios sobre instancias AWS EC2.
    *   Orquestación de microservicios con Docker.
    *   Gestión de configuración mediante Ansible (IaC).
    *   Mapeo de conectividad y puertos críticos.
*   **Objetivo:**
    *   Consolidar la arquitectura tecnológica escalable y los mecanismos de despliegue automatizado.

🖼️ **Integración_de_monitoreo_en_nube.png**

Documenta la representación visual de la arquitectura de conectividad y observabilidad.
*   **Contenido:**
    *   Esquema topológico de AWS EC2 + Splunk Cloud.
    *   Mapa de puertos de comunicación (SSH, HTTP, TCP).
    *   Diagrama de flujo del Universal Forwarder para logs.
*   **Objetivo:**
    *   Validación gráfica de la arquitectura de red y la trazabilidad de logs.

## Tecnologías Relacionadas

* AWS EC2
* Docker / Docker Compose
* Ansible
* Splunk Cloud
* MQTT / SSH / HTTP

## Estado de la Documentación

✅ Matriz de variables definida

✅ Flujo de datos documentado

✅ Arquitectura de despliegue consolidada

✅ Integración técnica (AWS/Splunk) validada

🔄 Documentación en evolución junto con el desarrollo del proyecto.

*Práctica Profesionalizante II | Tecnicatura Superior en Telecomunicaciones (ISPC).*

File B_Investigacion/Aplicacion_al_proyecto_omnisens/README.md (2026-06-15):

# Aplicación al Proyecto – OmniSens Industrial Suite

## Descripción

Esta carpeta reúne la documentación relacionada con la aplicación práctica de los conceptos desarrollados durante el proyecto OmniSens Industrial Suite.

Su objetivo es evidenciar pruebas, validaciones, comportamientos operativos y resultados obtenidos durante la implementación de la solución IoT.

---

## Documentos incluidos

### 📄 resiliencia_operativa.md

Documenta la validación de resiliencia operativa del sistema ante fallas de conectividad.

Contenido:

- Simulación de caída de red.
- Verificación del procesamiento local.
- Validación de actuadores.
- Continuidad operativa.
- Comportamiento sin acceso al servidor.

Objetivo:

Comprobar que el sistema mantiene funciones críticas aun sin conectividad con servicios remotos.

Resultado esperado:

Garantizar la continuidad de monitoreo y control mediante procesamiento local.

---

## Estado de la Documentación

✅ Resiliencia Operativa documentada.

🔄 Documentación en evolución junto con el desarrollo del proyecto.

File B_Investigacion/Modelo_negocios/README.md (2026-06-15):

# Modelo de Negocio – OmniSens Industrial Suite

## Descripción

Esta carpeta reúne la documentación asociada al desarrollo del modelo de negocio de OmniSens Industrial Suite. Los documentos aquí contenidos permiten analizar la viabilidad económica, la propuesta de valor y las estrategias de generación de ingresos del proyecto.

La documentación se desarrolla utilizando conceptos del Business Model Canvas y herramientas de análisis empresarial orientadas a la validación del modelo de negocio.

---

## Documentos incluidos

### 📄 arpu.md

Documenta la estimación del ingreso promedio por usuario (ARPU) para OmniSens Industrial Suite.

Contenido:

- Análisis de mercado.
- Definición del rango USD 8–12.
- Justificación económica.
- Relación con costos.
- Aplicación según segmentos de clientes.

Objetivo:

Estimar ingresos recurrentes por usuario y validar la sostenibilidad financiera del modelo de negocio.

Resultado esperado:

Definir un ARPU coherente con la propuesta de valor y los costos operativos del proyecto.

---

## Estado de la Documentación

✅ Estimación de ARPU documentada.

✅ Estructura de Costos documentada.

🔄 Documentación en evolución junto con el desarrollo del Business Model Canvas.

---

### 📄 estructura_costos.md

Documenta la estructura de costos asociada al desarrollo y operación de OmniSens Industrial Suite.

Contenido:

- Costos de sensores y dispositivos.
- Costos de infraestructura de comunicaciones.
- Costos de servidores y servicios Cloud.
- Costos de mantenimiento.
- Costos energéticos.
- Clasificación CAPEX y OPEX.

Objetivo:

Identificar y organizar los costos asociados al proyecto para evaluar su viabilidad financiera.

Resultado esperado:

Disponer de una estructura de costos clara y coherente con el modelo de negocio propuesto.

---

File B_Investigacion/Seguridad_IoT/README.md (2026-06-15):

# 🔐 Seguridad IoT y Gestión de Vulnerabilidades

## Descripción

Esta carpeta contiene la documentación relacionada con la estrategia de seguridad implementada en OmniSens Industrial Suite. La seguridad constituye un componente fundamental del proyecto debido a que el sistema opera en entornos industriales donde la confiabilidad de la información y la protección de los activos son aspectos críticos para la continuidad operativa.

La documentación aquí presentada forma parte de las actividades desarrolladas dentro del backlog de Seguridad IoT y Gestión de Vulnerabilidades, aplicando principios de Seguridad desde el Diseño (Security by Design) y buenas prácticas de ciberseguridad para sistemas IoT e Industria 4.0.

---

## Documentos incluidos

### 📄 seguridad.md

Documenta la estrategia general de seguridad implementada en OmniSens Industrial Suite.

Contenido:

- Arquitectura de seguridad.
- Protección de dispositivos Edge (ESP32).
- Seguridad en comunicaciones MQTT.
- Seguridad del servidor y servicios Docker.
- Gestión de credenciales.
- Riesgos identificados.
- Estrategias de mitigación.
- Seguridad del ciclo de desarrollo.
- Material de apoyo para presentación.

Objetivo:

Garantizar la confidencialidad, integridad y disponibilidad de la información generada por el sistema.

---

### 📄 validacion_datos.md

Documenta los mecanismos utilizados para garantizar la integridad y confiabilidad de los datos ambientales capturados por los sensores.

Contenido:

- Validación de datos de sensores.
- Detección de anomalías.
- Verificación de rangos permitidos.
- Evaluación de consistencia.
- Controles de integridad.
- Relación con la arquitectura IoT.

Objetivo:

Evitar que datos incorrectos, corruptos o manipulados afecten la toma de decisiones y los procesos de automatización.

---

## Relación con el Proyecto OmniSens

La seguridad en OmniSens no se limita únicamente a la protección de datos digitales. Su propósito es garantizar la confiabilidad de la telemetría, proteger la infraestructura tecnológica y contribuir a la seguridad operativa de los entornos monitoreados.

Las medidas implementadas permiten:

- Reducir riesgos operativos.
- Detectar fallas de sensores.
- Prevenir manipulaciones de datos.
- Proteger las comunicaciones.
- Mejorar la resiliencia del sistema.
- Fortalecer la toma de decisiones basada en información confiable.

---

## Tecnologías Relacionadas

- ESP32
- MQTT
- LoRa
- Docker
- Node-RED
- MariaDB
- Grafana
- GitHub Projects
- GitHub Advanced Security

---

## Estado de la Documentación

✅ Estrategia de Seguridad Documentada

✅ Validación e Integridad de Datos Documentada

✅ Rotación de Credenciales y Gestión de Tokens Documentada

🔄 Documentación en evolución junto con el desarrollo del proyecto.

---

### 📄 rotacion_credenciales.md

Documenta la estrategia de gestión segura de credenciales y renovación de tokens implementada en OmniSens Industrial Suite.

Contenido:

* Política de rotación de credenciales.
* Renovación periódica de tokens.
* Automatización de cambios.
* Revocación de credenciales comprometidas.
* Gestión segura de accesos.
* Aplicación en MQTT, APIs, Docker y Base de Datos.
* Procedimientos documentados de respuesta ante incidentes.

Objetivo:

Reducir los riesgos asociados a la exposición de claves, contraseñas y tokens mediante la utilización de credenciales dinámicas y mecanismos de renovación controlados.

Resultado esperado:

Fortalecer la seguridad del sistema, minimizar el impacto de posibles filtraciones y garantizar una gestión segura de accesos dentro de la arquitectura OmniSens.

---

### 📄 code_scanning.md

Documenta la estrategia de análisis de seguridad aplicada al código fuente del proyecto.

Contenido:

- Code Scanning en GitHub.
- Revisión del firmware ESP32.
- Análisis de dependencias.
- Identificación de vulnerabilidades.
- Aplicación de correcciones.
- Buenas prácticas de desarrollo seguro.

Objetivo:

Detectar y corregir vulnerabilidades de software antes de su despliegue.

Resultado esperado:

Incrementar la calidad, seguridad y confiabilidad del código fuente utilizado por OmniSens Industrial Suite.

---

### 📄 gestion_secretos.md

Documenta la estrategia de protección de credenciales y gestión segura de secretos utilizada en OmniSens Industrial Suite.

Contenido:

- Identificación de credenciales críticas.
- Eliminación de credenciales hardcodeadas.
- Uso de variables de entorno.
- Protección de accesos.
- Escaneo automático de secretos.
- Buenas prácticas de gestión de información sensible.

Objetivo:

Evitar la exposición de credenciales dentro del código fuente y proteger los componentes críticos de la infraestructura.

Resultado esperado:

Mantener el repositorio libre de datos sensibles y reducir riesgos asociados a accesos no autorizados.

---

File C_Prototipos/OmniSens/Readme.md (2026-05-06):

# 📂 OmniSens: Plataforma Edge-to-Cloud de Grado Industrial

**OmniSens** es una plataforma integral de Internet de las Cosas (IoT) diseñada para la captura de telemetría ambiental, automatización remota y gestión de dispositivos en tiempo real. Este repositorio contiene el código fuente completo del proyecto, estructurado para entornos de producción.

---

## 🏗️ Arquitectura Actual de la Plataforma

El sistema ha sido reescrito desde sus prototipos iniciales para cumplir con los más altos estándares de eficiencia, escalabilidad e Infraestructura como Código (IaC). El flujo de trabajo y los componentes tecnológicos son los siguientes:

### 1. 📟 Firmware Edge (Nodo Sensor / Actuador)
- **Hardware:** Microcontrolador **ESP32** interactuando con sensores (MQ135, AHT25, BMP280, LDR) y salidas de potencia (Relés, PWM).
- **Firmware (C++ con FreeRTOS):** Arquitectura *Zero-Blocking* basada en tareas de RTOS. Integración nativa de Watchdog Timer (TWDT) para resiliencia frente a fallas.
- **Red y Portal Cautivo:** Usa `WiFiManager` asíncrono para aprovisionamiento de red sin credenciales hardcodeadas, gatillable mediante hardware (botón BOOT).
- **Directorio:** `/Dispositivos/controlador_edge_v01mqtt/Omnisens_AQC`

### 2. 📡 Capa de Transporte y Aprovisionamiento (MQTT)
- **Broker MQTT:** **EMQX** corriendo en Docker.
- **Zero-Touch Provisioning:** Los dispositivos se auto-registran utilizando su MAC address. El backend verifica en base de datos y provee un token criptográfico dinámico (HMAC-SHA256) limitando el acceso de las placas (Sandboxing mediante ACLs).

### 3. ⚙️ Backend (API y Persistencia)
- **API REST:** Microservicio hiper-rápido construido con **Node.js, TypeScript y Fastify**.
- **Base de Datos:** **PostgreSQL + extensión TimescaleDB** (optimizado para inmensos volúmenes de datos temporales). Operado de forma ligera mediante el query builder `Kysely`.
- **Seguridad:** Middleware Multi-tenant que garantiza el aislamiento de datos entre clientes mediante tokens JWT.
- **Directorio:** `/backend`

### 4. 📊 Frontend (Dashboard)
- **Stack:** **Vue 3 (Composition API) + Vite + Tailwind CSS**.
- **Analíticas:** Integración del motor **Apache ECharts** para renderizado eficiente de historiales de datos masivos.
- **Directorio:** `/frontend`

### 5. 🚀 Despliegue y Orquestación (IaC)
- **Docker Compose:** Todos los servicios (Frontend, Backend, Postgres, EMQX) están unificados en un `docker-compose.yml` maestro ubicado en la raíz.
- **Automatización Ansible:** Playbooks configurados para sincronizar ramas, inyectar credenciales seguras (plantillas `.env.j2`) y reiniciar contenedores en caliente de forma remota sobre nodos Linux.
- **Reverse Proxy:** Plantillas de enrutamiento para Nginx Maestro.
- **Directorio:** `/Despliegue` y `/configuraciones`

---

## 📁 Estructura del Repositorio

| Directorio | Descripción |
| :--- | :--- |
| `/backend` | Código fuente del microservicio Fastify (Node.js/TS). |
| `/frontend` | Código fuente de la Interfaz Web de usuario (Vue/Vite). |
| `/Dispositivos` | Firmware C++ de las placas Edge (PlatformIO). |
| `/Despliegue` | Playbooks de Ansible para la automatización en Producción. |
| `/configuraciones` | Plantillas para Ingress (Nginx) y listas de acceso MQTT (EMQX). |
| `/docs` | Documentación técnica profunda, diccionarios de BD y arquitectura. |
| `/_archive` | Carpeta de legado con componentes y pruebas de concepto de fases iniciales. |

---

## 🔒 Notas de Seguridad
Por razones de seguridad, **no existen credenciales vivas en este repositorio**. 
- En el caso del Firmware, los tokens MQTT son aprovisionados de forma dinámica y la clave WiFi se configura vía portal cautivo.
- En el caso de la Infraestructura, las claves de BD y JWT se inyectan a través de secretos/variables de entorno en el servidor de despliegue mediante plantillas bloqueadas (`.env.j2`).

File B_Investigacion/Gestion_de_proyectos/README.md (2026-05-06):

# 🌍 OmniSens - Sistema de Monitoreo Ambiental IoT

## 📌 Descripción del Proyecto

OmniSens es una solución de monitoreo y control ambiental basada en IoT orientada a entornos industriales, ciudades inteligentes y aplicaciones residenciales. 

Permite capturar variables críticas del entorno, procesarlas en tiempo real y ejecutar acciones automáticas que mejoran la seguridad, eficiencia operativa y toma de decisiones.

---

## 🎯 Objetivos

- Monitoreo multivariable (temperatura, humedad, presión, gases, luminosidad)
- Automatización de actuadores (extractores, alarmas, relays)
- Visualización en tiempo real mediante dashboards
- Generación de datos históricos para análisis
- Mejora de seguridad operativa

---

## 🧠 Arquitectura del Sistema

El sistema se basa en una arquitectura de 3 capas:

### 🔹 Edge (Nodos ESP32)
- Lectura de sensores
- Procesamiento local
- Activación de actuadores

### 🔹 Red (WIfi/ MQTT)
- Comunicación de largo alcance
- Baja latencia para eventos críticos

### 🔹 Servidor (Docker)
- Node-RED (lógica)
- Base de datos (persistencia)
- Grafana (visualización)

---

## 🔄 Flujo de Datos

Sensor → ESP32 → MQTT → Node-RED → Base de datos → Grafana

---

## ⚙️ Metodología de Trabajo

Se implementa una metodología ágil basada en:

- Kanban (GitHub Projects)
- Gestión mediante Issues
- Organización por Milestones
- Seguimiento de tareas por estados

---

## 📊 Tablero de Gestión

El proyecto se gestiona mediante un tablero Kanban con las siguientes columnas:

- Backlog
- Por hacer
- En progreso
- En revisión
- Bloqueado
- Hecho

---

## 🧩 Organización del Equipo

- Coordinación general del proyecto
- Desarrollo embebido (ESP32)
- Backend y comunicaciones
- Gestión de datos y visualización
- Documentación y presentación

---

## 💰 Modelo de Negocio

OmniSens adopta un modelo híbrido:

- Suscripción mensual (SaaS)
- Servicios de análisis para empresas
- Plataforma para integración con terceros

Segmentos:
- Residencial
- Corporativo (B2B)
- Gobierno / Smart Cities

---

## 🔐 Seguridad

Se implementan medidas de seguridad en múltiples niveles:

- Protección de credenciales
- Cifrado en comunicaciones (TLS/SSL)
- Autenticación en API
- Validación de datos
- Análisis de vulnerabilidades

---

## ⚠️ Gestión de Riesgos

Se identifican riesgos técnicos, operativos y de seguridad con estrategias de mitigación.

---

## 🚀 Estado del Proyecto

Actualmente en desarrollo bajo metodología ágil con backlog estructurado y tareas en ejecución.

---

## 📎 Repositorio

👉 Este repositorio contiene:
- Gestión del proyecto
- Documentación técnica
- Modelo de negocio
- Estrategia de seguridad

---

## 👥 Equipo

Proyecto desarrollado en el marco de la Tecnicatura Superior en Telecomunicaciones (ISPC).

---

## 📌 Conclusión

OmniSens representa una solución integral que combina IoT, automatización y analítica de datos para transformar la gestión ambiental en entornos modernos.

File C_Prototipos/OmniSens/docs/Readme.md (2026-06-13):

# 📚 Documentación Técnica de OmniSens

Este directorio contiene la documentación técnica profunda sobre la arquitectura, base de datos, seguridad, despliegue y firmware de la plataforma IoT OmniSens.

## 🗂️ Índice de Documentación

A continuación se describen los documentos disponibles en este directorio:

| Documento | Descripción |
| :--- | :--- |
| [🏗️ Arquitectura y Funcionalidades](file:///c:/Users/Fernando/Desktop/Desktop/tecnicaturas/telecomunicaciones/AA_New_folder/Estrategia-y-Gesti-n-de-Proyectos-para-Soluciones-IoT-/C_Prototipos/OmniSens/docs/arquitectura_y_funcionalidades.md) | **Documento Principal.** Detalla la arquitectura global del sistema (Edge-to-Cloud), capa de transporte MQTT, persistencia, seguridad multitenant y un análisis exhaustivo del frontend con propuestas de refactorización. |
| [📟 Arquitectura del Firmware](file:///c:/Users/Fernando/Desktop/Desktop/tecnicaturas/telecomunicaciones/AA_New_folder/Estrategia-y-Gesti-n-de-Proyectos-para-Soluciones-IoT-/C_Prototipos/OmniSens/docs/Firmware_Architecture.md) | Detalla la estructura del firmware C++ (PlatformIO) ejecutado en el ESP32, incluyendo multitarea con FreeRTOS, Watchdog (TWDT) y aprovisionamiento Zero-Touch. |
| [💾 Diccionario de Base de Datos](file:///c:/Users/Fernando/Desktop/Desktop/tecnicaturas/telecomunicaciones/AA_New_folder/Estrategia-y-Gesti-n-de-Proyectos-para-Soluciones-IoT-/C_Prototipos/OmniSens/docs/Diccionario_Base_de_Datos.md) | Describe el esquema relacional de PostgreSQL, el uso de hipertablas de TimescaleDB, vistas multitenant, continuous aggregates (promedios horarios) y stored procedures. |
| [🔑 Estrategia JWT Multi-Tenant](file:///c:/Users/Fernando/Desktop/Desktop/tecnicaturas/telecomunicaciones/AA_New_folder/Estrategia-y-Gesti-n-de-Proyectos-para-Soluciones-IoT-/C_Prototipos/OmniSens/docs/Estrategia_JWT_MultiTenant.md) | Detalla el diseño del payload del JWT y el flujo de aislamiento de datos en las consultas REST del Backend. |
| [💻 Guía de Despliegue Local](file:///c:/Users/Fernando/Desktop/Desktop/tecnicaturas/telecomunicaciones/AA_New_folder/Estrategia-y-Gesti-n-de-Proyectos-para-Soluciones-IoT-/C_Prototipos/OmniSens/docs/Guia_Despliegue_Local.md) | Manual de instrucciones para levantar el entorno de desarrollo local con Docker Desktop y probar la ingesta mediante clientes MQTT (MQTTX). |
| [🔒 Generar Certificados TLS](file:///c:/Users/Fernando/Desktop/Desktop/tecnicaturas/telecomunicaciones/AA_New_folder/Estrategia-y-Gesti-n-de-Proyectos-para-Soluciones-IoT-/C_Prototipos/OmniSens/docs/Generar_Certificados_TLS.md) | Guía técnica para la generación de certificados SSL/TLS autofirmados para el cifrado de comunicaciones en el Broker EMQX (MQTTS). |
| [🧾 Presupuesto y Componentes](file:///c:/Users/Fernando/Desktop/Desktop/tecnicaturas/telecomunicaciones/AA_New_folder/Estrategia-y-Gesti-n-de-Proyectos-para-Soluciones-IoT-/C_Prototipos/OmniSens/docs/Listado_Componentes_y_Recursos_Presupuesto.md) | Listado y presupuesto detallado de los sensores, actuadores y microcontroladores utilizados para la construcción de los nodos físicos. |

---

## 🛠️ Próximos Pasos en el Frontend

Para realizar los ajustes en el frontend referenciados en el documento de [Arquitectura y Funcionalidades](file:///c:/Users/Fernando/Desktop/Desktop/tecnicaturas/telecomunicaciones/AA_New_folder/Estrategia-y-Gesti-n-de-Proyectos-para-Soluciones-IoT-/C_Prototipos/OmniSens/docs/arquitectura_y_funcionalidades.md#6-diagnóstico-y-plan-de-refactorización-del-frontend):
1. Levantar el stack local de Docker Compose (`docker compose up --build -d`).
2. Acceder al directorio `/frontend` y ejecutar `npm install` para asegurar que las dependencias están al día.
3. Descomentar progresivamente las llamadas de la API Axios (`api.ts`) en las vistas correspondientes (`DashboardView.vue`, `DeviceManagerView.vue`, `AnalyticsView.vue`, `RulesEngineView.vue`).
4. Reemplazar los datos estáticos (*mock*) por las respuestas dinámicas devueltas por los endpoints de la API.

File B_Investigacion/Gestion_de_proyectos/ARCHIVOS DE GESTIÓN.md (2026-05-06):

# Backlog del Proyecto OmniSens

## Épicas

- Visión estratégica
- Arquitectura IoT
- Modelo de negocio
- Seguridad IoT

## Gestión

Las tareas se administran mediante GitHub Issues y Kanban.

# Matriz de Riesgos

| Riesgo | Impacto | Probabilidad | Mitigación |
|---|---|---|---|
| Fallo de sensores | Alto | Medio | Redundancia |
| Caída de red | Alto | Medio | Control local |
| Error humano | Medio | Alto | Automatización |
| Ataques de seguridad | Alto | Bajo | Cifrado + autenticación |

# Roadmap

## Fase 1
Organización y planificación

## Fase 2
Definición de arquitectura

## Fase 3
Desarrollo del sistema

## Fase 4
Integración y pruebas

## Fase 5
Presentación final

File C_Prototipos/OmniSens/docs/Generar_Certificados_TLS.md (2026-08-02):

# Generación de Certificados TLS (Ed25519) para OmniSens

Para cumplir con la filosofía "Security by Design", la comunicación entre los dispositivos Edge (ESP32) y el Broker MQTT (EMQX) debe realizarse a través de MQTTS (puerto 8883) utilizando certificados TLS.

Para dispositivos con recursos limitados como el ESP32, el uso de criptografía de curva elíptica, específicamente el algoritmo **Ed25519**, ofrece un rendimiento significativamente superior (validación de firmas más rápida y uso reducido de memoria RAM/CPU) comparado con el tradicional RSA-2048.

A continuación se detallan los comandos de `openssl` necesarios para generar la Autoridad Certificante (CA) raíz y los certificados del servidor.
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

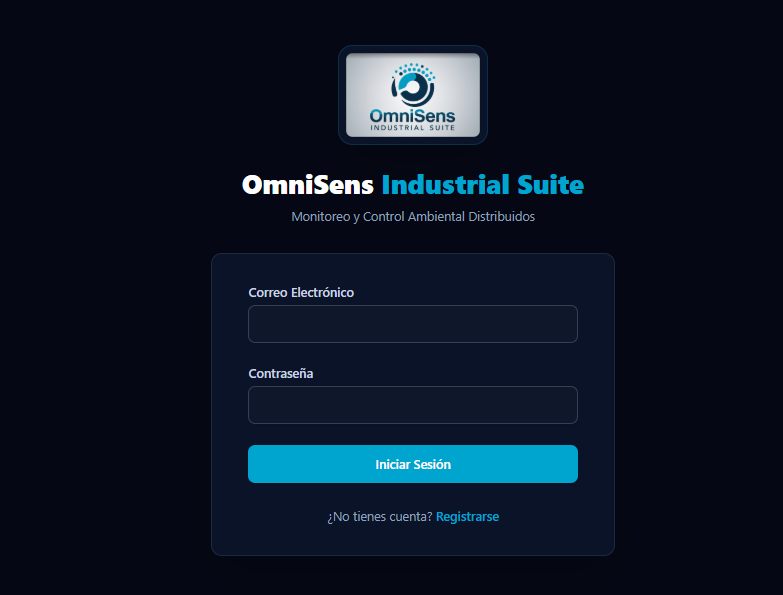
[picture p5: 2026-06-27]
C_Prototipos/OmniSens/docs/login.png

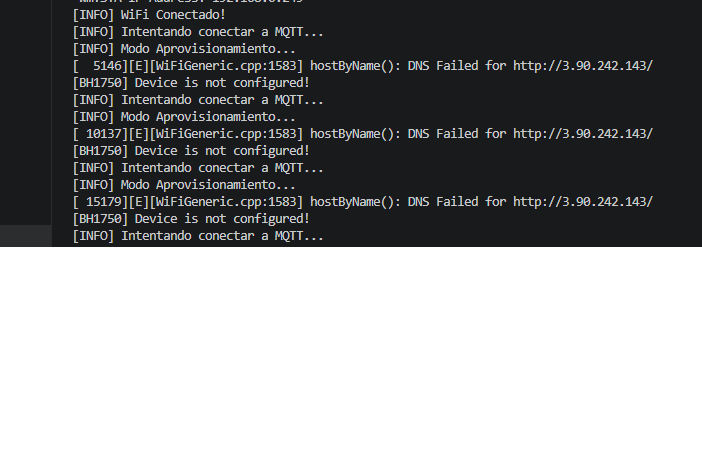
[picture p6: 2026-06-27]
C_Prototipos/OmniSens/docs/sandbox.png

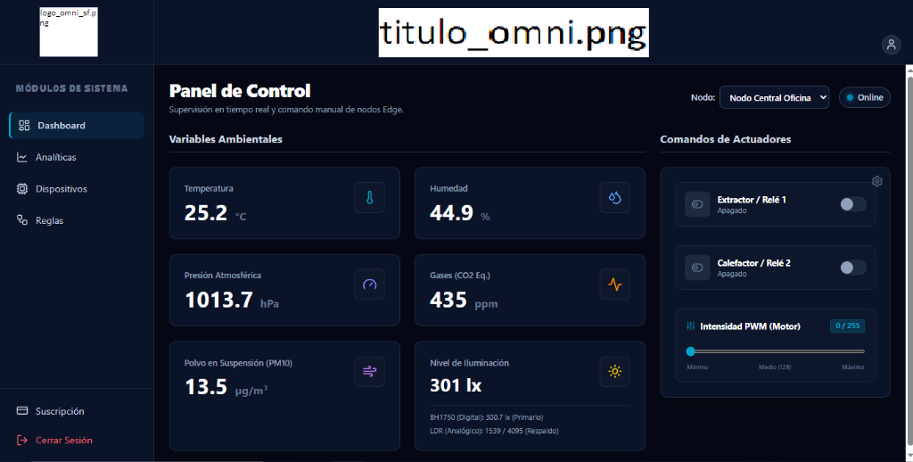
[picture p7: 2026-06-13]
C_Prototipos/OmniSens/frontend/src/assets/indicaciones.png

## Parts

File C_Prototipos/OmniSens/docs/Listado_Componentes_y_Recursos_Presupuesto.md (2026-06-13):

# 📋 Listado de Componentes de Hardware y Recursos para el Presupuesto - OmniSens

Este documento detalla el listado de materiales (BOM - Bill of Materials) y los recursos necesarios para el desarrollo, producción, despliegue y mantenimiento del ecosistema **OmniSens**. La información ha sido recopilada y consolidada a partir del estado de desarrollo actual del proyecto (firmware C++ en PlatformIO, backend de producción en Fastify, frontend en Vue 3 y orquestación con Docker Compose).

---

## 1. Componentes de Hardware (BOM por Nodo Edge)

El nodo de hardware **OmniSens AQC** (Air Quality Controller) está basado en el microcontrolador ESP32 y se encarga del sensado ambiental de múltiples variables, así como del accionamiento local y remoto de actuadores.

A continuación se detallan los componentes individuales de hardware requeridos para la fabricación de **un (1) nodo Edge**:

### 1.1. Unidad de Procesamiento y Comunicaciones
| Componente | Descripción / Modelo Técnico | Función | Conexión / Interfaz | Cantidad |
| :--- | :--- | :--- | :--- | :--- |
| **Microcontrolador** | ESP32 Development Board (NodeMCU-32S / ESP-WROOM-32) | Procesamiento principal, ejecución de tareas FreeRTOS, servidor web local y cliente WiFi/MQTT. | CPU Core | 1 |
| **Módulo LoRa (Opcional/Legacy)** | SX1278 (433 MHz) con antena externa | Enlace de comunicación de largo alcance para áreas sin cobertura WiFi (diseño heredado disponible). | SPI | 1 (Opcional) |

### 1.2. Sensores (Monitoreo Ambiental)
| Componente | Modelo Técnico | Rango / Variable de Medición | Interfaz | Cantidad |
| :--- | :--- | :--- | :--- | :--- |
| **Sensor de Calidad de Aire** | MQ135 | Concentración de gases nocivos (CO2, alcohol, benceno, humo, NOx). | Analógica (GPIO 39) | 1 |
| **Sensor de Temp. y Humedad** | AHT25 (o AHT20/AHT10) | Humedad relativa (0-100%) y temperatura (-40 a 85 °C). Alta precisión. | I2C (SDA 21 / SCL 22) | 1 |
| **Sensor de Presión y Temp.** | BMP280 | Presión barométrica (300-1100 hPa) y temperatura. | I2C (SDA 21 / SCL 22) | 1 |
| **Sensor de Intensidad Lumínica**| BH1750 | Intensidad de luz ambiente (0-65535 Lux). | I2C (SDA 21 / SCL 22) | 1 |
| **Sensor de Polvo / PM2.5** | Sharp GP2Y1010AU0F (o GP2Y1014AU0F) | Concentración de material particulado. | Analógica (AOUT 34 / ILED 4) | 1 |
| **Sensor de Luz Simple** | LDR (Fotorresistencia) | Sensor analógico complementario de luminosidad. | Analógica (GPIO 36) | 1 |
| **Sensor UV (Opcional)** | ML8511 | Intensidad de radiación ultravioleta. | Analógica (GPIO 33) | 1 (Opcional) |

### 1.3. Actuadores y Señalización Local
| Componente | Modelo Técnico | Función | Interfaz | Cantidad |
| :--- | :--- | :--- | :--- | :--- |
| **Módulo de Relés** | Módulo de 2 canales con optoacoplador | Control de cargas de potencia ON/OFF (por ejemplo: extractores, electroválvulas). | Digital (GPIO 33 / GPIO 25) | 1 |
| **Driver PWM** | Transistor MOSFET de potencia (ej. IRF540N) | Regulación de velocidad para motor de ventilación/extractor. | PWM (GPIO 32) | 1 |
| **Baliza Lumínica** | Tira LED RGB WS2812B (NeoPixel) | Indicación visual del estado del AQI (Índice de Calidad de Aire) y alertas del sistema. | Digital (GPIO 39) | 1 |
| **Alarma Sonora** | Buzzer Activo de 5V | Señalización audible de superación de umbrales críticos. | Digital (GPIO 2 / pin compartido) | 1 |
| **Pantalla Local (Opcional)** | Display LCD 16x2 o 20x4 con adaptador I2C | Visualización local de lecturas de sensores para el operador. | I2C (SDA 21 / SCL 22) | 1 (Opcional) |

### 1.4. Alimentación y Misceláneos
| Componente | Tipo / Especificaciones | Función | Cantidad |
| :--- | :--- | :--- | :--- |
| **Fuente de Alimentación** | Transformador switching 110V/220V a 5V DC (mínimo 2A) o fuente industrial riel DIN. | Alimentar la placa ESP32, los relés y los sensores de forma estable. | 1 |
| **PCB a medida** | Placa de circuito impreso de 2 capas (FR4) | Integración física y eléctrica de todos los componentes, bornes y conectores. | 1 |
| **Gabinete / Carcasa** | Caja estanca IP65/IP67 o gabinete riel DIN con partes impresas en 3D (PLA/PETG). | Protección contra intemperie y polvo industrial. | 1 |
| **Elementos de Conexión** | Bornes de tornillo (tipo KF301), headers hembra/macho, cables Dupont, zócalos. | Conectores para fácil mantenimiento de sensores y reemplazo de placa. | 1 set |
| **Botón de Configuración** | Pulsador momentáneo (o uso del botón BOOT integrado) | Acceso físico para gatillar el portal cautivo del `WiFiManager`. | 1 |

---

## 2. Recursos de Infraestructura de Software y Servidores

El presupuesto del proyecto debe incluir el costo de despliegue y mantenimiento mensual/anual de la plataforma en la nube o en servidores locales (*on-premise*).

### 2.1. Entorno de Servidor (Producción Cloud/VPS)
- **Servidor Cloud VPS**: Instancia en proveedores como AWS, DigitalOcean, Linode o Azure.
  - *Requerimientos mínimos*: 2 vCPUs, 4 GB de RAM, 80 GB SSD (para albergar contenedores Docker y datos históricos).
- **Servicio de Respaldos (Backups)**: Almacenamiento automatizado de la base de datos (por ejemplo, AWS S3 o volumen de bloques externo).

### 2.2. Componentes de Software (Stack Tecnológico Open-Source)
No conllevan costos de licencias comerciales directa, pero requieren recursos para administración y hosting:
- **Broker MQTT (EMQX)**: Orquestación del tráfico de mensajes de telemetría y comandos con TLS (Puerto 8883).
- **Base de Datos (TimescaleDB / PostgreSQL)**: Almacenamiento de series temporales altamente optimizado para las métricas recolectadas.
- **Backend API (Fastify / TypeScript)**: Microservicio encargado de la lógica de negocio, autenticación multi-tenant (JWT) y provisionamiento de seguridad (HMAC-SHA256).
- **Frontend Dashboard (Vue 3 / Vite)**: Interfaz de usuario con paneles interactivos e históricos analíticos basados en Apache ECharts.
- **Proxy Inverso y Cifrado (Nginx + Certbot/Let's Encrypt)**: Enrutamiento seguro del tráfico web (HTTPS) y MQTT sobre TLS.

### 2.3. Herramientas de Despliegue e IaC
- **Ansible**: Automatización del despliegue en producción sobre servidores Linux de forma desasistida.
- **Docker y Docker Compose**: Virtualización de todos los servicios para garantizar consistencia entre desarrollo y producción.

---

## 3. Herramientas de Laboratorio y Desarrollo (Inversión Inicial)

Para realizar el armado de prototipos, soldadura, pruebas eléctricas y calibración de sensores se requiere el siguiente equipamiento de laboratorio (inversión única de capital - CAPEX):

- **Instrumental de Medición y Pruebas**:
  - Multímetro digital de precisión (para verificar voltajes de alimentación de sensores de 3.3V y 5V).
  - Osciloscopio digital (opcional, útil para auditar señales PWM y el bus I2C).
  - Fuente de alimentación regulable de laboratorio (0-30V, 0-5A) con limitación de corriente.
- **Herramientas de Ensamblaje y Soldadura**:
  - Estación de soldado regulable en temperatura y extractor de humo.
  - Estaño de buena calidad, flux y mallas desoldadoras.
  - Pinzas de precisión, alicates de corte, pelacables y crimpeadora de conectores.
- **Equipamiento de Fabricación Rápida**:
  - Impresora 3D (tecnología FDM, ej: Ender 3 o similar) y filamento (PETG o ABS por resistencia térmica/química) para la creación de gabinetes y soportes.

---

## 4. Recursos Humanos y Roles de Desarrollo

El desarrollo integral y puesta en marcha del proyecto requiere de un equipo multidisciplinario. En el presupuesto se deben proyectar las horas de desarrollo o salarios para los siguientes perfiles:

1. **Ingeniero de Sistemas Embebidos / Firmware Developer (C++/RTOS)**:
   - *Tareas*: Programación del ESP32, gestión de tareas multihilo en FreeRTOS, lectura no bloqueante de sensores, calibración de sensores analógicos (MQ135, Sharp polvo), implementación del portal cautivo y seguridad de aprovisionamiento por MQTT.
2. **Diseñador de Hardware / PCB Designer**:
   - *Tareas*: Diseño del esquemático del circuito, ruteado de la PCB (dos capas con planos de tierra adecuados), generación de archivos Gerber y optimización para fabricación industrial.
3. **Desarrollador Backend & DBA (Node.js/Fastify/TimescaleDB)**:
   - *Tareas*: Creación de APIs REST, optimización de consultas de series temporales con Kysely/SQL, desarrollo de la estrategia multi-tenant y lógica de seguridad de firmas HMAC-SHA256 para placas.
4. **Desarrollador Frontend (Vue 3/Vite/ECharts)**:
   - *Tareas*: Diseño del portal web responsive, integración de gráficas de alto rendimiento en tiempo real para variables ambientales e interfaz de control de actuadores.
5. **Ingeniero DevOps / SysAdmin**:
   - *Tareas*: Configuración del servidor de producción, despliegue con Docker Compose, automatización con playbooks de Ansible, gestión de certificados SSL (Let's Encrypt), políticas de firewall y hardening del broker EMQX.
6. **Diseñador Industrial (Carcasa 3D)**:
   - *Tareas*: Modelado 3D del gabinete protector, diseño de soportes de sensores para flujo de aire adecuado y preparación de archivos listos para impresión 3D o inyección de plástico.

---

## 5. Costos Operativos de Terceros y Logística (OPEX / CAPEX)

- **Servicios de Fabricación de PCBs**: Fabricación de prototipos y lotes en fábricas especializadas (ej. JLCPCB, PCBWay), incluyendo envío internacional.
- **Servicios de Ensamble (SMT/THT)**: Soldadura manual o automatizada de los componentes en la placa.
- **Servicio de Hosting de Dominios y SSL**: Compra del dominio del proyecto (ej: `.org` o `.com`) y certificados si se requiere una entidad certificadora comercial.
- **Certificaciones (Opcional - Fase Industrial)**: Ensayos de compatibilidad electromagnética (EMC) y certificaciones eléctricas si el producto se comercializa industrialmente.

---
> [!IMPORTANT]
> **Consideración Crítica de Presupuesto:**
> Los sensores analógicos como el **MQ135** y el **Sharp de Polvo (GP2Y1010AU0F)** requieren un tiempo de precalentamiento inicial (burn-in time) y calibraciones periódicas en campo utilizando filtros de media móvil implementados en firmware. Se debe considerar en el presupuesto el costo de calibración y el reemplazo preventivo de los sensores de gas (vida útil estimada de 1.5 a 2 años en ambientes industriales).

> [!TIP]
> **Optimización de Costos en Producción:**
> El aprovisionamiento automático (*Zero-Touch Provisioning*) integrado en el firmware del ESP32 a través de HMAC-SHA256 permite reducir drásticamente los costos de soporte e instalación técnica en campo, ya que los nodos se configuran dinámicamente al conectarse por primera vez a la red WiFi del cliente mediante el portal cautivo.

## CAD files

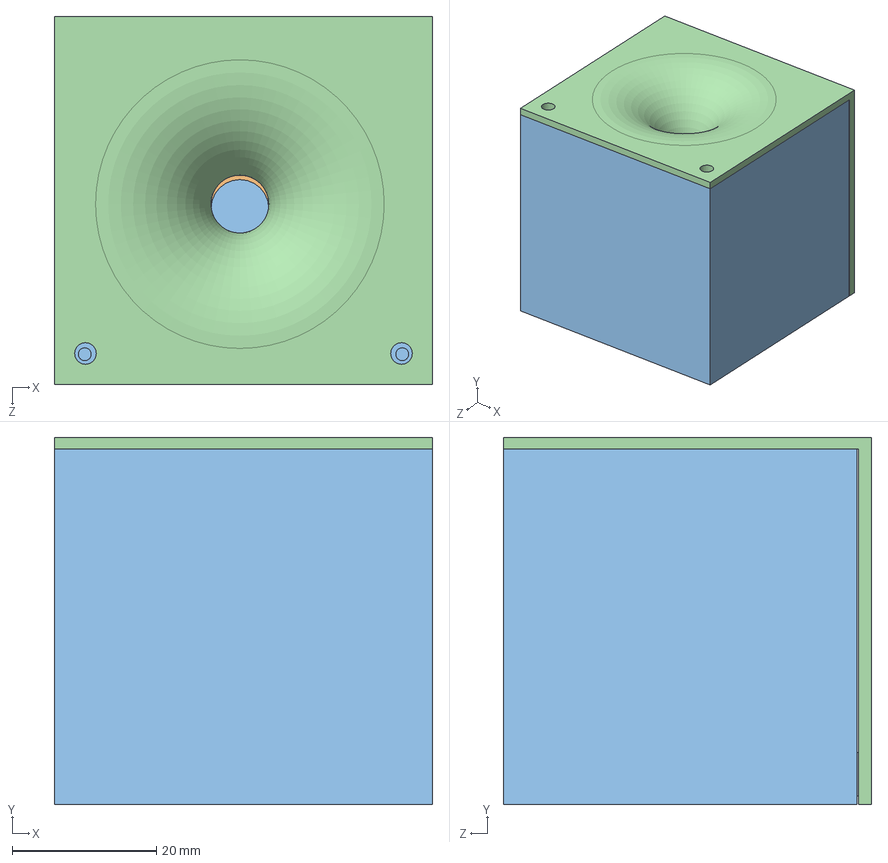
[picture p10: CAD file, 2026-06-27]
C_Prototipos/OmniSens/Dispositivos/Modelos 3D/chasis_2_0/sensores/assy_dust_chim.SLDASM
52.4 x 50.9 x 51.0 mm
forzador
Dust sensor GP2Y1010AU0F
chimenea_dust
tapa_dust_chim

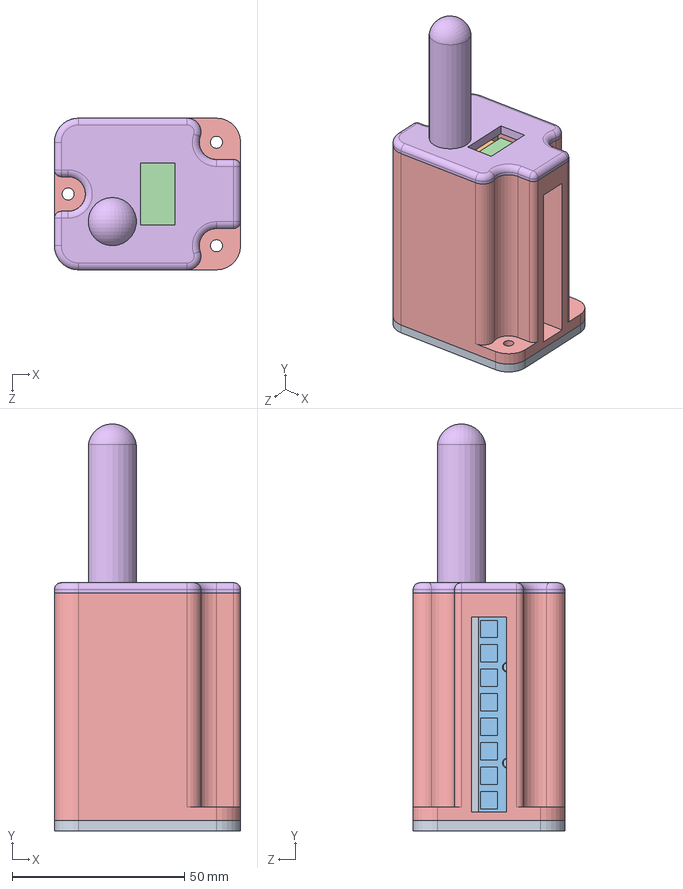
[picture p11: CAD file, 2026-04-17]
C_Prototipos/OmniSens/Dispositivos/Modelos 3D/modulo_baliza_Lora.SLDASM
54.0 x 118.0 x 44.0 mm
base_baliza_LDR_LoRa
modulo_LoRa
tiraLedWS2812
sensor LDR
carcasa_modulo_baliza
tapa_sup_antena

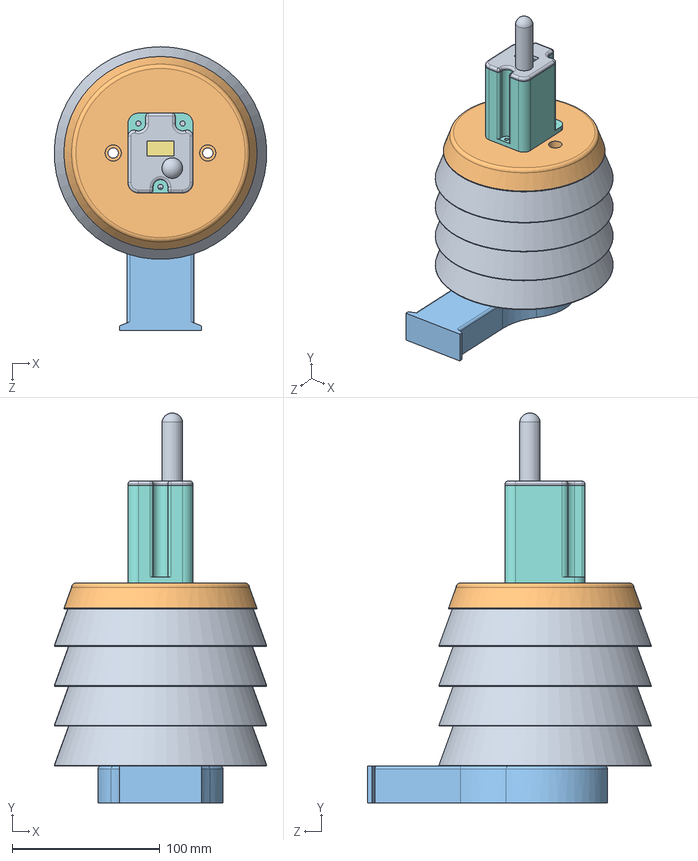
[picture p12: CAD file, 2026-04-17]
C_Prototipos/OmniSens/Dispositivos/Modelos 3D/modelo_prototipo.SLDASM
143.8 x 264.0 x 191.9 mm
modulo_porta_componente x 4
Tapa_superior_con_ventana
carcasa_sup_base
base_baliza_LDR_LoRa
modulo_LoRa
tiraLedWS2812
sensor LDR
carcasa_modulo_baliza
tapa_sup_antena

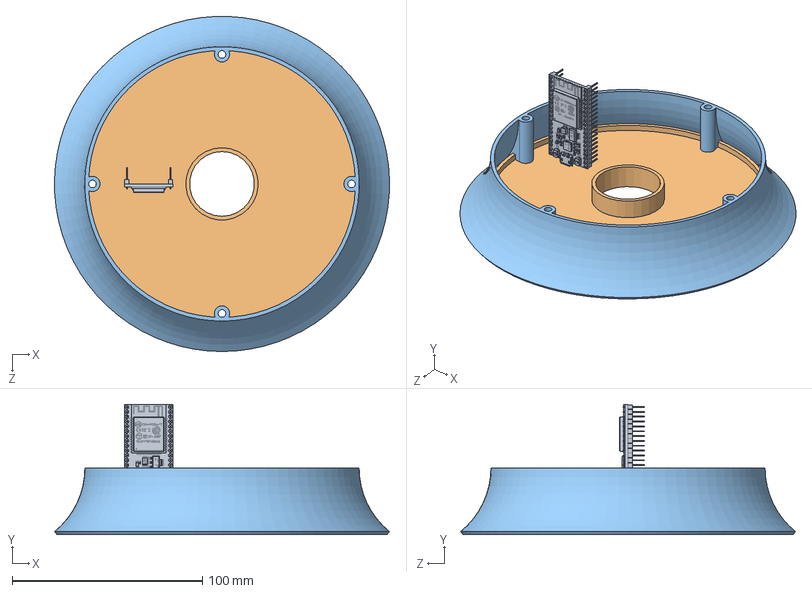
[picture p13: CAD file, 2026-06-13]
C_Prototipos/OmniSens/Dispositivos/Modelos 3D/chasis_2_0/sensores/modelo_2_0.SLDASM
175.9 x 68.3 x 175.9 mm
ESP32_Wroom_32S
techo_sens
ext_aleta

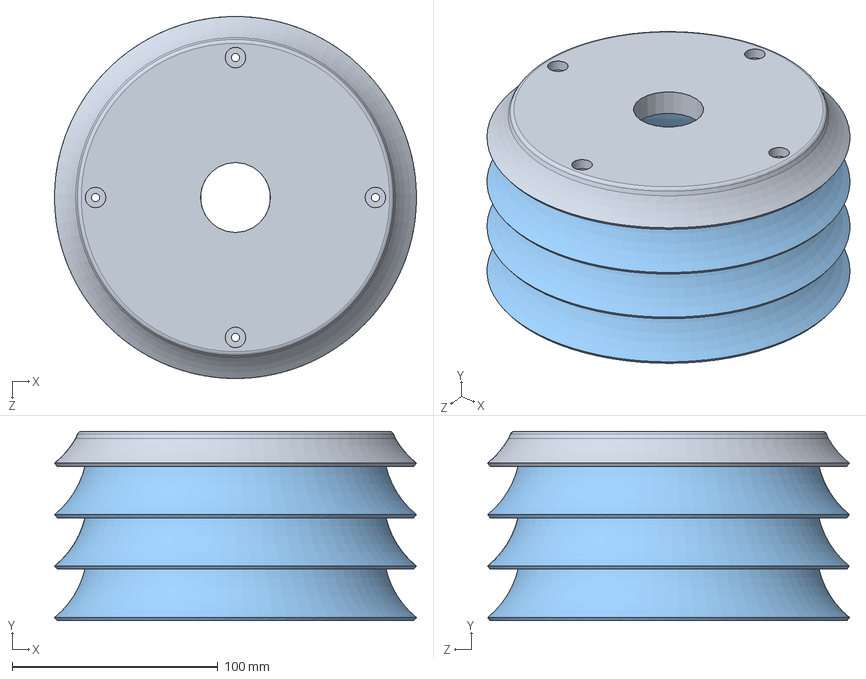
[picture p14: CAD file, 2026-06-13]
C_Prototipos/OmniSens/Dispositivos/Modelos 3D/chasis_2_0/sensores/Caja_sensores.SLDASM
175.9 x 92.0 x 175.9 mm
techo_sensores
techo_sens
ext_aleta x 3

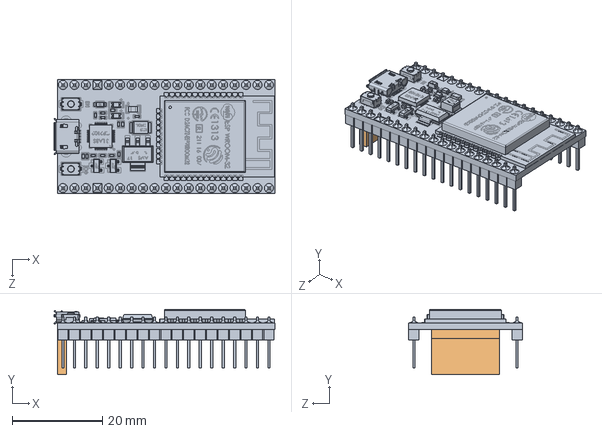
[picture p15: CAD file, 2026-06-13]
C_Prototipos/OmniSens/Dispositivos/Modelos 3D/chasis_2_0/sensores/cont_con_soporte.SLDASM
49.0 x 14.5 x 25.4 mm
ESP32_Wroom_32S
soporte_controlador

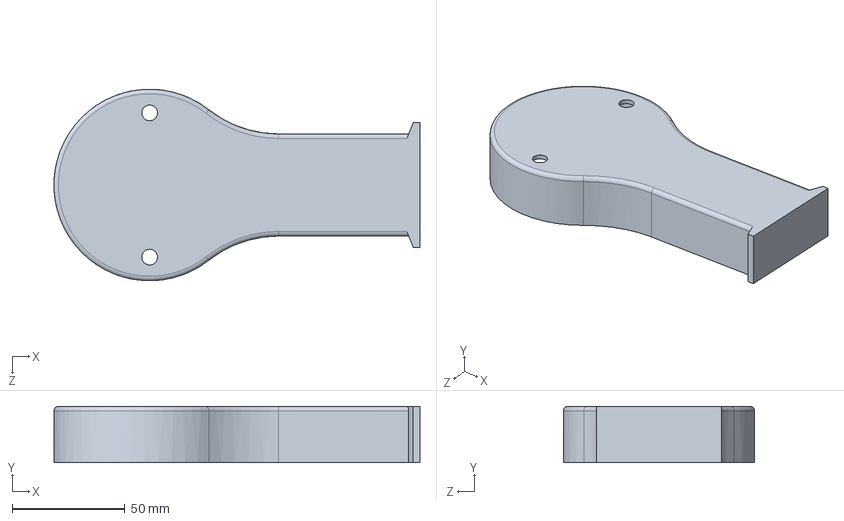
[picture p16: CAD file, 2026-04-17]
C_Prototipos/OmniSens/Dispositivos/Modelos 3D/carcasa_sup_base.SLDPRT
162.4 x 25.0 x 84.9 mm

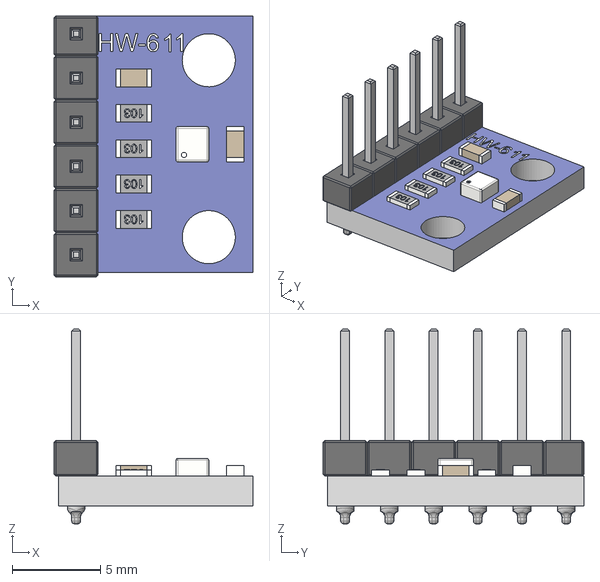
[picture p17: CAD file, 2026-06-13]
C_Prototipos/OmniSens/Dispositivos/Modelos 3D/chasis_2_0/HW-611.step
11.2 x 14.8 x 11.0 mm

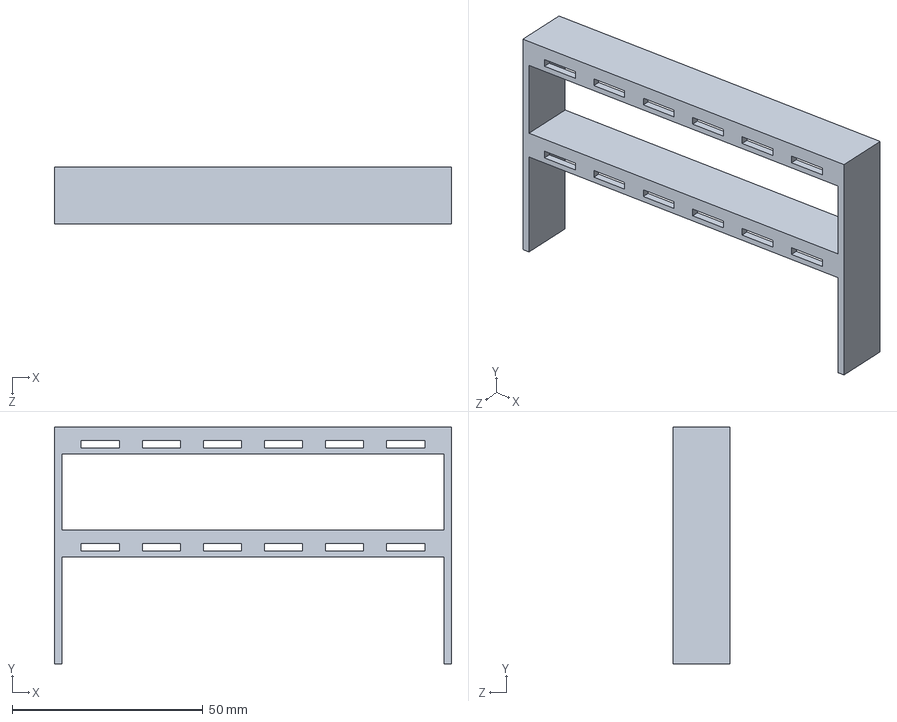
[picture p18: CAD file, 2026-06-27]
C_Prototipos/OmniSens/Dispositivos/Modelos 3D/chasis_2_0/sensores/piso_2_3.SLDPRT
104.0 x 62.0 x 15.0 mm

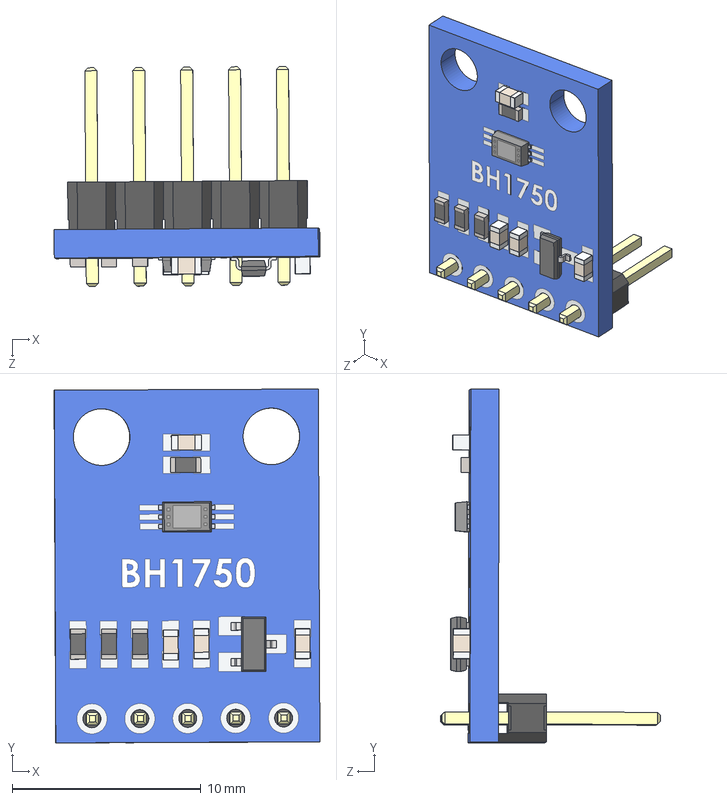
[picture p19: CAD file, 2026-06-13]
C_Prototipos/OmniSens/Dispositivos/Modelos 3D/chasis_2_0/BH1750_with_connector.STEP
14.1 x 18.8 x 11.7 mm
r_0603 x 4
cap_0603 x 4
BH1750_board
BH1750
PLS-5
SOT-23-3

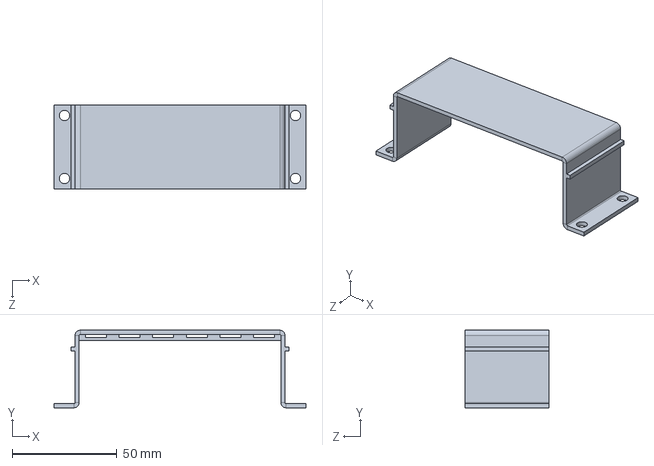
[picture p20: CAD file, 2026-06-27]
C_Prototipos/OmniSens/Dispositivos/Modelos 3D/chasis_2_0/sensores/piso_1.SLDPRT
120.0 x 37.0 x 40.0 mm

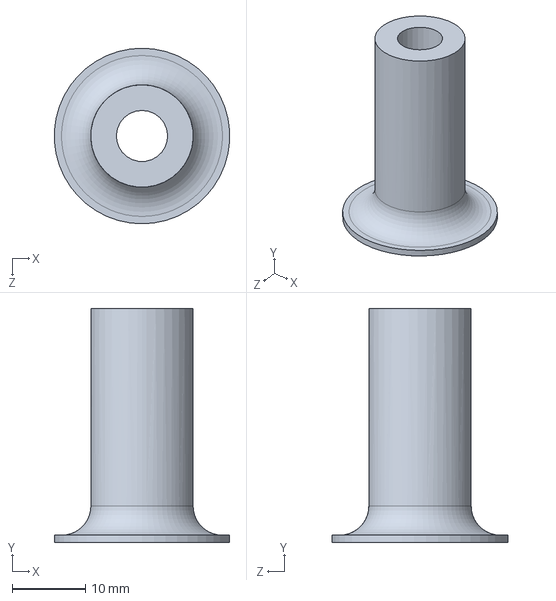
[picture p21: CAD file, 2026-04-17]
C_Prototipos/OmniSens/Dispositivos/Modelos 3D/separador_base.SLDPRT
23.9 x 32.0 x 24.0 mm

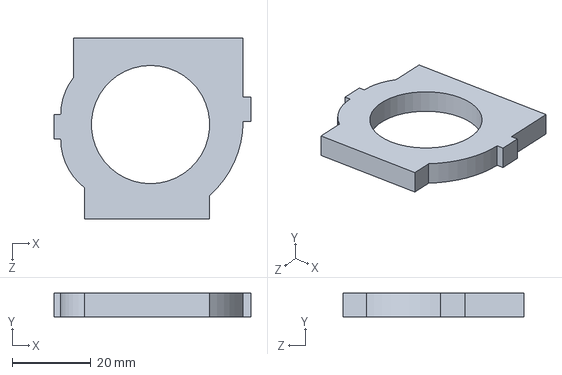
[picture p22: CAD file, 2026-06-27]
C_Prototipos/OmniSens/Dispositivos/Modelos 3D/chasis_2_0/sensores/forzador.SLDPRT
50.0 x 6.00 x 46.0 mm

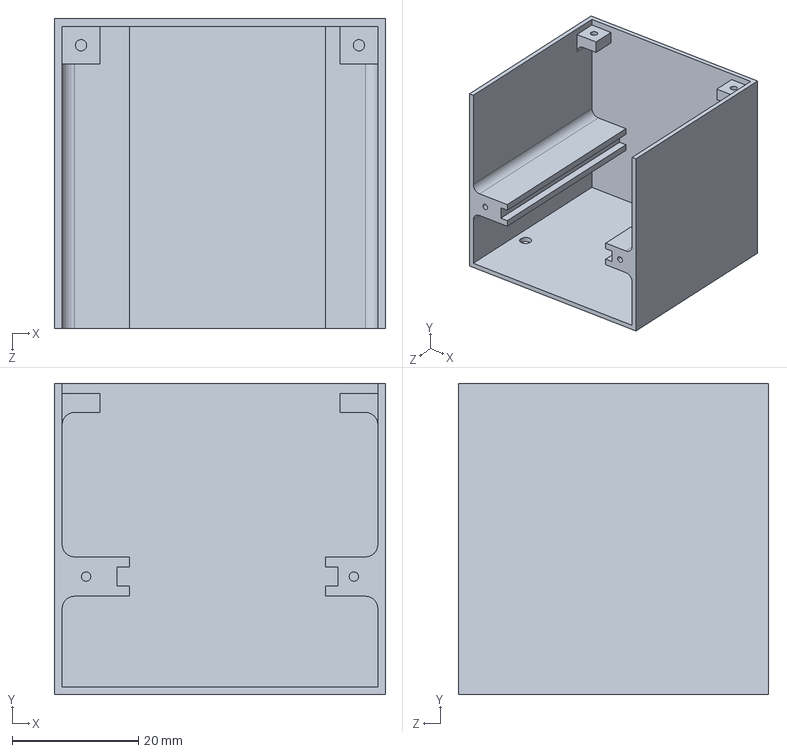
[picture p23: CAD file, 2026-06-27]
C_Prototipos/OmniSens/Dispositivos/Modelos 3D/chasis_2_0/sensores/chimenea_dust.SLDPRT
52.4 x 49.3 x 49.0 mm

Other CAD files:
C_Prototipos/OmniSens/Dispositivos/Modelos 3D/tapa_sup_antena.SLDPRT
C_Prototipos/OmniSens/Dispositivos/Modelos 3D/carcasa_modulo_baliza.SLDPRT
C_Prototipos/OmniSens/Dispositivos/Modelos 3D/tiraLedWS2812.SLDPRT
C_Prototipos/OmniSens/Dispositivos/Modelos 3D/chasis_2_0/sensores/tapa_dust_chim.SLDPRT
C_Prototipos/OmniSens/Dispositivos/Modelos 3D/Tapa_superior_con_ventana.3mf
C_Prototipos/OmniSens/Dispositivos/Modelos 3D/Tapa_superior_con_ventana.STL
C_Prototipos/OmniSens/Dispositivos/Modelos 3D/Tapa_superior_con_ventana.sldprt
C_Prototipos/OmniSens/Dispositivos/Modelos 3D/base_baliza_LDR_LoRa.SLDPRT
C_Prototipos/OmniSens/Dispositivos/Modelos 3D/carcasa_sup_base.3mf
C_Prototipos/OmniSens/Dispositivos/Modelos 3D/carcasa_sup_base.STL
C_Prototipos/OmniSens/Dispositivos/Modelos 3D/chasis_2_0/sensores/100mill Male Pin Header_5P_R.SLDPRT
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

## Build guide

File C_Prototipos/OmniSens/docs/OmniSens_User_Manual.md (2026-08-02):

# 📖 Manual de Usuario: Plataforma Industrial OmniSens IoT

Bienvenido al manual integral de **OmniSens**. Esta guía está diseñada para brindar a los operadores de planta, administradores y personal de mantenimiento todas las herramientas necesarias para la instalación, configuración y explotación analítica de la red de nodos ambientales.

---

## 🏭 1. El Propósito: Eliminando la "Ceguera Operativa"

En entornos industriales, la falta de datos centralizados en tiempo real genera "ceguera operativa". **OmniSens** elimina este problema al unificar la telemetría de múltiples áreas de la planta en una plataforma **multitenant** (multiusuario). Esto significa que su empresa tendrá un entorno seguro y aislado donde sus nodos, reglas y datos le pertenecen exclusivamente, permitiéndole:
1. **Detectar anomalías** en gases, calidad del aire y confort térmico al instante.
2. **Prevenir paradas** automatizando respuestas (ej. encender extractores).
3. **Analizar tendencias** mediante gráficos históricos exportables.

---

## 🔌 2. Conexión Física y la Interfaz LED (Hardware GUI)

El nodo OmniSens (basado en el controlador ESP32) no posee una pantalla LCD para ahorrar energía y costos, pero se comunica con usted a través de un sistema de LEDs intuitivo.

### Indicadores Luminosos
Al enchufar el equipo (Fuente 5V DC o batería):
* 🔴 **LED Rojo (Power):** Se encenderá de forma fija e ininterrumpida. Indica que la placa base está recibiendo energía eléctrica.
* 🔵 **LED Azul (Conectado al GPIO 2 - GUI del Sistema):** Este LED es su medio de comunicación con el sistema operativo interno. Preste atención a su comportamiento:
  * **Parpadeo rápido inmediato al encender:** Durante los primeros **5 segundos**, el equipo le está dando una ventana de tiempo para entrar al modo de configuración (Ver Paso 3).
  * **Parpadeo lento (Buscando Wi-Fi):** El equipo está intentando conectarse a la red inalámbrica y al servidor MQTT.
  * **Encendido Fijo (Portal Cautivo activo):** El nodo generó su propia red Wi-Fi para que usted lo configure.
  * **Apagado (Operación Normal):** Una vez conectado al servidor, el LED azul se apaga para ahorrar energía y no generar contaminación lumínica.

---

## ⚙️ 3. Configuración del Nodo: Portal Cautivo y Sensores

Si el nodo es nuevo, cambió la red Wi-Fi, o desea reconfigurar qué sensores están activos, debe acceder al Portal Cautivo.

**¿Cómo acceder al Portal Cautivo?**
1. Desenchufe y vuelva a enchufar el nodo.
2. Apenas se encienda, verá el **LED Azul parpadeando rápidamente**. ¡Tiene 5 segundos!
3. **Mantenga presionado el botón "BOOT"** (GPIO 0) en la placa durante ese parpadeo.
4. El LED Azul quedará **encendido fijo**. El nodo acaba de crear una red Wi-Fi local de emergencia.

**Configurando el equipo:**
1. Desde su teléfono o PC, conéctese a la red Wi-Fi llamada **`Omnisens-Setup`**.
2. Automáticamente se abrirá una pantalla de configuración (si no ocurre, ingrese a `http://192.168.4.1` en su navegador).
3. Vaya a **"Configure WiFi"**. Aquí encontrará:
   * **Credenciales de Red:** Seleccione el Wi-Fi de la planta y ponga la contraseña.
   * **Gestión de Sensores:** Verá opciones para activar o desactivar sensores específicos (ej. MQ-135, BMP280, Polvo PM10, LDR, etc.). Apague los que no estén físicamente conectados para evitar lecturas erróneas.
   * **Dirección MAC:** Anote esta dirección (Ej: `EC:64:C9:85:0D:9C`); la necesitará luego para registrar el equipo en la nube.
4. Presione **"Save"**. El nodo se reiniciará y se enlazará a la nube.

---

## 🔐 4. Registro y Acceso a la Plataforma (Multitenant)

Como la plataforma es **Multitenant**, sus datos están asilados del resto de las empresas. 

1. Ingrese a la plataforma (Ej: `https://omnisens-iot.ddns.net`).
2. Si es usuario nuevo, haga clic en **Registrarse** y cree su cuenta corporativa.
3. Inicie sesión. Al entrar por primera vez, su entorno estará vacío porque el sistema aún no sabe cuáles nodos le pertenecen.

---

## 🖥️ 5. Vistas y Operación del Panel de Control

La plataforma ofrece múltiples vistas, cada una diseñada para un propósito específico:

### A. Gestor de Dispositivos (Device Manager)
* **Alta de Nodos:** Haga clic en "Agregar Dispositivo". Ingrese la **Dirección MAC** que anotó en el paso 3 y póngale un nombre (Ej: `Horno_Piso1`). A partir de este momento, ese nodo es exclusivamente suyo.
* **Consola RAW (Crudos):** Al hacer clic en un dispositivo registrado, podrá abrir la Consola RAW. Esta herramienta es vital para diagnóstico, ya que le muestra en tiempo real y sin procesar (formato JSON) cada paquete de datos exactamente como llega desde el sensor.

### B. Dashboard en Tiempo Real (Panel Principal)
Su centro de comandos operativo para el "aquí y ahora":
* Visualice Widgets tipo velocímetro para calidad de aire, temperatura y humedad.
* **Comando Manual de Actuadores:** Contiene botones de "Switch" para encender o apagar relés remotamente (extractores, sirenas) y controles deslizantes (Sliders) para la velocidad de motores por PWM.

### C. Analítica de Datos (Analytics)
Donde la magia de los datos ocurre para reportes y auditorías:
* **Gráficos Históricos:** Visualice cómo se comportó la calidad del aire el fin de semana. Puede hacer **Zoom in/out** arrastrando el cursor sobre un área específica del gráfico.
* **Alarmas Retroactivas:** Visualice marcadores en los gráficos donde se dispararon alertas críticas.
* **Exportación Profesional:** Con un solo clic, descargue el rango de fechas seleccionado en formato **CSV** (para Excel/PowerBI) o en un reporte **PDF** listo para enviar a gerencia.

### D. Motor de Reglas (Rules Engine)
Automatice la planta sin intervención humana. Seleccione un nodo, elija un parámetro (Ej: Temperatura), ponga un umbral (`> 35°C`) y defina la acción (`Activar Relé 1`). Las reglas se descargan al hardware, por lo que el nodo actuará incluso si pierde internet temporalmente.

---

## 🔔 6. Configuración de Alertas y Notificaciones Push

Usted no tiene que estar mirando la pantalla todo el día; el sistema le avisará:

* **Notificaciones Push Web:** En la barra superior, active la "Campanita" y permita notificaciones en su navegador. Si una regla de alarma se dispara, aparecerá un recuadro en la esquina de su pantalla alertándolo instantáneamente (incluso si tiene la plataforma en otra pestaña).
* **Alertas por Telegram (Telemetría de Salud):** OmniSens se integra con Telegram para enviar un reporte (en formato código/texto) cada 1 hora a los canales de la empresa. Este reporte resume si los equipos tienen buen nivel de señal Wi-Fi, la carga de la batería y si están operando con normalidad.

---

## ❓ 7. Guía Rápida de Diagnóstico Visual (FAQ)

Si sospecha de un problema, mire la **Interfaz LED (Azul - GPIO 2)** del equipo:

| Comportamiento LED Azul | Diagnóstico y Estado | Solución |
| :--- | :--- | :--- |
| **Parpadeo Lento / Intermitente** | Intentando conectar al Wi-Fi o Servidor MQTT. | Espere unos segundos. Si no se detiene, verifique que el Wi-Fi de la planta tenga internet. |
| **Encendido Fijo (sin parpadear)** | El nodo levantó su Portal Cautivo. | Conéctese a la red "Omnisens-Setup" con su celular para configurarlo. |
| **Apagado** (con LED Rojo encendido) | Funcionamiento Óptimo. | Todo en orden. Revise el Dashboard en la PC. |
| **No enciende ni el LED Rojo** | Falta de energía crítica. | Revise la fuente de alimentación, el cable USB o el estado de las baterías. |

---

¡Disfrute de una operación industrial inteligente, trazable y automatizada con **OmniSens**! 🏭🚀

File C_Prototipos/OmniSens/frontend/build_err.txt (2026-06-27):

[36mvite v8.0.10 [32mbuilding client environment for production...[36m[39m
[2K
transforming...✓ 99 modules transformed.
node.exe : [31m✗[39m Build failed in 2.17s
At line:1 char:1
+ & "C:\nvm4w\nodejs/node.exe" "C:\Users\Fernando\AppData\Roaming\npm/n ...
+ ~~~~~~~~~~~~~~~~~~~~~~~~~~~~~~~~~~~~~~~~~~~~~~~~~~~~~~~~~~~~~~~~~~~~~
    + CategoryInfo          : NotSpecified: ([31m✗[39m Build failed in 2.17s:String) [], RemoteException
    + FullyQualifiedErrorId : NativeCommandError
 
[31merror during build:
[31mBuild failed with 4 errors:

[plugin vite:css] C:/Users/Fernando/Desktop/Desktop/tecnicaturas/telecomunicaciones/AA_New_folder/Estrategia-y-Gesti-n-
de-Proyectos-para-Soluciones-IoT-/C_Prototipos/OmniSens/frontend/src/views/RulesEngineView.vue?vue&type=style&index=0&s
coped=cae458df&lang.css
Failed to load PostCSS config: Failed to load PostCSS config (searchPath: C:/Users/Fernando/Desktop/Desktop/tecnicatura
s/telecomunicaciones/AA_New_folder/Estrategia-y-Gesti-n-de-Proyectos-para-Soluciones-IoT-/C_Prototipos/OmniSens/fronten
d): [Error] Loading PostCSS Plugin failed: Cannot find module '../lib/statuses'
Require stack:
- C:\Users\Fernando\Desktop\Desktop\tecnicaturas\telecomunicaciones\AA_New_folder\Estrategia-y-Gesti-n-de-Proyectos-par
a-Soluciones-IoT-\C_Prototipos\OmniSens\frontend\node_modules\caniuse-lite\dist\unpacker\feature.js
- C:\Users\Fernando\Desktop\Desktop\tecnicaturas\telecomunicaciones\AA_New_folder\Estrategia-y-Gesti-n-de-Proyectos-par
a-Soluciones-IoT-\C_Prototipos\OmniSens\frontend\node_modules\browserslist\node.js
- C:\Users\Fernando\Desktop\Desktop\tecnicaturas\telecomunicaciones\AA_New_folder\Estrategia-y-Gesti-n-de-Proyectos-par
a-Soluciones-IoT-\C_Prototipos\OmniSens\frontend\node_modules\browserslist\index.js
- C:\Users\Fernando\Desktop\Desktop\tecnicaturas\telecomunicaciones\AA_New_folder\Estrategia-y-Gesti-n-de-Proyectos-par
a-Soluciones-IoT-\C_Prototipos\OmniSens\frontend\node_modules\autoprefixer\lib\autoprefixer.js

(@C:\Users\Fernando\Desktop\Desktop\tecnicaturas\telecomunicaciones\AA_New_folder\Estrategia-y-Gesti-n-de-Proyectos-par
a-Soluciones-IoT-\C_Prototipos\OmniSens\frontend\postcss.config.js)
Error: Loading PostCSS Plugin failed: Cannot find module '../lib/statuses'
Require stack:
- C:\Users\Fernando\Desktop\Desktop\tecnicaturas\telecomunicaciones\AA_New_folder\Estrategia-y-Gesti-n-de-Proyectos-par
a-Soluciones-IoT-\C_Prototipos\OmniSens\frontend\node_modules\caniuse-lite\dist\unpacker\feature.js
- C:\Users\Fernando\Desktop\Desktop\tecnicaturas\telecomunicaciones\AA_New_folder\Estrategia-y-Gesti-n-de-Proyectos-par
a-Soluciones-IoT-\C_Prototipos\OmniSens\frontend\node_modules\browserslist\node.js
- C:\Users\Fernando\Desktop\Desktop\tecnicaturas\telecomunicaciones\AA_New_folder\Estrategia-y-Gesti-n-de-Proyectos-par
a-Soluciones-IoT-\C_Prototipos\OmniSens\frontend\node_modules\browserslist\index.js
- C:\Users\Fernando\Desktop\Desktop\tecnicaturas\telecomunicaciones\AA_New_folder\Estrategia-y-Gesti-n-de-Proyectos-par
a-Soluciones-IoT-\C_Prototipos\OmniSens\frontend\node_modules\autoprefixer\lib\autoprefixer.js

(@C:\Users\Fernando\Desktop\Desktop\tecnicaturas\telecomunicaciones\AA_New_folder\Estrategia-y-Gesti-n-de-Proyectos-par
a-Soluciones-IoT-\C_Prototipos\OmniSens\frontend\postcss.config.js)
    at load (file:///C:/Users/Fernando/Desktop/Desktop/tecnicaturas/telecomunicaciones/AA_New_folder/Estrategia-y-Gesti
-n-de-Proyectos-para-Soluciones-IoT-/C_Prototipos/OmniSens/frontend/node_modules/vite/dist/node/chunks/node.js:19651:10
)
    at async Promise.all (index 1)
    at async plugins (file:///C:/Users/Fernando/Desktop/Desktop/tecnicaturas/telecomunicaciones/AA_New_folder/Estrategi
a-y-Gesti-n-de-Proyectos-para-Soluciones-IoT-/C_Prototipos/OmniSens/frontend/node_modules/vite/dist/node/chunks/node.js
:19673:11)
    at async processResult (file:///C:/Users/Fernando/Desktop/Desktop/tecnicaturas/telecomunicaciones/AA_New_folder/Est
rategia-y-Gesti-n-de-Proyectos-para-Soluciones-IoT-/C_Prototipos/OmniSens/frontend/node_modules/vite/dist/node/chunks/n
ode.js:19711:13)
[plugin vite:css] C:/Users/Fernando/Desktop/Desktop/tecnicaturas/telecomunicaciones/AA_New_folder/Estrategia-y-Gesti-n-
de-Proyectos-para-Soluciones-IoT-/C_Prototipos/OmniSens/frontend/src/views/RulesEngineView.vue?vue&type=style&index=0&s
coped=cae458df&lang.css
Failed to load PostCSS config: Failed to load PostCSS config (searchPath: C:/Users/Fernando/Desktop/Desktop/tecnicatura
s/telecomunicaciones/AA_New_folder/Estrategia-y-Gesti-n-de-Proyectos-para-Soluciones-IoT-/C_Prototipos/OmniSens/fronten
d): [Error] Loading PostCSS Plugin failed: Cannot find module '../lib/statuses'
Require stack:
- C:\Users\Fernando\Desktop\Desktop\tecnicaturas\telecomunicaciones\AA_New_folder\Estrategia-y-Gesti-n-de-Proyectos-par
a-Soluciones-IoT-\C_Prototipos\OmniSens\frontend\node_modules\caniuse-lite\dist\unpacker\feature.js
- C:\Users\Fernando\Desktop\Desktop\tecnicaturas\telecomunicaciones\AA_New_folder\Estrategia-y-Gesti-n-de-Proyectos-par
a-Soluciones-IoT-\C_Prototipos\OmniSens\frontend\node_modules\browserslist\node.js
- C:\Users\Fernando\Desktop\Desktop\tecnicaturas\telecomunicaciones\AA_New_folder\Estrategia-y-Gesti-n-de-Proyectos-par
a-Soluciones-IoT-\C_Prototipos\OmniSens\frontend\node_modules\browserslist\index.js
- C:\Users\Fernando\Desktop\Desktop\tecnicaturas\telecomunicaciones\AA_New_folder\Estrategia-y-Gesti-n-de-Proyectos-par
a-Soluciones-IoT-\C_Prototipos\OmniSens\frontend\node_modules\autoprefixer\lib\autoprefixer.js

(@C:\Users\Fernando\Desktop\Desktop\tecnicaturas\telecomunicaciones\AA_New_folder\Estrategia-y-Gesti-n-de-Proyectos-par
a-Soluciones-IoT-\C_Prototipos\OmniSens\frontend\postcss.config.js)
Error: Loading PostCSS Plugin failed: Cannot find module '../lib/statuses'
Require stack:
- C:\Users\Fernando\Desktop\Desktop\tecnicaturas\telecomunicaciones\AA_New_folder\Estrategia-y-Gesti-n-de-Proyectos-par
a-Soluciones-IoT-\C_Prototipos\OmniSens\frontend\node_modules\caniuse-lite\dist\unpacker\feature.js
- C:\Users\Fernando\Desktop\Desktop\tecnicaturas\telecomunicaciones\AA_New_folder\Estrategia-y-Gesti-n-de-Proyectos-par
a-Soluciones-IoT-\C_Prototipos\OmniSens\frontend\node_modules\browserslist\node.js
- C:\Users\Fernando\Desktop\Desktop\tecnicaturas\telecomunicaciones\AA_New_folder\Estrategia-y-Gesti-n-de-Proyectos-par
a-Soluciones-IoT-\C_Prototipos\OmniSens\frontend\node_modules\browserslist\index.js
- C:\Users\Fernando\Desktop\Desktop\tecnicaturas\telecomunicaciones\AA_New_folder\Estrategia-y-Gesti-n-de-Proyectos-par
a-Soluciones-IoT-\C_Prototipos\OmniSens\frontend\node_modules\autoprefixer\lib\autoprefixer.js

(@C:\Users\Fernando\Desktop\Desktop\tecnicaturas\telecomunicaciones\AA_New_folder\Estrategia-y-Gesti-n-de-Proyectos-par
a-Soluciones-IoT-\C_Prototipos\OmniSens\frontend\postcss.config.js)
    at load (file:///C:/Users/Fernando/Desktop/Desktop/tecnicaturas/telecomunicaciones/AA_New_folder/Estrategia-y-Gesti
-n-de-Proyectos-para-Soluciones-IoT-/C_Prototipos/OmniSens/frontend/node_modules/vite/dist/node/chunks/node.js:19651:10
)
    at async Promise.all (index 1)
    at async plugins (file:///C:/Users/Fernando/Desktop/Desktop/tecnicaturas/telecomunicaciones/AA_New_folder/Estrategi
a-y-Gesti-n-de-Proyectos-para-Soluciones-IoT-/C_Prototipos/OmniSens/frontend/node_modules/vite/dist/node/chunks/node.js
:19673:11)
    at async processResult (file:///C:/Users/Fernando/Desktop/Desktop/tecnicaturas/telecomunicaciones/AA_New_folder/Est
rategia-y-Gesti-n-de-Proyectos-para-Soluciones-IoT-/C_Prototipos/OmniSens/frontend/node_modules/vite/dist/node/chunks/n
ode.js:19711:13)
[plugin vite:css] C:/Users/Fernando/Desktop/Desktop/tecnicaturas/telecomunicaciones/AA_New_folder/Estrategia-y-Gesti-n-
de-Proyectos-para-Soluciones-IoT-/C_Prototipos/OmniSens/frontend/src/views/RulesEngineView.vue?vue&type=style&index=0&s
coped=cae458df&lang.css
Failed to load PostCSS config: Failed to load PostCSS config (searchPath: C:/Users/Fernando/Desktop/Desktop/tecnicatura
s/telecomunicaciones/AA_New_folder/Estrategia-y-Gesti-n-de-Proyectos-para-Soluciones-IoT-/C_Prototipos/OmniSens/fronten
d): [Error] Loading PostCSS Plugin failed: Cannot find module '../lib/statuses'
Require stack:
- C:\Users\Fernando\Desktop\Desktop\tecnicaturas\telecomunicaciones\AA_New_folder\Estrategia-y-Gesti-n-de-Proyectos-par
a-Soluciones-IoT-\C_Prototipos\OmniSens\frontend\node_modules\caniuse-lite\dist\unpacker\feature.js
- C:\Users\Fernando\Desktop\Desktop\tecnicaturas\telecomunicaciones\AA_New_folder\Estrategia-y-Gesti-n-de-Proyectos-par
a-Soluciones-IoT-\C_Prototipos\OmniSens\frontend\node_modules\browserslist\node.js
- C:\Users\Fernando\Desktop\Desktop\tecnicaturas\telecomunicaciones\AA_New_folder\Estrategia-y-Gesti-n-de-Proyectos-par
a-Soluciones-IoT-\C_Prototipos\OmniSens\frontend\node_modules\browserslist\index.js
- C:\Users\Fernando\Desktop\Desktop\tecnicaturas\telecomunicaciones\AA_New_folder\Estrategia-y-Gesti-n-de-Proyectos-par
a-Soluciones-IoT-\C_Prototipos\OmniSens\frontend\node_modules\autoprefixer\lib\autoprefixer.js

(@C:\Users\Fernando\Desktop\Desktop\tecnicaturas\telecomunicaciones\AA_New_folder\Estrategia-y-Gesti-n-de-Proyectos-par
a-Soluciones-IoT-\C_Prototipos\OmniSens\frontend\postcss.config.js)
Error: Loading PostCSS Plugin failed: Cannot find module '../lib/statuses'
Require stack:
- C:\Users\Fernando\Desktop\Desktop\tecnicaturas\telecomunicaciones\AA_New_folder\Estrategia-y-Gesti-n-de-Proyectos-par
a-Soluciones-IoT-\C_Prototipos\OmniSens\frontend\node_modules\caniuse-lite\dist\unpacker\feature.js
- C:\Users\Fernando\Desktop\Desktop\tecnicaturas\telecomunicaciones\AA_New_folder\Estrategia-y-Gesti-n-de-Proyectos-par
a-Soluciones-IoT-\C_Prototipos\OmniSens\frontend\node_modules\browserslist\node.js
- C:\Users\Fernando\Desktop\Desktop\tecnicaturas\telecomunicaciones\AA_New_folder\Estrategia-y-Gesti-n-de-Proyectos-par
a-Soluciones-IoT-\C_Prototipos\OmniSens\frontend\node_modules\browserslist\index.js
- C:\Users\Fernando\Desktop\Desktop\tecnicaturas\telecomunicaciones\AA_New_folder\Estrategia-y-Gesti-n-de-Proyectos-par
a-Soluciones-IoT-\C_Prototipos\OmniSens\frontend\node_modules\autoprefixer\lib\autoprefixer.js

(@C:\Users\Fernando\Desktop\Desktop\tecnicaturas\telecomunicaciones\AA_New_folder\Estrategia-y-Gesti-n-de-Proyectos-par
a-Soluciones-IoT-\C_Prototipos\OmniSens\frontend\postcss.config.js)
    at load (file:///C:/Users/Fernando/Desktop/Desktop/tecnicaturas/telecomunicaciones/AA_New_folder/Estrategia-y-Gesti
-n-de-Proyectos-para-Soluciones-IoT-/C_Prototipos/OmniSens/frontend/node_modules/vite/dist/node/chunks/node.js:19651:10
)
    at async Promise.all (index 1)
    at async plugins (file:///C:/Users/Fernando/Desktop/Desktop/tecnicaturas/telecomunicaciones/AA_New_folder/Estrategi
a-y-Gesti-n-de-Proyectos-para-Soluciones-IoT-/C_Prototipos/OmniSens/frontend/node_modules/vite/dist/node/chunks/node.js
:19673:11)
    at async processResult (file:///C:/Users/Fernando/Desktop/Desktop/tecnicaturas/telecomunicaciones/AA_New_folder/Est
rategia-y-Gesti-n-de-Proyectos-para-Soluciones-IoT-/C_Prototipos/OmniSens/frontend/node_modules/vite/dist/node/chunks/n
ode.js:19711:13)
[plugin vite:css] C:/Users/Fernando/Desktop/Desktop/tecnicaturas/telecomunicaciones/AA_New_folder/Estrategia-y-Gesti-n-
de-Proyectos-para-Soluciones-IoT-/C_Prototipos/OmniSens/frontend/src/views/RulesEngineView.vue?vue&type=style&index=0&s
coped=cae458df&lang.css
Failed to load PostCSS config: Failed to load PostCSS config (searchPath: C:/Users/Fernando/Desktop/Desktop/tecnicatura
s/telecomunicaciones/AA_New_folder/Estrategia-y-Gesti-n-de-Proyectos-para-Soluciones-IoT-/C_Prototipos/OmniSens/fronten
d): [Error] Loading PostCSS Plugin failed: Cannot find module '../lib/statuses'
Require stack:
- C:\Users\Fernando\Desktop\Desktop\tecnicaturas\telecomunicaciones\AA_New_folder\Estrategia-y-Gesti-n-de-Proyectos-par
a-Soluciones-IoT-\C_Prototipos\OmniSens\frontend\node_modules\caniuse-lite\dist\unpacker\feature.js
- C:\Users\Fernando\Desktop\Desktop\tecnicaturas\telecomunicaciones\AA_New_folder\Estrategia-y-Gesti-n-de-Proyectos-par
a-Soluciones-IoT-\C_Prototipos\OmniSens\frontend\node_modules\browserslist\node.js
- C:\Users\Fernando\Desktop\Desktop\tecnicaturas\telecomunicaciones\AA_New_folder\Estrategia-y-Gesti-n-de-Proyectos-par
a-Soluciones-IoT-\C_Prototipos\OmniSens\frontend\node_modules\browserslist\index.js
- C:\Users\Fernando\Desktop\Desktop\tecnicaturas\telecomunicaciones\AA_New_folder\Estrategia-y-Gesti-n-de-Proyectos-par
a-Soluciones-IoT-\C_Prototipos\OmniSens\frontend\node_modules\autoprefixer\lib\autoprefixer.js

(@C:\Users\Fernando\Desktop\Desktop\tecnicaturas\telecomunicaciones\AA_New_folder\Estrategia-y-Gesti-n-de-Proyectos-par
a-Soluciones-IoT-\C_Prototipos\OmniSens\frontend\postcss.config.js)
Error: Loading PostCSS Plugin failed: Cannot find module '../lib/statuses'
Require stack:
- C:\Users\Fernando\Desktop\Desktop\tecnicaturas\telecomunicaciones\AA_New_folder\Estrategia-y-Gesti-n-de-Proyectos-par
a-Soluciones-IoT-\C_Prototipos\OmniSens\frontend\node_modules\caniuse-lite\dist\unpacker\feature.js
- C:\Users\Fernando\Desktop\Desktop\tecnicaturas\telecomunicaciones\AA_New_folder\Estrategia-y-Gesti-n-de-Proyectos-par
a-Soluciones-IoT-\C_Prototipos\OmniSens\frontend\node_modules\browserslist\node.js
- C:\Users\Fernando\Desktop\Desktop\tecnicaturas\telecomunicaciones\AA_New_folder\Estrategia-y-Gesti-n-de-Proyectos-par
a-Soluciones-IoT-\C_Prototipos\OmniSens\frontend\node_modules\browserslist\index.js
- C:\Users\Fernando\Desktop\Desktop\tecnicaturas\telecomunicaciones\AA_New_folder\Estrategia-y-Gesti-n-de-Proyectos-par
a-Soluciones-IoT-\C_Prototipos\OmniSens\frontend\node_modules\autoprefixer\lib\autoprefixer.js

(@C:\Users\Fernando\Desktop\Desktop\tecnicaturas\telecomunicaciones\AA_New_folder\Estrategia-y-Gesti-n-de-Proyectos-par
a-Soluciones-IoT-\C_Prototipos\OmniSens\frontend\postcss.config.js)
    at load (file:///C:/Users/Fernando/Desktop/Desktop/tecnicaturas/telecomunicaciones/AA_New_folder/Estrategia-y-Gesti
-n-de-Proyectos-para-Soluciones-IoT-/C_Prototipos/OmniSens/frontend/node_modules/vite/dist/node/chunks/node.js:19651:10
)
    at async Promise.all (index 1)
    at async plugins (file:///C:/Users/Fernando/Desktop/Desktop/tecnicaturas/telecomunicaciones/AA_New_folder/Estrategi
a-y-Gesti-n-de-Proyectos-para-Soluciones-IoT-/C_Prototipos/OmniSens/frontend/node_modules/vite/dist/node/chunks/node.js
:19673:11)
    at async processResult (file:///C:/Users/Fernando/Desktop/Desktop/tecnicaturas/telecomunicaciones/AA_New_folder/Est
rategia-y-Gesti-n-de-Proyectos-para-Soluciones-IoT-/C_Prototipos/OmniSens/frontend/node_modules/vite/dist/node/chunks/n
ode.js:19711:13)[31m
    at aggregateBindingErrorsIntoJsError (file:///C:/Users/Fernando/Desktop/Desktop/tecnicaturas/telecomunicaciones/AA_
New_folder/Estrategia-y-Gesti-n-de-Proyectos-para-Soluciones-IoT-/C_Prototipos/OmniSens/frontend/node_modules/rolldown/
dist/shared/error-DL-e8-oE.mjs:48:18)
    at unwrapBindingResult (file:///C:/Users/Fernando/Desktop/Desktop/tecnicaturas/telecomunicaciones/AA_New_folder/Est
rategia-y-Gesti-n-de-Proyectos-para-Soluciones-IoT-/C_Prototipos/OmniSens/frontend/node_modules/rolldown/dist/shared/er
ror-DL-e8-oE.mjs:18:128)
    at #build (file:///C:/Users/Fernando/Desktop/Desktop/tecnicaturas/telecomunicaciones/AA_New_folder/Estrategia-y-Ges
ti-n-de-Proyectos-para-Soluciones-IoT-/C_Prototipos/OmniSens/frontend/node_modules/rolldown/dist/shared/rolldown-build-
DSxL8qiP.mjs:3317:34)
    at async buildEnvironment (file:///C:/Users/Fernando/Desktop/Desktop/tecnicaturas/telecomunicaciones/AA_New_folder/
Estrategia-y-Gesti-n-de-Proyectos-para-Soluciones-IoT-/C_Prototipos/OmniSens/frontend/node_modules/vite/dist/node/chunk
s/node.js:33018:64)
    at async Object.build (file:///C:/Users/Fernando/Desktop/Desktop/tecnicaturas/telecomunicaciones/AA_New_folder/Estr
ategia-y-Gesti-n-de-Proyectos-para-Soluciones-IoT-/C_Prototipos/OmniSens/frontend/node_modules/vite/dist/node/chunks/no
de.js:33440:19)
    at async Object.buildApp (file:///C:/Users/Fernando/Desktop/Desktop/tecnicaturas/telecomunicaciones/AA_New_folder/E
strategia-y-Gesti-n-de-Proyectos-para-Soluciones-IoT-/C_Prototipos/OmniSens/frontend/node_modules/vite/dist/node/chunks
/node.js:33437:153)
    at async CAC.<anonymous> (file:///C:/Users/Fernando/Desktop/Desktop/tecnicaturas/telecomunicaciones/AA_New_folder/E
strategia-y-Gesti-n-de-Proyectos-para-Soluciones-IoT-/C_Prototipos/OmniSens/frontend/node_modules/vite/dist/node/cli.js
:778:3) {
  errors: [Getter/Setter]
}[39m

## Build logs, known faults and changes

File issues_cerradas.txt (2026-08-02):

46	CLOSED	10.4 Documentar estrategia de seguridad del sistema	documentation, seguridad	2026-06-15T03:38:19Z
45	CLOSED	9.4 Evaluar riesgos de seguridad del sistema IoT	documentation, riesgo, seguridad	2026-06-15T07:09:15Z
44	CLOSED	8.4 Validar integridad de datos del sistema	seguridad, datos.	2026-06-15T04:38:37Z
43	CLOSED	7.4 Proteger acceso f├¡sico a nodos Edge	hardware, seguridad	2026-06-15T02:23:04Z
42	CLOSED	6.4 Dise├▒ar sistema de rotaci├│n de credenciales	devops, seguridad	2026-06-15T05:09:21Z
41	CLOSED	5.4 Implementar autenticaci├│n en API del sistema	backend, seguridad	2026-06-16T02:34:03Z
40	CLOSED	4.4 Implementar cifrado en comunicaci├│n MQTT	backend, seguridad	2026-06-16T02:37:34Z
39	CLOSED	3.4 Evaluar seguridad del firmware en ESP32	firmware, seguridad	2026-06-15T02:09:31Z
38	CLOSED	2.4 Configurar an├ílisis de vulnerabilidades del c├│digo	backend, seguridad	2026-06-15T05:25:56Z
37	CLOSED	1.4 Implementar protecci├│n de secretos en el repositorio	devops, seguridad	2026-06-15T05:34:31Z
36	CLOSED	9.3 Redactar modelo de negocio final	documentation	2026-06-15T06:13:21Z
35	CLOSED	8.3 Evaluar riesgos del modelo de negocio	riesgo, gestion	2026-06-15T06:12:14Z
34	CLOSED	7.3 Analizar viabilidad en el mercado argentino	gestion, research	2026-06-15T06:12:00Z
33	CLOSED	6.3 Definir patr├│n de negocio del sistema	gestion	2026-06-15T23:49:15Z
32	CLOSED	5.3 Calcular ARPU estimado del proyecto	documentation, research	2026-06-15T05:59:16Z
31	CLOSED	4.3 Definir estructura de costos (CAPEX y OPEX)	documentation, gestion	2026-06-15T06:30:13Z
30	CLOSED	3.3 Analizar fuentes de ingresos del sistema	gestion	2026-06-15T02:13:45Z
29	CLOSED	2.3 Definir propuesta de valor por segmento	documentation, gestion	2026-06-15T06:12:35Z
28	CLOSED	1.3 Definir segmentos de clientes de OmniSens	gestion, research	2026-06-15T06:14:38Z
27	CLOSED	10.2 Documentar arquitectura t├⌐cnica final	documentation	2026-06-15T07:50:11Z
26	CLOSED	9.2 Validar resiliencia del sistema ante fallas	testing, riesgo	2026-06-15T06:42:22Z
25	CLOSED	8.2 Dise├▒ar flujo de datos completo del sistema	documentation	2026-06-15T08:01:13Z
24	CLOSED	7.2 Configurar entorno Docker (Node-RED, MariaDB, Grafana)	backend, devops	2026-06-16T02:40:23Z
23	CLOSED	6.2 Implementar broker MQTT y comunicaci├│n con servidor	backend	2026-06-16T02:42:26Z
22	CLOSED	5.2 Configurar comunicaci├│n LoRa	hardware, backend	2026-05-05T21:52:35Z
21	CLOSED	4.2 Implementar control de actuadores	hardware, firmware	2026-06-16T02:43:53Z
20	CLOSED	3.2 Desarrollar firmware base en ESP32	firmware	2026-06-16T02:45:22Z
19	CLOSED	2.2 Integrar sensores al sistema (AHT25, BMP280, MQ135, LDR)	hardware, firmware	2026-06-16T02:49:37Z
18	CLOSED	1.2 Definir arquitectura de 3 capas del sistema IoT	documentation	2026-06-15T02:26:51Z
17	CLOSED	7.1 Redactar documentaci├│n final de visi├│n estrat├⌐gica	documentation	2026-06-15T02:04:33Z

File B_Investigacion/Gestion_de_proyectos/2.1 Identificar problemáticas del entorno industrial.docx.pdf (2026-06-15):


### 2.1 Identificar problemáticas del entorno industrial

### 1. Falta de monitoreo en tiempo real

Muchas organizaciones continúan dependiendo de controles periódicos o verificaciones manuales, lo que impide conocer el estado real de las condiciones ambientales en cada momento. Esta falta de visibilidad reduce la capacidad de respuesta ante situaciones críticas.

### 2. Falta de detección temprana de riesgos

La ausencia de monitoreo continuo dificulta la identificación oportuna de anomalías en variables como calidad del aire, temperatura o humedad. Como consecuencia, los incidentes suelen detectarse cuando ya han generado impactos sobre la operación o la seguridad.

### 3. Problemas de trazabilidad y centralización de datos

La información suele encontrarse dispersa en planillas, registros manuales o sistemas aislados, dificultando el acceso al historial de datos, la generación de reportes y el análisis de tendencias para la toma de decisiones.

### 4. Ineficiencia operativa y energética

La falta de información en tiempo real impide optimizar el uso de recursos y detectar condiciones que puedan afectar el rendimiento de equipos e instalaciones, generando mayores costos operativos.

### 5. Dependencia de decisiones humanas

La supervisión basada exclusivamente en la intervención humana aumenta el riesgo de errores, omisiones o demoras en la detección de situaciones críticas. Esto limita la capacidad de prevención y respuesta de las organizaciones.

Resultado esperado
Se identifican como principales problemáticas la falta de monitoreo en tiempo real, la detección tardía de riesgos, la escasa trazabilidad de la información, las ineficiencias operativas y la dependencia de procesos manuales. Estas necesidades justifican la implementación de OmniSens como una solución capaz de centralizar datos, generar alertas tempranas y facilitar la toma de decisiones preventivas en entornos industriales.

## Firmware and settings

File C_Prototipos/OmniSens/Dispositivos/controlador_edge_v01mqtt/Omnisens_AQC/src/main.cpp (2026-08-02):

#include <Arduino.h>
#include <Wire.h>
#include <ArduinoJson.h>
#include <esp_task_wdt.h>

#include "MQ135Sensor.h"
#include "AHT25Sensor.h"
#include "BMP280Sensor.h"
#include "LDRSensor.h"
#include "DustSensor.h"
#include "BH1750Sensor.h"
#include "SalidaPWM.h"
#include "SalidasRele.h"
#include "SensorData.h"
#include "LedIndicator.h"
#include "NetworkManager.h"
#include "SystemLogger.h"
#include "RulesEngine.h"

// Pines de Hardware
#define MQ135_PIN 39
#define PWM_PIN 32
#define RELE_1 33
#define RELE_2 25
#define LDR_PIN 36
#define DUST_AOUT_PIN 34 // Pin analógico para el sensor Sharp
#define DUST_ILED_PIN 4  // Pin digital para el LED del sensor Sharp
#define DUST_FAN_PIN 27  // Salida PWM exclusiva para el forzador de aire del sensor de Polvo
#define LED_PIN 2     // LED integrado en ESP32
#define BOOT_BTN 0    // Botón BOOT del ESP32
#define BATTERY_PIN 35 // Pin analógico divisor de batería

// Credenciales Base
const char* MQTT_BROKER = "omnisens-iot.ddns.net";
const uint16_t MQTT_PORT = 8883;

// Tiempo de Watchdog (15 segundos)
#define WDT_TIMEOUT 15

// Instancias de Hardware
MQ135Sensor mq135(MQ135_PIN);
AHT25Sensor aht25;
BMP280Sensor bmp280;
LDRSensor ldr(LDR_PIN);
DustSensor dust(DUST_AOUT_PIN, DUST_ILED_PIN);
BH1750Sensor bh1750;
SalidaPWM vel_motor(PWM_PIN); // Actuador externo genérico
SalidaPWM dust_fan(DUST_FAN_PIN); // Forzador dedicado para el sensor de polvo
SalidasRele salidas(RELE_1, RELE_2);
LedIndicator led(LED_PIN);

// Instancia de Lógica y Red
SensorData sensorData("AQC_001", &mq135, &bmp280, &aht25, &ldr, &dust, &bh1750, &salidas, &vel_motor, BATTERY_PIN);
NetworkManager network(MQTT_BROKER, MQTT_PORT, &led);
RulesEngine rulesEngine(&salidas, &vel_motor);

// FreeRTOS
SemaphoreHandle_t sensorMutex;
StaticJsonDocument<512> sharedDoc;
volatile bool newDataAvailable = false;

// Variables globales eliminadas, ya no se usan para el botón AP.

// --- Callback de Actuadores ---
void onActuatorCommand(bool r1, bool r2, uint8_t pwm) {
    SystemLogger::info(String("Aplicando Actuadores -> R1:") + String(r1) + " R2:" + String(r2) + " PWM:" + String(pwm));
    salidas.setRele1(r1);
    salidas.setRele2(r2);
    vel_motor.comandoPWM(pwm);
}

// --- Callback de Reglas (MQTT -> Borde) ---
void onRulesConfig(const JsonArray& rulesArray) {
    rulesEngine.saveRulesFromJson(rulesArray);
}

// ---------------------------------------------------------
// TAREA 1: Lectura de Sensores (Baja prioridad)
// ---------------------------------------------------------
void taskSensors(void *pvParameters) {
    esp_task_wdt_add(NULL);

    for (;;) {
        esp_task_wdt_reset();

        if (xSemaphoreTake(sensorMutex, portMAX_DELAY)) {
            // Sincronizar configuracion
            SensorConfig cfg;
            cfg.en_mq135 = network.enMq135();
            cfg.en_bmp280 = network.enBmp280();
            cfg.en_aht25 = network.enAht25();
            cfg.en_ldr = network.enLdr();
            cfg.en_bh1750 = network.enBh1750();
            cfg.en_dust = network.enDust();
            sensorData.setConfig(cfg);

            // Lógica de pre-calentamiento / purgado de aire para el sensor de polvo
            if (cfg.en_dust) {
                dust_fan.comandoPWM(180); // Encender forzador al ~70% de velocidad
                vTaskDelay(pdMS_TO_TICKS(1500)); // Esperar 1.5 segs para renovar el aire en el tubo
            }

            sharedDoc.clear();
            sensorData.populateJson(sharedDoc); // Aquí adentro se lee el sensor de polvo
            
            if (cfg.en_dust) {
                dust_fan.comandoPWM(0); // Apagar el forzador para ahorrar energía/ruido
            }

            // Evaluar reglas localmente contra los datos frescos
            rulesEngine.evaluate(sharedDoc);

            newDataAvailable = true;
            xSemaphoreGive(sensorMutex);
        }
        
        vTaskDelay(pdMS_TO_TICKS(5000)); // Repetir cada 5 segundos
    }
}

// ---------------------------------------------------------
// TAREA 2: Gestión de Red y Publicación MQTT (Alta prioridad)
// ---------------------------------------------------------
void taskNetwork(void *pvParameters) {
    esp_task_wdt_add(NULL);

    // El control del botón BOOT para el portal cautivo se movió a setup()
    // Esta tarea ahora solo se encarga de la conexión de red y telemetría.

    for (;;) {
        esp_task_wdt_reset();
        
        led.update();
        network.loop();

        if (newDataAvailable && network.isConnected()) {
            if (xSemaphoreTake(sensorMutex, pdMS_TO_TICKS(100))) {
                network.publishTelemetry(sharedDoc);
                newDataAvailable = false;
                xSemaphoreGive(sensorMutex);
            }
        }
        
        vTaskDelay(pdMS_TO_TICKS(50));
    }
}

// --- SETUP ---
void setup() {
    Serial.begin(115200);
    delay(1000);

    // Configurar atenuación del ADC globalmente a 0dB (Rango: 0V a 1.1V aprox)
    // Esto asegura mayor linealidad y precisión para los divisores resistivos.
    analogSetAttenuation(ADC_0db);

    // Usar SystemLogger (primero llamamos begin explícito en NetworkManager pero no importa si lo usamos antes si es info default)
    SystemLogger::info("\n[Sistema] Iniciando OmniSens Edge Node...");

    // Inicializar Watchdog global
    esp_task_wdt_init(WDT_TIMEOUT, true);

    // Inicializar Botón, LED y Pin de Batería
    pinMode(BOOT_BTN, INPUT_PULLUP);
    pinMode(BATTERY_PIN, INPUT);
    led.begin();

    // Comprobar si el usuario quiere entrar al portal cautivo
    network.checkCaptivePortalBoot(BOOT_BTN, 5000);

    // Inicializar I2C
    Wire.setPins(21, 22);
    Wire.begin();

    // Inicializar Hardware
    aht25.begin();
    bmp280.begin();
    mq135.begin();
    ldr.begin();
    dust.begin();
    bh1750.begin();
    vel_motor.begin();
    vel_motor.comandoPWM(0);
    dust_fan.begin();
    dust_fan.comandoPWM(0);
    salidas.begin();

    // Inicializar Motor de Reglas
    rulesEngine.begin();

    sensorMutex = xSemaphoreCreateMutex();

    network.setActuatorCallback(onActuatorCommand);
    network.setRulesCallback(onRulesConfig);
    network.begin();

    xTaskCreatePinnedToCore(taskSensors, "TaskSensors", 4096, NULL, 1, NULL, 1);
    xTaskCreatePinnedToCore(taskNetwork, "TaskNetwork", 8192, NULL, 2, NULL, 0);

    SystemLogger::info("Setup completado. RTOS en ejecucion con TWDT.");
}

void loop() {
    vTaskDelete(NULL);
}

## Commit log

2026-04-12 Improve README formatting and content clarity
    Enhance README with formatting and additional details on system architecture and data flow.
2026-04-14 se amplia la estructura de archivos para el desarrollo del proyecto
2026-04-16 se sube parte de modelo de negacios
2026-04-17 carga de stack de proyecto
    [Tapa_superior_con_ventana.3mf, Tapa_superior_con_ventana.STL, Tapa_superior_con_ventana.sldprt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]
2026-04-29 ultimos cambios al repositorio
    [Tapa_superior_con_ventana.3mf, Tapa_superior_con_ventana.STL, Tapa_superior_con_ventana.sldprt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]
2026-05-05 actualizacion masiva de plataforma y firmware
2026-05-05 Update README.md
    guia de modelo de negocio
2026-05-05 Update README.md
    modificación título modelo de negocio
2026-05-05 Update and rename backlog.md to ARCHIVOS DE GESTIÓN.md
    actualizacion de readme
2026-05-06 Se reorganiza el directorio enviando archivos en desuso a una carpeta destinada a tal fin.
2026-05-18 Actualizacion de plataforma y firware
2026-06-13 plataforma desplegable
    [100mill Male Pin Header_5P_R.SLDPRT, 100mill Male Pin Header_5P_R.STEP, 1S 4056 BMS USB C Module 01b.SLDASM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]
2026-06-15 aporte de seguridad del proyecto
2026-06-15 aporte de seguridad del proyecto 1
2026-06-15 actualizacion de informacion de seguridad del proyecto
2026-06-15 se agrega documentacion de seguridad
2026-06-15 actualizacion de documentacion
2026-06-15 actualizaciones de diseño de hardware
    [base_sens.SLDPRT, base_sens.STL, espacio de componentes.SLDPRT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]
2026-06-15 correccion de codigo
2026-06-16 actualizar README de PPII con estructura de documentación técnica
2026-06-16 estructurar README principal de B_Investigacion
2026-06-27 Implementacion del Motor de Reglas y reparacion del Portal Cautivo
    [Dust sensor GP2Y1010AU0F.SLDPRT, assy_dust_chim.SLDASM, chimenea_dust.3mf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]
2026-07-30 feat: Add Telegram Bot integration, device_rules evaluation, and ECharts CSV/PDF export with graphic triggers
2026-08-02 fix: mount frontend dist volume
2026-08-02 feat: use domain name for mqtt broker
    [main.cpp]
2026-08-02 fix: switch CA from Ed25519 to ECDSA due to mbedTLS limitation
2026-08-02 ultimas actualiaciones de la plataforma y documentacion
